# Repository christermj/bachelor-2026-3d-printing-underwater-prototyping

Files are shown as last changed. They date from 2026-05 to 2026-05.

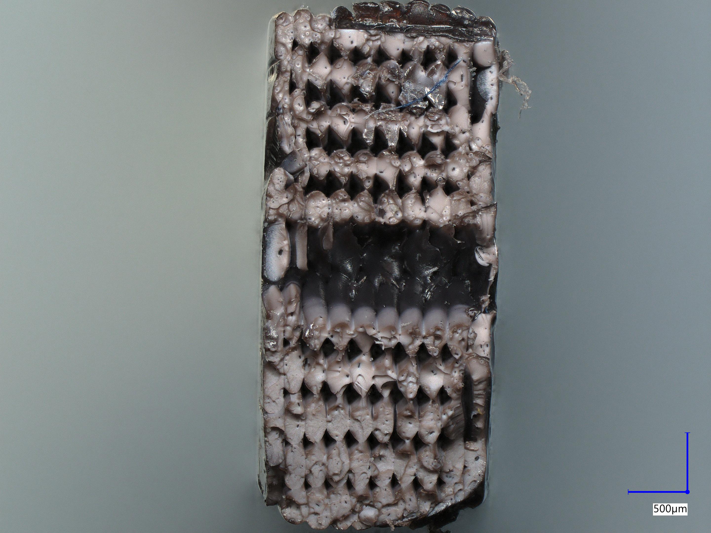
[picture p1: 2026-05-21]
figurer/mikroskopi/ASA 005.jpg

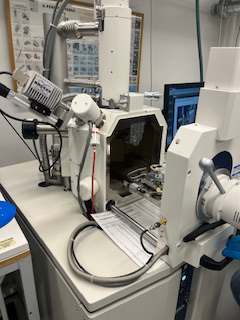
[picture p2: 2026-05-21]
figurer/ekstra/Mikroskopering 6.jpeg

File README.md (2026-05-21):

# Bachelor Oppgave 2026: 3D-Printing i Undervannsmiljøer

## 📚 En helhetlig studie av 3D-printet prototyping for bruk i undervannsmiljøer

**Hovedoppgaven:** [`Bachelor Maskiningeniør 2026.pdf`](./rapport/Bachelor%20Maskiningeni%C3%B8r%202026.pdf)

---

## 👥 Forfattere

- Christer Markussen Jusnes
- Tor Henrik Lehne
- Veronika Hesle
- Emilie Enerhaugen Thrane
- Jonatan Graff Ravnvik

## 🎓 Veiledere

- Karl Thomas Hjelmervik
- Agne Johannessen

## 🤝 Faglig oppfølging & Samarbeid

- **Kongsberg Discovery AS**
  - Robin Heggelund
  - Robert Kovacs

## 🏛️ Institusjon

**Universitetet i Sørøst-Norge (USN)**
- Fakultet for teknologi, naturvitenskap og maritime fag
- Institutt for mikrosystemer

---

## 📋 Abstrakt

Bacheloroppgaven undersøker hvordan FDM-printede polymerer påvirkes av langtidseksponering i saltvann, og hvordan enkle overflatebehandlinger kan redusere vanninntrengning i 3D-printede undervannskapslinger. PLA, PETG og ASA ble testet gjennom strekkprøving, vannopptaksmåling, Arrhenius-analyse, kompresjonstester, overflatebehandling og mikroskopi. Arbeidet er knyttet til utvikling av en 3D-printet elektronikkapsling for undervannsbruk i samarbeid med Kongsberg Discovery AS.

---

## 🔬 Hovedfunn & Resultater

| Funn | Detaljer |
|---|---|
| **ASA - Best materiale** | ASA var det mest stabile materialet ved saltvannseksponering og anbefales som førstevalgsmateriale for videre prototyping i undervannsmiljøer. |
| **PLA degradering** | PLA viste betydelig hydrolytisk degradering og vurderes som lite egnet for marin bruk uten beskyttelse. |
| **PETG kompleks respons** | PETG viste en mer sammensatt respons, med tegn til både degradering og forbedrede mekaniske egenskaper ved høyere temperaturer. |
| **Materialsranking** | Ubehandlede materialer rangert som: **ASA > PETG > PLA** |
| **Termisk glødeeffekt** | Eksponering nær glasstransisjonstemperaturen kan gi en termisk glødeeffekt som forbedrer mekaniske egenskaper, særlig for PETG og ASA. |
| **Best overflatebehandling** | Jotun Vinyl Primer ga best resultat blant overflatebehandlingene, med **0 % masseøkning** i nedsenkningstest. |
| **Tetningskriteria** | Jevn overflatefinish og god pakningskontakt ble vurdert som avgjørende for tetning under hydrostatisk trykk. |
| **Prototypekapsling** | En FDM-printet prototypekapsling ble utviklet som konseptdemonstrator. |

---

## 📁 Filstruktur

```
.
├── README.md                           # Denne filen
├── rapport/Bachelor Maskiningeniør 2026.pdf
│   └── 
├── vedlegg/
│   ├── Vedlegg 1 - Strekkdata grafvedlegg.pdf
│   ├── Vedlegg 2 - Intervju med Olav Håskjold.pdf
│   ├── Vedlegg 3 - Intervju med Magnus Hesle.pdf
│   ├── Vedlegg 4 - Budsjett.pdf
│   └── Vedlegg_strekkmaskin-hastighet_v2.docx
├── data/
│   ├── filament-datablader/
│   │   ├── PLA-datasheet.pdf
│   │   ├── PETG-datasheet.pdf
│   │   └── ASA-datasheet.pdf
│   ├── ekstra/
│   │   ├── Beskrivelse av gjennomføring av veiing.docx
│   │   ├── Beskrivelse av strekktest og registrering av resultater.docx
│   │   ├── Liste over hva vi ser etter under mikroskopering.docx
│   │   ├── Møtereferat Magnus Hesle.docx
│   │   └──  Møtereferat Olav Håskjold.docx
│   ├── Gjennomsnitt strekkprøver.xlsx
│   ├── Vannopptak - masseendring over tid - Tabeller (Diagrammer for vektendring, permanent vektendring og prosentberegning).xlsx
│   ├── arrhenius_graph_endelig_versjon.xlsx
│   └── Lakkering.xlsx
├── figurer/
│   ├── mikroskopi/                     # Mikroskopibilder
│   └── illustrasjoner/                 # Andre bilder og illustrasjoner
└── cad/
    ├── prototypekapsling/              # 3D-modeller av kapslingen
    ├── strekkprøver/                   # 3D-modeller av strekkprøvene
    └── tegninger/                      # 2D tekniske tegninger
```

---

## 📂 Mapper

### 📄 [`rapport/`](./rapport/)
Hovedoppgaven i fullt format

### 📎 [`vedlegg/`](./vedlegg/)
Alle vedlegg til oppgaven:
- Strekkdata grafer (PDF)
- Intervjuer
- Budsjett

### 📊 [`data/`](./data/)
Rådata og datasett:
- **`filament-datablader/`** - Datablader fra produsenter for PLA, PETG og ASA
- **`ekstra/`** - Datafiler som er omarbeidet, strukturert eller brukt som grunnlag
- Strekkprøvedata (gjennomsnitt)
- Lakkerings-data

### 🖼️ [`figurer/`](./figurer/)
Supplerende visuell dokumentasjon fra prosjektet, for eksempel mikroskopibilder og prosjektbilder som ikke nødvendigvis inngår direkte i hovedrapporten

### 🏗️ [`cad/`](./cad/)
CAD-modeller og tekniske tegninger

---

## 🔬 Metodologi

Oppgaven undersøker:
- **FDM 3D-printing** av polymerer
- **Materialer testert**: PLA, PETG, ASA
- **Tester utført**:
  - Strekkprøving
  - Vannopptaksmåling
  - Arrhenius-analyse
  - Kompresjonstester
  - Overflatebehandlinger
  - Mikroskopi
- **Miljø**: Saltvannseksponering (marin miljø)

---

## 🎯 Konklusjon

ASA anbefales som førstevalgsmateriale for ubehandlede 3D-printede undervannsprototyper. Overflatebehandling med Jotun Vinyl Primer viste lovende resultater for ytterligere beskyttelse. PETG kan brukes der duktilitet og enkel produksjon prioriteres. PLA anbefales ikke for langvarig eksponering i saltvann.

---

## 📧 Kontakt

**Forfattere:**
- Christer Markussen Jusnes - christermj@live.no
- Tor Henrik Lehne - thlehne@gmail.com
- Veronika Hesle - veronikahesle@gmail.com
- Emilie Enerhaugen Thrane - emiliethra98@hotmail.com
- Jonatan Graff Ravnvik - jonatan.graff@outlook.com

---

## 📅 Dato

**2026**

---

*Sist oppdatert: 2026-05-19*

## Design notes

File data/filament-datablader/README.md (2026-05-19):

# Filament datablader
Datablader fra 3D filamentprodusenter for PLA, PETG og ASA

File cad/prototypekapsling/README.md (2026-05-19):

# Prototypekapsling folder
CAD-modeller av prototypekapslingen

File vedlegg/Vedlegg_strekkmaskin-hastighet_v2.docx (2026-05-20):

# Vedlegg – Oppsett av strekkprøve maskin

Formålet med disse innledende testene er å identifisere og redusere potensielle problemer i strekkprøveoppsettet før de endelige og begrensede hovedtestene gjennomføres. Siden vi kun har et fastsatt antall prøver tilgjengelig til selve hovedforsøket, er det viktig å bruke fortestene til å avdekke feilkilder, vurdere hvordan materialene reagerer ved ulike hastigheter, og sikre at både testoppsett og prosedyrer fungerer som de skal.

Disse fortestene er derfor planlagt som en utforskende fase hvor vi tester ulike hastigheter, observerer bruddmekanismer og vurderer om testoppsettet gir pålitelige og representative resultater. Målet er å stå igjen med et robust oppsett og et begrunnet valg av strekkhastigheter før vi går videre til de faktiske testene som danner grunnlaget for resultatene i bacheloroppgaven.

Test 1

5 mm/min

PLA | PETG | ASA

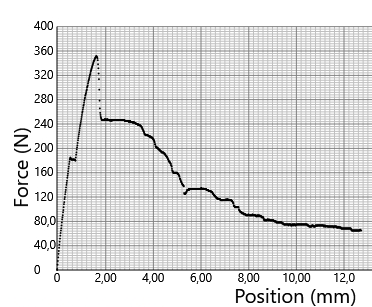
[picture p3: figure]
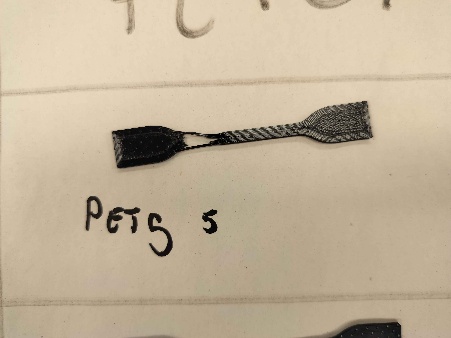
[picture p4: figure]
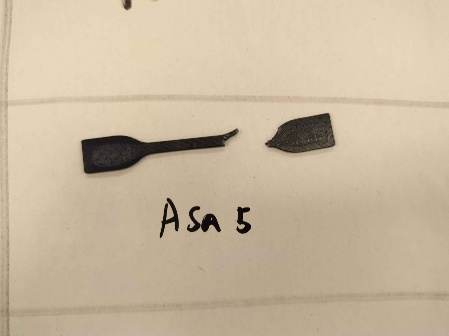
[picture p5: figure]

Ved 5 mm/min viser alle tre materialene tydelig viskoelastisk flyt, noe som resulterer i svært lang forlengelse etter brudd, spesielt for PETG. Den lave hastigheten gir polymerkjeder god tid til å reorganisere seg og gli, noe som fører til en utydelig brudddefinisjon og betydelig plastisk deformasjon. Bruddflatene viser dette tydelig: PLA får et sprøtt og ujevnt brudd, PETG viser kraftig fibrillering og trådtrekk, og ASA viser en blanding av duktil og sprø oppførsel. Resultatene er veiledende siden kun én prøve per materiale ble testet.

25 mm/min

PLA | PETG | ASA

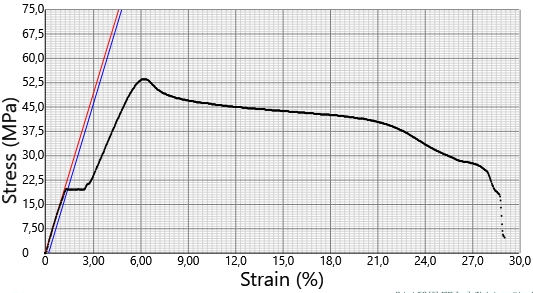
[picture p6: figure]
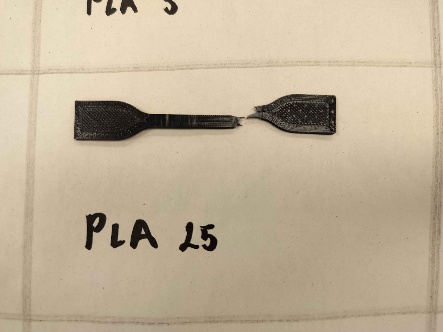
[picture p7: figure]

Ved 25 mm/min reduseres den viskoelastiske flyten noe, men alle materialene viser fortsatt en markert post-yield-region. PLA får en mer definert overgang til brudd, PETG viser fortsatt betydelig kjedeutretting og en flat flytesone, mens ASA viser en mer kontrollert og gradvis deformasjon. Bruddflatene blir noe renere enn ved 5 mm/min, men PETG har fortsatt tydelig fibrillering. Dette understreker at lavere hastigheter gir polymerene tid til å reorganisere seg under belastning. Resultatene er veiledende og basert på én prøve per materiale.

50 mm/min

PLA | PETG | ASA

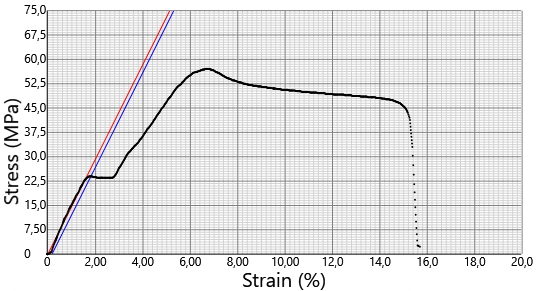
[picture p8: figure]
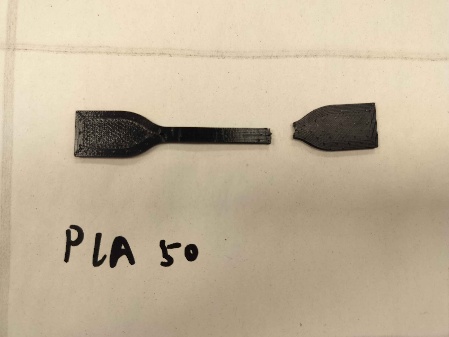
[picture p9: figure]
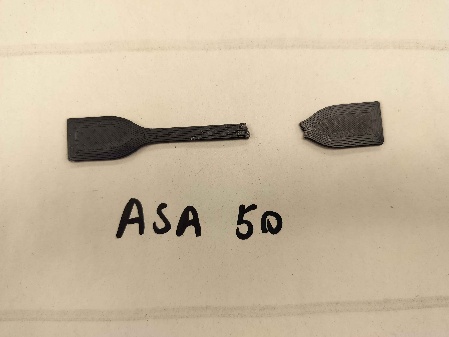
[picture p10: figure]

Ved 50 mm/min oppnås de mest stabile og reproduserbare bruddflatene for alle tre materialene. Stress–strain-kurvene får en tydelig avslutning med klart definert bruddpunkt, og den viskoelastiske flyten er betydelig redusert. PLA viser et rent og sprøtt brudd, PETG får en mer kompakt og mindre fibrillert bruddflate, og ASA viser stabil necking og et homogent brudd. Dette er årsaken til at 50 mm/min ble vurdert som en optimal hastighet for PLA og ASA. Resultatene er veiledende siden kun én prøve per materiale ble testet.

75 mm/min

PLA | PETG | ASA

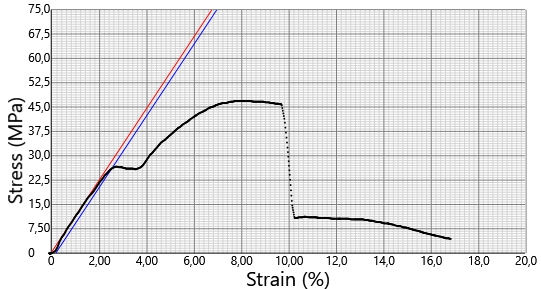
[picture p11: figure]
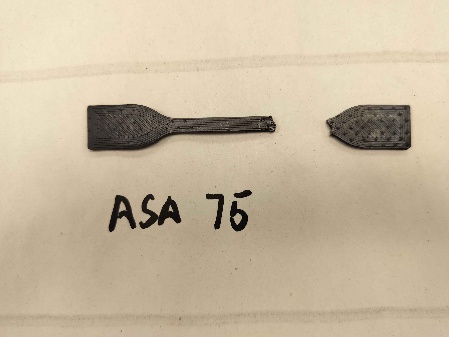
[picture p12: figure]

Ved 75 mm/min viser alle tre materialene en mer markert og konsentrert bruddoppførsel sammenlignet med lavere hastigheter. PLA får et tydelig sprøtt brudd med minimal plastisk deformasjon, PETG viser redusert fibrillering og en mer kompakt bruddflate, og ASA viser stabil necking med en ren og homogen bruddflate. Den høyere hastigheten begrenser tiden polymerkjeder har til å reorganisere seg, noe som gir et mer definert bruddpunkt og mindre etterflyt i kurvene. Resultatene er veiledende siden kun én prøve per materiale ble testet.

100 mm/min

PLA | PETG | ASA

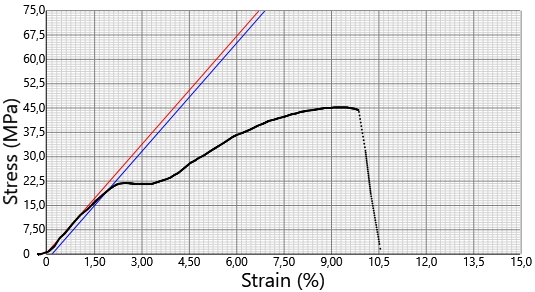
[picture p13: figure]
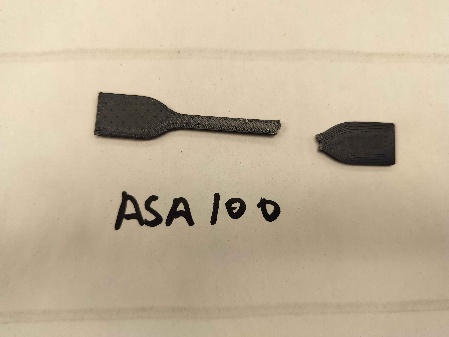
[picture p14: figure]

Ved 100 mm/min oppnår alle materialene et svært tydelig og rent brudd, med minimal viskoelastisk etterflyt. PLA viser et skarpt og sprøtt brudd, PETG får sin mest kompakte og minst fibrillerte bruddflate, og ASA viser en kontrollert necking med et klart definert bruddpunkt. Den høye hastigheten gir en mer “metallisk” kurveprofil med brått fall etter maksimal spenning. Dette understøtter at PETG spesielt responderer positivt på høyere hastigheter når målet er rene bruddflater for mikroskopi. Resultatene er veiledende siden kun én prøve per materiale ble testet.

Oppsummering av Test 1

Test 1 ga en første oversikt over hvordan de tre materialene oppfører seg ved ulike strekkhastigheter, men siden det kun ble testet én prøve per hastighet, var resultatene begrenset i både kvalitet og statistisk verdi. Det som likevel kom tydelig frem, var at de største forskjellene mellom hastighetene oppstod etter brudd, spesielt for PETG, som viste betydelig viskoelastisk etterflyt og fibrillering ved lave hastigheter. Dette gjorde det klart at bruddflatekvalitet måtte vurderes mer systematisk.

I tillegg ble det identifisert en mulig feilkilde knyttet til hvordan prøvene ble holdt fast i strekkmaskinen. Etter diskusjon med Jean Marc ble vi enige om å utvikle en egen jig med formtilpasset uthuling i gripeplatene, slik at bruddet skjer i prøvens midtseksjon og ikke påvirkes av gripetrykk.

Siden Test 1 kun ga grove indikasjoner og ikke et tilstrekkelig grunnlag for å velge endelige hastigheter, ble det besluttet å gjennomføre en ny runde (Test 2) med fokus på bruddflater. Test 2 ble derfor planlagt som et kvalitativt supplement for å se om visuelle forskjeller kunne gi bedre innsikt i hastighetsavhengigheten.

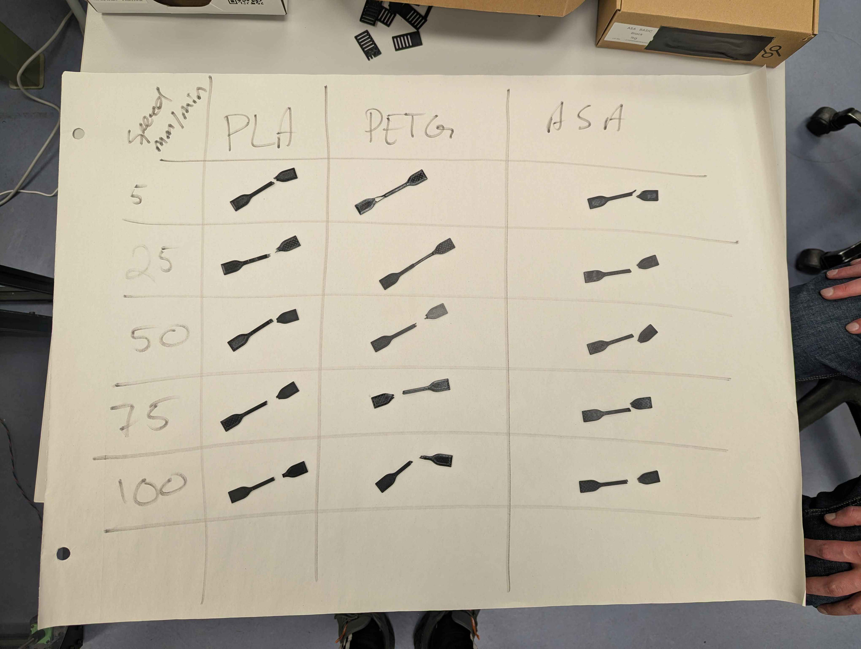
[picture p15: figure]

(BILDE av alle prøvene)

Bilde av potensiell jig (uthuling av plater – ca 1.5mm, som etterlater litt av tykkelsen som stikker ut og gir andre platen et grep mot plasten).

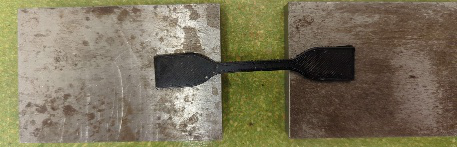
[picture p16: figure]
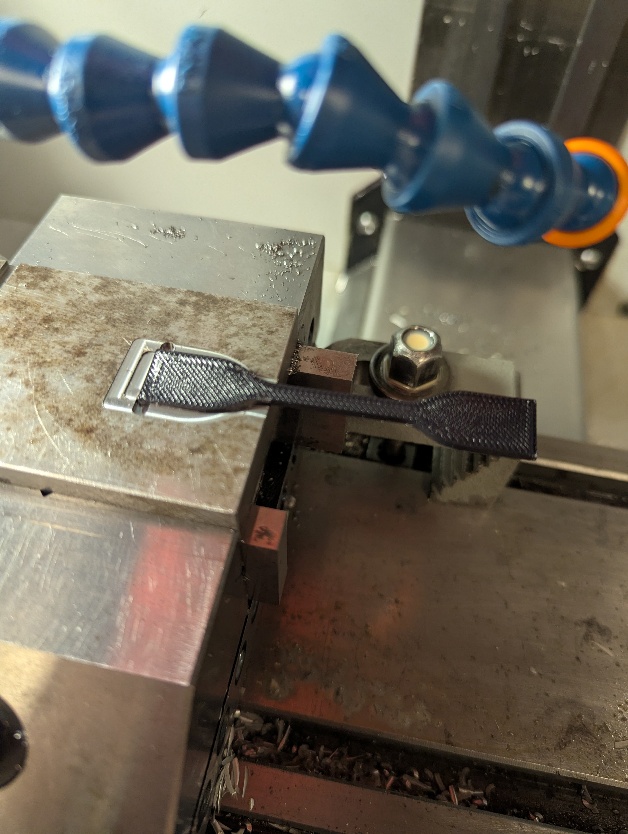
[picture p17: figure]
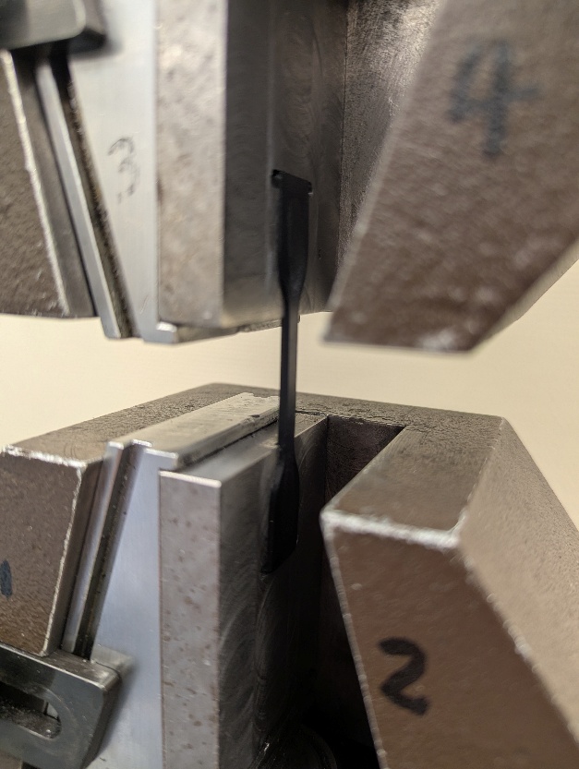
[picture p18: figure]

Strekkprøve test 2

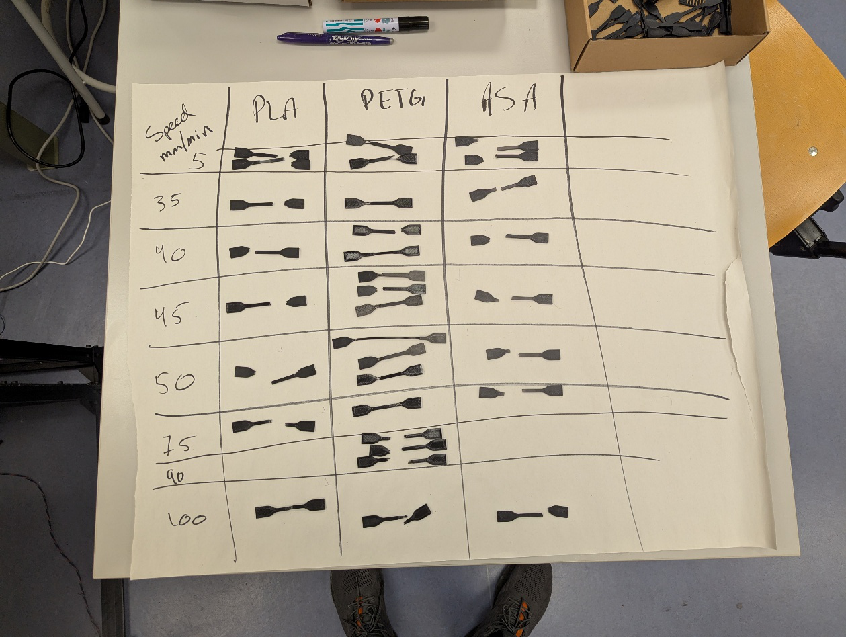
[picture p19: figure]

Test 2 ble gjennomført som en preliminær vurdering av hvordan bruddflater endrer seg med hastighet, med mål om å identifisere hastigheter som gir rene og tolkbare brudd for mikroskopering. Testen ble imidlertid utført med kun én prøve per hastighet og uten tilhørende kraft–forlengelseskurver, noe som gjorde datagrunnlaget svært begrenset. I praksis fungerte Test 2 derfor mer som en orienterende “tulletest” enn som en fullverdig del av kalibreringsprosessen.

Det som likevel ble tydelig, var at PETG oppfører seg langt mer seigt enn PLA og ASA, og at dette materialet ikke utvikler et rent brudd ved lave hastigheter. Dette styrket mistanken om at hvert materiale kunne trenge sin egen optimale testhastighet.

Strekkprøve test 3

På dette tidspunktet ble det funnet en kilde som refererte til ISO 527‑2, hvor standardhastigheten for strekkprøving av polymerer er oppgitt som 10 mm/min ± 25 %. Dette ga et nytt og mer presist rammeverk for videre testing. I stedet for å fortsette med enkeltprøver ved vilkårlige hastigheter, ble det derfor besluttet å gjennomføre Test 3 med fem hastigheter innenfor ISO‑området: 7.5, 8.25, 10, 11.25 og 11.5 mm/min. Målet med Test 3 var å undersøke om dette standardområdet gir mer konsistente kurver og bruddflater, og om ISO‑hastigheten kan fungere som et felles referansepunkt for alle tre materialene.

Test 3 representerer dermed det første forsøket på en strukturert og ISO‑forankret kalibrering av strekkhastighet, og danner grunnlaget for å vurdere om videre testing bør baseres på standardhastigheten eller om hvert materiale krever sin egen optimale hastighet.

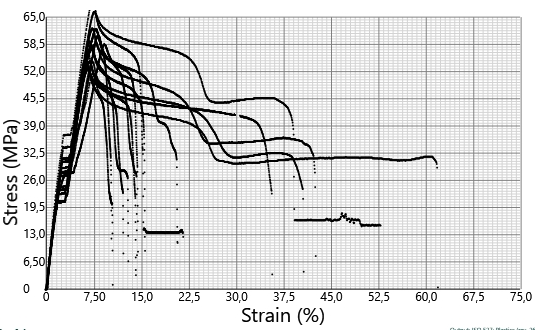
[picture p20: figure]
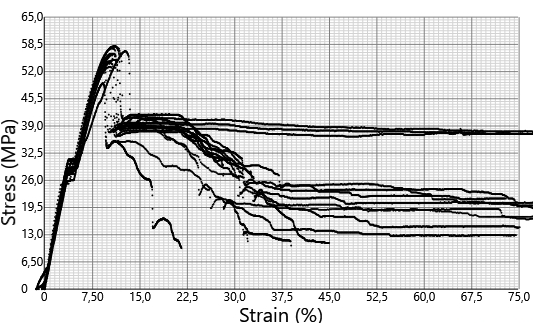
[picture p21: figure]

PLA – 7,5 – 12,5 mm/min | PETG – 7,5 – 12,5 mm/min | ASA – 7,5 – 12,5 mm/min

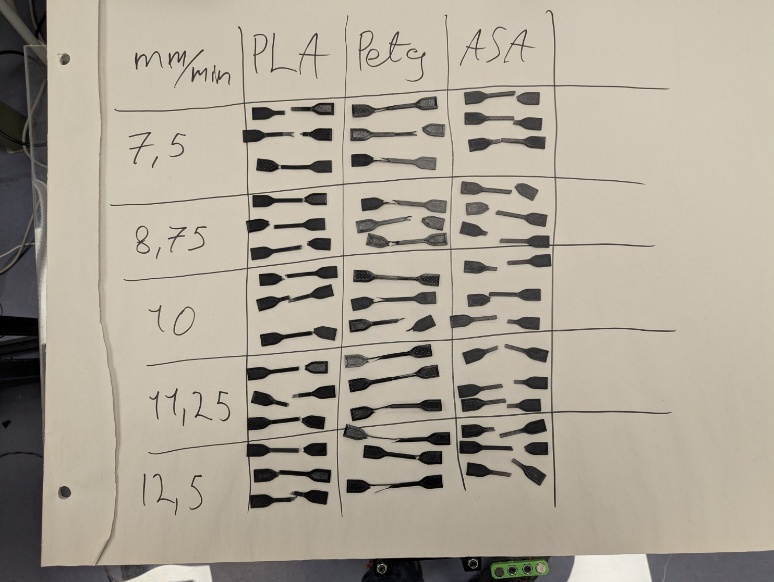
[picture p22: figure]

Bilde av alle strekkprøvene fra test 3

Test 4

Test 4 ble gjennomført for å undersøke hvordan materialene oppfører seg ved et bredere spekter av strekkhastigheter enn det som ble testet i Test 3. Etter Test 3 ble det gjort en nærmere gjennomgang av ISO 527, og det viste seg at standarden ikke angir konkrete hastigheter, men heller beskriver at seige materialer kan strekkes ved høyere hastigheter enn mer sprø materialer som PLA. Dette åpnet for at optimale hastigheter kunne ligge betydelig høyere enn området som ble undersøkt i Test 3.

På bakgrunn av dette ble Test 4 designet for å gradvis øke hastigheten fra 10 mm/min og opp til 90 mm/min, for å kartlegge hvordan PLA, PETG og ASA responderer på høyere belastningshastigheter. Målet var å identifisere hvilke hastigheter som gir stabile og reproduserbare kurver, tydelige bruddpunkter og bruddflater som er egnet for videre mikroskopisk analyse. Som i Test 3 ble det gjennomført tre prøver per hastighet per materiale, slik at resultatene kunne vurderes med tilstrekkelig pålitelighet.

Test 4 representerer dermed den siste og mest omfattende delen av kalibreringsarbeidet, og danner grunnlaget for å fastsette de endelige strekkhastighetene som brukes i hoved forsøket.

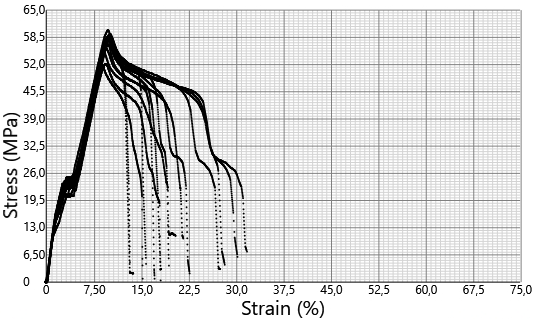
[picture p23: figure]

| PLA – alle hastigheter

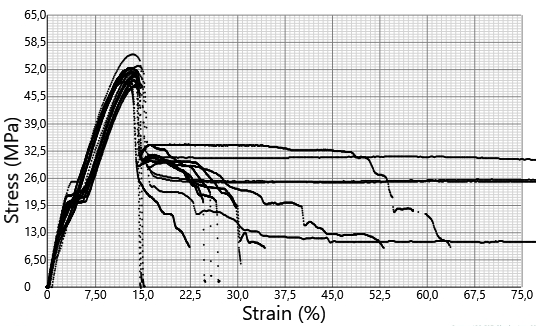
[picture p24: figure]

| PETG – alle hastigheter

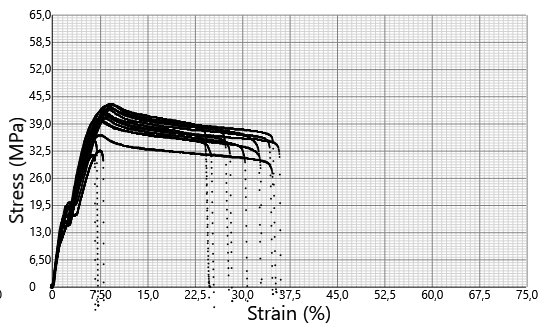
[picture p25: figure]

| ASA – alle hastigheter

Graf 1 er av alle PLA prøver i forskjellige hastigheter som viser at hastigheten ikke har noe å si for e-modulen og maks kraft, kurven ser lik ut.

GRAF 1 – første prototype som startet det hele

Graf 2 viser alle PETG prøvene som viser samme som graf 1.

GRAF 2 – jalla prøver som gav ideen videre

Graf 3 viser like resultater som graf 1 og 2.

GRAF 3 – ISO 527 hastigheter

Konklusjonen fra dette er at hastighet ikke påvirker resultatene, som vil gi oss spillerom å leke med forskjellige hastigheter for å fremkalle «pene brudd» som kan brukes i mikroskopering. Hvis vi ser på test 1 og test 2 vil dette også vise at det er like resultater som ikke er avhengig av hastigheten. Dermed kan vi bruke for eksempel 100mm/min for petg, 45 mm/min for PLA og 50 mm/min for ASA – dette bestemmes etter en nærmere test 4 som tar flere prøver for å forsikre at bruddene er «penest» rundt disse tallene.

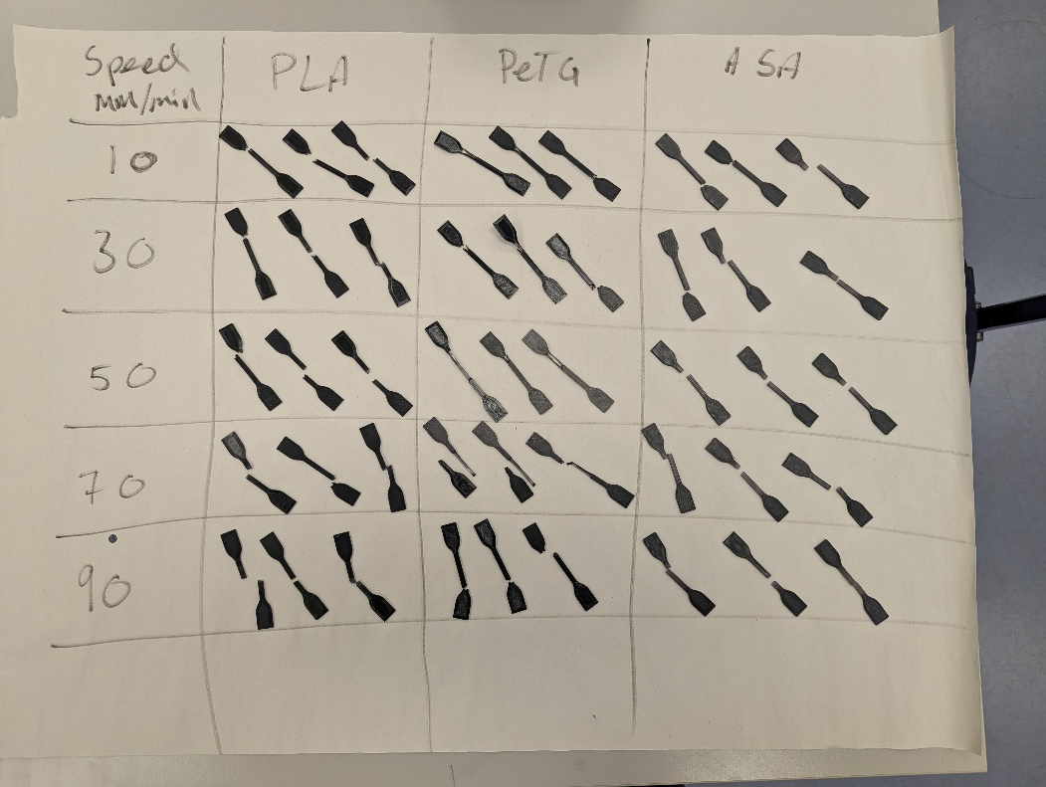
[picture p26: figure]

Test 4 brudd

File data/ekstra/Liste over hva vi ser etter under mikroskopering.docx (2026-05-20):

Overflaterelaterte endringer

Saltrester / krystaller

- Hvite eller kantete avleiringer på overflaten
- Krystaller i porer eller langs laggrenser
- Viktig: må skille mellom faktisk inntrengning og rester etter tørking

Overflateerosjon

- Ruere overflate enn før eksponering
- Matthet / tap av glatt struktur
- Små groper eller mikrodefekter

Endringer i lagstruktur (3D-printet materiale)

- Åpning mellom printlag
- Delaminering
- Økt synlig porøsitet
- Svekket filamentfusjon

Dette kan indikere vanninntrengning eller hydrolytisk svekkelse.

Endringer i bruddflate (etter strekkprøve)

- Mer sprøtt brudd (glatt, skarp flate)
- Mer duktilt brudd (trekkede fibrer, plastisk deformasjon)
- Økt porøsitet i bruddflaten
- Luftlommer som har vokst

Hvis materialet er degradert kan bruddet bli:

- Mer porøst
- Mindre sammenhengende
- Mindre plastisk deformasjon

Intern struktur

- Nye mikrosprekker
- Utvidede eksisterende porer
- Luftlommer som har blitt større
- Kapillærbaner for vanninntrengning

Hva vi vurderer

- Vanninntrengning
- Hydrolytisk nedbrytning
- Svekket lagbinding
- Økt porøsitet
- Endret bruddoppførsel

Analysere prøve i mikroskop:


1 og 2: Se på bruddflater.

3: Lagstruktur, evt. saltpartikler og overflate. Punkt 3 skal sees fra side og ovenfra under mikroskopering.

Prøve ID | Materiale | Temperatur (°C) | Våt/tørr prøve | Overflaterelaterte endringer | Endringer i bruddflate | Intern struktur | Kommentar

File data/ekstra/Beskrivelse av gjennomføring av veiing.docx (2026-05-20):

Beskrivelse av veiing og gjennomføring (Strekktest – vekt)

1) Prøve-ID og inndeling

Hver holder inneholder fem (5) strekkprøver og identifiseres med en Prøve-ID på format:

[Bokstav] – [Temperaturkode] – [Løpenummer]

- Bokstav (materiale): A = PLA, B = PETG, C = ASA
- Temperaturkode (vannbad): 1 = 20 °C, 2 = 40 °C, 3 = 60 °C
- Løpenummer: teller holderne innen samme materiale/temperatur (f.eks. A-1-1, A-1-2, A-1-3 …)

Oddetalls-holdere (…-…-1, …-…-3, …) veies i tre trinn:

1. Startvekt (tørr) før nedsenking
2. Sluttvekt (våt) ved første uttak fra vann
3. Tørrvekt etter 24 t tørk

Partalls-holdere (…-…-2, …-…-4, …) veies normalt uten tørrvekt etter 24 t (kun startvekt + sluttvekt).

2) Holderoppsett og spor-rekkefølge (kritisk for sporbarhet)

Holderen er en flat plate med Prøve-ID på den ene enden og 5 spor der prøvene presses inn.

For å sikre at hver prøve kan spores mellom målinger:

- Spor 1 = prøven som står nærmest Prøve-ID-merkingen
- Deretter fylles spor 2 → spor 5 i rekkefølge bort fra ID-enden.
- Ved veiing følges alltid samme rekkefølge (spor 1 til 5), og verdiene føres i Excel i samme rekkefølge (øverste rad = spor 1, neste rad = spor 2, osv., for den aktuelle Prøve-ID-en).

3) Forberedelser før veiing

- Vekt plasseres stabilt og i trekkfritt miljø.
- Bruk hansker/pinsett for å unngå fett og fukt fra fingre.
- Sørg for at Prøve-ID på holder og vannbad er tydelig merket.

4) Startveiing (tørr vekt før nedsenking)

1. Ta en holder (f.eks. A-1-1) og vei prøvene enkeltvis i rekkefølge spor 1 → spor 5.
2. Før verdiene inn i arket under riktig materiale og temperatur, i kolonnen Startvekt for riktig Prøve-ID.
3. Gjenta for alle holdere som skal legges i vann.

5) Uttak og våtveiing (Sluttvekt)

Når en holder tas opp for måling:

1. Ta opp holderen og la den renne av saltvannet. Prøvene skylles av med rent vann, før de tørkes lett av med tørkepapir.
2. Vei prøvene enkeltvis i rekkefølge spor 1 → spor 5.
3. Før verdiene i kolonnen Sluttvekt for aktuell Prøve-ID, og fyll inn Dato for målepunktet.
4. Sett prøven tilbake i sporet den sto i.

6) Tørking 24 timer og tørrvekt (kun oddetalls-holdere)

For holdere med oddetalls-ID:

1. Etter våtveiing legges prøvene til tørk i et døgn under like forhold for alle. Samme sted/rom, ikke direkte sol, mest mulig lik ventilasjon).
2. Etter et døgn veies prøvene igjen i rekkefølge spor 1 → spor 5.
3. Før verdiene i kolonnen Tørrvekt.

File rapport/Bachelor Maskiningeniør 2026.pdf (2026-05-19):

# En helhetlig studie av 3D-printet prototyping

### Bacheloroppgave

Classification: Internal; TS3000 20 studiepoeng Maskiningeniør – Produktdesign (ING6); Veiledere:

for bruk i undervannsmiljøer

Veronika Hesle, Christer Markussen Jusnes, Tor Henrik Lehne,
Emilie Enerhaugen Thrane, Jonatan Graff Ravnvik

Fakultet for teknologi, naturvitenskap og maritime fag
Institutt for mikrosystemer

Karl Thomas Hjelmervik
Agne Johannessen

Samarbeid med tverrfaglig gruppe – Elektroingeniør (ING3) / Elektronikkingeniør (ING4)

### Sammendrag

Denne bacheloroppgaven undersøker hvordan 3D-printede polymerkomponenter kan brukes i utvikling av prototyper for undervannsmiljøer. Arbeidet er gjennomført i samarbeid med Kongsberg Discovery AS og tar utgangspunkt i behovet for en kapsling som kan beskytte elektronikk for undervannskommunikasjon. Oppgaven omfatter både materialtesting, vurdering av vanninntrengning, overflatebehandling, trykkrelaterte tester og utvikling av en demonstrasjonsprototype for integrering av elektronikk.

Tre filamentbaserte polymermaterialer ble undersøkt: polylaktid/polymelkesyre (PLA), glykolmodifisert polyetylentereftalat (PETG) og akrylnitril-styren-akrylat (ASA). Materialene ble eksponert i kunstig saltvann ved 20, 40 og 60 °C over en periode på opptil tolv uker. Endringer i mekaniske egenskaper ble vurdert gjennom strekkprøving, vannopptaksmålinger og mikroskopi. I tillegg ble det gjennomført en forenklet Arrhenius-analyse for å undersøke temperaturavhengige endringer i materialenes elastisitetsmodul.

Resultatene viser at PLA er mest følsomt for kombinasjonen av saltvann og forhøyet temperatur. Ved 60 °C viste materialet tydelige tegn til degradering og tap av mekaniske egenskaper. PETG viste en mer sammensatt respons, med større variasjon mellom våte og tørre prøver. ASA fremstod som det mest stabile av de tre materialene under de testede betingelsene, med relativt lavt vannopptak og begrensede endringer i mekanisk respons. Mikroskopi støttet disse observasjonene ved å vise tydelige skader og saltavsetninger i enkelte PLA-prøver, mens ASA i hovedsak beholdt en mer stabil struktur.

Det ble også undersøkt hvordan ulike overflatebehandlinger påvirker vanninntrengning i 3D-printede strukturer. Bengalack, to-komponent polyester og Jotun Vinyl Primer ble testet gjennom nedsenkning og trykkrelaterte forsøk. Resultatene indikerer at overflatebehandling kan redusere vanninntrengning, men at tetningsevnen i stor grad avhenger av overflatekvalitet, jevn påføring, pakningskontakt og geometrisk presisjon. Testene viser derfor at belegg alene ikke kan vurderes isolert, men må ses i sammenheng med design av pakningsflater og produksjonskvalitet.

Basert på material- og tettingstestene ble det utviklet en sylindrisk kapsling med et indre bæresystem for batteri og elektronikk. Prototypen fungerer som et konsept for hvordan 3D-printing kan brukes til rask utvikling og tilpasning av undervannsteknologi. Den endelige prototypen ble ikke fullskala trykktestet som ferdig system, og resultatene må derfor tolkes som et grunnlag for videre utvikling, ikke som en ferdig kvalifisert undervannskapsling.

Oppgaven konkluderer med at 3D-printing har tydelig verdi som metode for rask prototyping av undervannskomponenter, men at materialvalg, lagstruktur, overflatebehandling og tetningsdesign er avgjørende for funksjon over tid. ASA fremstår som det mest egnede materialet av de undersøkte alternativene, mens PETG kan være relevant i enkelte bruksområder. PLA vurderes som lite egnet for langvarig eksponering i saltvann, særlig ved forhøyet temperatur. Videre arbeid bør omfatte lengre eksponeringstid, flere trykktester, bedre kontrollert overflatebehandling og fullskala testing av ferdig kapsling under realistiske driftsforhold.

### Forord

Denne bacheloroppgaven er utført våren 2026 ved Institutt for mikrosystemer, Fakultet for teknologi, naturvitenskap og maritime fag, Universitetet i Sørøst-Norge (USN). Oppgaven er gjennomført som del av bachelorprogrammet i ingeniørfag, med Kongsberg Discovery AS som ekstern oppdragsgiver.

Vi retter en særlig takk til våre veiledere, Karl Thomas Hjelmervik og Agne Johannessen, for faglig veiledning, oppfølging og konstruktive tilbakemeldinger gjennom prosjektperioden. Kongsberg Discovery AS takkes for oppdraget, tilgang til informasjon om cNode Mantis-systemet og praktisk tilrettelegging. Vi vil spesielt trekke frem Robin Heggelund og Robert Kovacs ved Kongsberg Discovery for faglige innspill og oppfølging underveis.

Videre ønsker vi å anerkjenne bidragene fra John Inge Waage og laboratorietekniker Hans Bjørge Normann for praktisk bistand med mikroskopi og trykktesting. Jean-Marc Cantin, Truls Arne Frednes, Zekija Ramic og Geir Bjørnsen ved USN har også bidratt med verdifulle faglige innspill og støtte gjennom prosjektet. Håvard Granlund og Petter Andreassen ved Jotun AS takkes for faglige råd og materialstøtte knyttet til overflatebehandlinger.

Prosjektet er gjennomført i samarbeid med en tverrfaglig bachelorgruppe med ansvar for utvikling av kretskort, sensorsystem og tilhørende elektronikk. Samarbeidet har vært viktig for å sikre at mekanisk design, elektronikk og systemintegrasjon ble utviklet i sammenheng.

Arbeidet med oppgaven har gitt gruppen verdifull erfaring innen materialtesting, prototypeutvikling, tverrfaglig samarbeid og vitenskapelig rapportering.

Horten, Mai 2026

Signatur Veronika Hesle | Signatur Jonatan Graff Ravnvik | Signatur Emilie Thrane
Signatur Tor Henrik Lehne | Signatur Christer Markussen Jusnes

### Ordliste og forkortelser

FORKORTELSE | BETYDNING
ASA | Acrylonitrile Styrene Acrylate
DAK | Dataassistert Konstruksjon
FDM | Fused Deposition Modeling
FFI | Forsvarets forskningsinstitutt
IEEE | Institute of Electrical and Electronics Engineers
ISO | International Organization for Standardization
PCB | Printed Circuit Board (kretskort)
PDM | Product Data Management
PETG | Polyethylene Terephthalate Glycol-modified
PLA | Polylactic Acid (polymelkesyre)
SEM | Scanning Electron Microscopy
USN | Universitetet i Sørøst-Norge
UV | Ultrafiolett (stråling)
ABS | Acrylonitrile Butadiene Styrene (akrylnitril-butadien-styren)
NaCl | Natriumklorid (kjemisk forbindelse brukt for å fremstille kunstig sjøvann)
NBR | Nitrilgummi (nitrile butadiene rubber)

### Begreper og definisjoner

BEGREP | DEFINISJON
Anisotropi | Materialegenskaper som varierer med retning. FDM-printede deler er typisk sterkere i XY-planet enn i Z-retningen.
Gløding (annealing) | Termisk etterbehandling under glasstransisjonstem- peraturen som gir polymerkjedene mobilitet til å omorganisere seg, øke krystallinitet og forbedre la- ginterdiffusjon.
Belegg (coating) | Overflatebehandling som hindrer eller reduserer dif- fusjon av vann og ioner inn i underliggende materi- ale.
Bruddflate | Overflaten som oppstår når et prøvestykke brytes. Analyseres for å vurdere bruddtype (sprø, duktil).
C-node Mantis | Akustisk modem fra Kongsberg Discovery for trådløs kommunikasjon under vann.
Tverrbjelke | Den bevegelige tverrbjelken på en strekkmaskin som påfører kraft på prøven.
Duktil brudd | Brudd forut av plastisk deformasjon og innsnevring. Materialet flyter før det sprekker.
Ekstensometer | Instrument som måler tøyning direkte på prøvestyk- ket. Ikke benyttet i dette prosjektet; tverrbjelkebe- vegelse benyttes i stedet.
Elastisitetsmodul | Stigningstallet for den elastiske delen av spennings- tøyningskurven, mål på materialets stivhet.
Tøyning | Prosentvis forlengelse ved brudd, mål på materialets duktilitet.
FDM-printing | Filamentbasert additiv tilvirkning der termoplastisk materiale ekstruderes lag for lag.
Fibrillering | Dannelse av fibre og tråder i bruddflaten, særlig ka- rakteristisk for PETG under strekk.
Flytespenning | Spenningsnivået der materialet begynner å defor- meres plastisk, ofte definert ved 0,2 % plastisk tøy- ning.
Glasstransisjonstemperatur | Temperaturen der amorfe polymerer går fra glass- aktig til gummiaktig tilstand.
Hydrolyse | Kjemisk nedbrytning av polymerkjeder ved reaksjon med vann, særlig relevant for ester-baserte polyme- rer som PLA.
Lagbinding | Binding mellom printlag i FDM-deler. Svakere enn bulkmaterialet og en sentral feilkilde.

Isobart trykk | Belastning der trykket virker likt på alle eksterne fla- ter, slik som i en trykkbeholder.
Innsnevring | Lokal innsnevring av prøvegeometrien etter flyt og før brudd.
Plastisering | Reduksjon av stivhet og flytespenning som følge av at små molekyler (typisk vann) trenger inn i polymer- strukturen og øker kjedemobiliteten.
Semikrystallinsk | Polymer med blanding av ordnede (krystallinske) og uordnede (amorfe) kjedestrukturer.
Tøyningshastighet | Tøyningshastighet under mekanisk test. Påvirker mekanisk respons i viskoelastiske materialer.
Strekkfasthet | Maksimal spenning materialet tåler i strekk før brudd.
Trykkbeholder | Lukket konstruksjon beregnet for å motstå indre el- ler ytre overtrykk.
Viskoelastisitet | Material atferd som kombinerer elastisk og viskøs respons, tidsavhengig deformasjon.
Spraylakk | Aerosol-applisert beskyttelseslakk basert på akryl- harpiks.
To-komponent polyester | Belegg som herdes ved kjemisk reaksjon mellom herder og base.
Jotun Vinyl Primer | Vinyl-basert grunning beregnet for marin bruk.
Akselerert aldring | Forsøksmetode der forhøyet temperatur brukes til å simulere langtidseksponering på kortere tid, basert på Arrhenius-prinsippet.
Aktiveringsenergi | Minimumsenergien som kreves for å starte en kje- misk reaksjon. I Arrhenius-modellen beskriver (Ea) temperaturavhengigheten til degraderingshastighe- ten.
Arrhenius-modellen | Kinetisk modell som beskriver sammenhengen mel- lom reaksjonshastighet og temperatur gjennom ak- tiveringsenergien.
Eksentrisk kompresjon | Ujevn trykkfordeling som oppstår når en pakning be- lastes mot en ujevn overflate, og som kan føre til lek- kasje.
Hydrostatisk trykk | Trykk forårsaket av en væskes vekt, som virker likt i alle retninger på en neddykket gjenstand.
O-ring | Ringformet pakning med sirkulært tverrsnitt, brukt for å oppnå tett forsegling mellom to flater.
Sprø brudd | Brudd uten vesentlig plastisk deformasjon. Bruddet skjer raskt og med liten energiabsorpsjon.

Warping | Deformasjon som oppstår når en 3D-printet del trek- ker seg sammen under avkjøling, slik at hjørner eller kanter løfter seg fra byggeplaten. Fenomenet skyl- des termiske spenninger i materialet og er særlig vanlig ved temperaturfølsomme materialer som ABS og ASA.
Fyllingsgrad | Infill i veggene på 3d-printede modeller, beskrevet med %
Horizon | Programvaren til Strekkmaskin H50KL
Stepdown-modul | DC/DC converter som gjør om spenningen fra 12 volt til 5 volt
Sensor Shield | Sensor løsningen som ble designet av den tverrfag- lige gruppen
Battery Cradle | Modulen som holder batteriet og Stingray-kortet i designløsningen
PCB Cradle | Modulen som holder elektronikken i designløs- ningen
Enkoder-kort | Kretskortet som tar imot bildesignalet fra kameraet og sender det til stingray-kortet
Stingray | Kretskortet som til Kongsberg Discovery som hånd- terer det trådløse signalet igjennom vann
Breadboard | Koblingsbrett som brukes til å teste og bygge elekt- roniske kretser uten lodding
Wago | En fjærbelastet koblingsklemme som brukes til å koble sammen elektriske ledninger uten lodding

### Symboloversikt

NORSK | ENGELSK | SYMBOL
Flytespenning | Offset yield stress (0.2%) | σy0.2
Strekkfasthet | Ultimate Tensile Strength | σB
Elastisitetsmodul | Elastic Modulus | E
Tøyning | Elongation | ε
Glasstransisjonstemperatur | Glass Transition Temperature | Tg
Aktiveringsenergi | Activation Energy | Ea
Temperatur (absolutt) | Temperature (absolute) | T
Degraderingshastighet | Degradation Rate Constant | k

Hydrostatisk trykk | Hydrostatic Pressure | p
Massetetthet (væske) | Fluid Density | ρ
Gravitasjonsakselerasjon | Gravitational Acceleration | g
Dybde | Depth | ℎ

### Figurliste

Figur 2 – cNode Modem MANTIS i aksjon, som viser akustisk/optisk kommunikasjon mellom

Figur 5 – Prinsippskisse av FDM-prosessen, der en termoplastisk filamenttråd mates gjennom et oppvarmet munnstykke og deponeres lagvis på en oppvarmet byggeplattform. Egenprodusert figur. 7 Figur 6 – Prinsippskisse av amorf og semikrystallinsk polymerstruktur. Egenillustrert, basert på

Figur 15 – Oppsett til varmekammer. a) Oppsett av hvordan prøvene ligger organisert i glassene, b)

Figur 16 – Etter at prøvene ble tatt opp ble de systematisert etter materiale, om prøvene var våte eller

Figur 30 – Røde markeringer viser områdene som skal undersøkes. Punkt 1 og 2 viser bruddflatene, som skal analyseres med fokus på bruddmekanismer og materialstruktur. Punkt 3 undersøkes med

Figur 42 – Understativ for Stepdown modulen. a) Understativ, b) Stepdown modul montert | 51
Figur 43 – Test av festemekanisme | 51
Figur 44 – Battery Cradle | 52
Figur 45 – PCB Cradle. a) Forside av PCV Cradle med spor for encoderkort og step-down-modul, b)
Bakside av PCB Cradle med spor for Sensor Shield | 53
Figur 46 – Lokk. a) Toppen av lokket, b) Undersiden av lokket | 53
Figur 47 – Sylinder | 54
Figur 48 – Sammenstilling Exploded view | 54
Figur 49 – skisser på mulig lufteventilløsning | 55
Figur 50 – skisse av sett skrue for låsing | 56
Figur 51 – skisse av plastsplint for låsing | 56
Figur 52 – Eksploded view med blylodd | 58
Figur 53 – Dykkerklokke | 61
Figur 54 – Klokkereim | 61
Figur 55 – Sensorplassering | 62
Figur 56 – Strekkfasthet (σB) over eksponeringstid for PLA, PETG og ASA i kunstig sjøvann ved 20, 40
og 60 °C. a) tørr tilstand, b) Våt tilstand | 64
Figur 57 – Elastisitetsmodul (E) over eksponeringstid for PLA, PETG og ASA i kunstig sjøvann ved 20, 40
og 60 °C. a) Tørr tilstand, b) Våt tilstand | 64
Figur 58 – Flytespenning (σF) over eksponeringstid for PLA, PETG og ASA i kunstig sjøvann ved 20, 40
og 60 °C. a) Tørr tilstand, b) Våt tilstand | 65
Figur 59 – Prosentvis endring i elastisitetsmodul etter tolv ukers eksponering for prøver | 67
Figur 60 – Prosentvis endring i strekkfasthet etter tolv ukers eksponering for prøver | 67
Figur 61 - Gjennomsnittlig vektendring målt direkte etter eksponering for PLA ved 20 °C, 40 °C og 60 °C
fra uke 3 til uke 12 | 69
Figur 62 – Arrhenius-plott for PLA basert på E-modul etter tre ukers aldring. Plottet viser
temperaturintervallene 20-40 °C og 40-60 °C for våte og tørre prøver | 70
Figur 63 – Arrhenius-plott for PETG basert på E-modul etter tre ukers aldring. Plottet viser
temperaturintervallene 20-40 °C og 40-60 °C for våte og tørre prøver | 71
Figur 64 – Arrhenius-plott for ASA basert på E-modul etter tre ukers aldring. Plottet viser
temperaturintervallene 20-40 °C og 40-60 °C for våte og tørre prøver | 71
Figur 65 – Testresultater for radiell belastning | 73
Figur 66 – Testobjekter etter radiell test | 73
Figur 67 – Testresultater for aksial belastning | 74
Figur 68 – Testobjekter etter aksiell test | 74
Figur 69 – Prosentvis masseøkning for PLA etter én uke i vanneksponering med de ulike
overflatebehandlingene | 75
Figur 70 – Prosentvis masseøkning for PETG etter én uke i vanneksponering med de ulike
overflatebehandlingene | 76
Figur 71 – Prosentvis masseøkning for ASA etter én uke i vanneksponering med de ulike
overflatebehandlingene | 76
Figur 72 – Boks for nedsenkningstest. a) Boks med flat gummipakning, b) Boks med flat
gummikorkpakning, c) Boks med 5 mm O-ring i lokket | 77
Figur 73 – Ubehandlet vannintrengningstest delt i to | 78
Figur 74 – Ujevnheter i overflatebehandling. a) Manglende dekning av overflatebehandling på siden av
lokket, b) Manglende dekning av overflatebehandling på siden av boksen | 78
Figur 75 – kollapset testboks | 79
Figur 76 – Trykkgraf fra trykkammeret for FDM-printet sylinder forseglet med vinylprimer | 80
Figur 77 – Trykkgraf fra trykkammeret for FDM-printet sylinder forseglet med to-komponent polyester.
| 81

Figur 78 – Trykkgraf fra trykkammeret for FDM-printet sylinder forseglet med Bengalack | 81
Figur 79 – PLA ved 60°C i 3 uker, prøven er skylt. Grønne sirkler markerer saltkrystaller. Optisk
mikroskopi hos Kongsberg Discovery | 82
Figur 80 – PLA ved 60°C i tolv uker, prøven er skylt. Grønne sirkler markerer saltkrystaller. Optisk
mikroskopi hos Forskningsparken | 83
Figur 81 – PLA ved 60°C i 3 uker, prøven er skylt. Grønne sirkler markerer saltkrystaller. Optisk
mikroskopi hos Forskningsparken | 83
Figur 82 – PLA ved 40°C i 12 uker, prøven er skylt. Større mengde saltkrystaller observeres mellom printlagene. Grønne sirkler markerer saltkrystaller. Optisk mikroskopi hos Kongsberg Discovery...... 84 Figur 83 – PLA ved 60°C i 3 uker viser printlag med jevne luftrom og lagvis oppbygging med relativt lik
struktur. Optisk mikroskopi ved Forskningsparken | 85
Figur 84 – PLA ved 40°C i tolv uker. Blå markering viser at lagene er tettere og hvite piler viser steder
det er større hulrom mellom printlagene. Optisk mikroskopi ved Kongsberg Discovery | 85
Figur 85 – PLA etter tolv uker ved 60°C. SEM-bilde viser sprekker på overflaten og mellom printlagene. Røde bokser markerer områder som er vist som forstørrede utsnitt. Hvit markering angir områder hvor
det er sprekker. SEM ved Kongsberg Discovery | 86
Figur 86 – PLA etter tolv uker ved 60°C. SEM-bilde viser sprekker på indre struktur og mellom printlagene. Røde bokser markerer områder som er vist som forstørrede utsnitt. Hvit markering angir
ulike sprekkåpninger. Optisk mikroskopi ved Kongsberg Discovery | 86
Figur 87 – PLA etter 3 uker ved 60°C. Viser trinnvise brudd i plasten. Optisk mikroskopi ved
Forskningsparken | 87
Figur 88 – PLA etter tolv uker ved 60°C. Bruddflaten fremstår rettvinklet og jevn. Optisk mikroskopi ved
Kongsberg Discovery | 87
Figur 89 – PLA ved 60°C i tolv uker. Det observeres flere små, sorte plastpartikler i glassbeholderen.
| 88
Figur 90 – PLA etter ni uker ved 60°C. Prøvene viser brudd ved håndtering | 88
Figur 91 – PLA etter tolv uker ved 60°C. Det observeres løse plastpartikler på underlaget Eksempler er
markert med blå sirkel | 88
Figur 92 – PETG etter tre uker ved 60°C (skylt). Grønne markeringer viser saltkorn på overflaten. Optisk
mikroskopi ved Forskningsparken | 89
Figur 93 – PETG etter tolv uker ved 60°C (skylt). Grønne markeringer viser saltkorn på overflaten. Optisk
mikroskopi ved Forskningsparken | 89
Figur 94 – PETG etter tre uker ved 60°C (skylt). Grønne markeringer viser saltkorn i bruddet. Optisk
mikroskopi ved Forskningsparken | 90
Figur 95 – PETG etter tolv uker ved 60°C (skylt). Røde bokser markerer områder som er vist som forstørrede utsnitt. Hvite områder viser saltkorn i bruddet. Optisk mikroskopi ved Forskningsparken.
| 90
Figur 96 – PETG etter tolv uker ved 20°C. Det observeres løse filamenttråder og skader på siden av plastpinnen. Røde firkanter markerer områder som er forstørret i utsnittene. Optisk mikroskopi ved
Forskningsparken | 91
Figur 97 – PETG-prøver eksponert ved 60°C etter strekkprøving ved uke 3, 6, 9 og 12. Våte prøver viste
seigere oppførsel enn tørkede prøver, som i større grad utviklet fullstendig brudd | 92
Figur 98 – ASA etter 3 uker ved 60°C (skylt). Små mengder saltkorn observeres mellom printlagene. Grønne markering viser saltkorn mellom printlagene. Optisk mikroskopi ved Forskningsparken....... 93 Figur 99 – ASA etter tolv uker ved 60°C (skylt). Begrenset forekomst av saltkorn observeres mellom printlagene. Grønne markering viser saltkorn mellom printlagene. Optisk mikroskopi ved
Forskningsparken | 93
Figur 100 – ASA etter tolv uker ved 60 °C (skylt). Ingen synlige saltrester observeres i den indre
strukturen. Optisk mikroskopi ved Kongsberg Discovery | 94

Figur 101 – ASA etter tolv uker ved 60 °C (ikke skylt). Denne prøven skiller seg fra de øvrige ASA-prøvene ved å vise tydelig saltinntrengning og store mengder saltkrystaller mellom printlagene. Optisk
mikroskopi ved Kongsberg Discovery | 94
Figur 102 – ASA-prøve etter tolv uker ved 60 °C. Optisk mikroskopibilde av ASA-prøve som viser ruglete
kantstruktur langs ytterkanten etter eksponering. Optisk mikroskopi ved Forskningsparken | 95
Figur 103 – ASA (sort). Optisk mikroskopibilde som viser mørke partikler i materialets overflatestruktur. Grønne markereringer viser observerte partikler i materialet. Optisk mikroskopi ved Kongsberg
Discovery | 96
Figur 104 – ASA (sort). I den indre strukturen observeres sorte prikker. Røde firkanter markerer
områder som er forstørret i utsnittene. Optisk mikroskopi ved Kongsberg Discovery | 96
Figur 105 – ASA (sort). Detaljbilde av indre struktur og partikler ved høyere forstørrelse, observert med
optisk mikroskopi ved Kongsberg Discovery | 97
Figur 106 – ASA (sort). Tilsvarende område vist som fargekart, der blå farge indikerer lavere høyder og
rød indikerer høyere områder. Optisk mikroskopi ved Kongsberg Discovery | 97
Figur 107 – ASA (grå). Indre struktur med lavere forekomst av sorte partikler sammenlignet med sort
ASA. Optisk mikroskopi ved Kongsberg Discovery | 97
Figur 108 – ASA (hvit). I den indre strukturen ser man kun ett par små sorte prikker. Grønne sirkler
markerer sorte prikker. Optisk mikroskopi ved Kongsberg Discovery | 98
Figur 109 – ASA. Prøvestaver etter brudd ved ulike eksponeringstider (uke 0, 3, 6, 9 og 12) ved 60 °C.
Brudd oppstår i samme område for samtlige prøver | 99
Figur 110 – ASA ved 60°C i tolv uker. Det observeres små, sorte plastpartikler i glassbeholderen. .... 99 Figur 111 – Termografi bilde av byggeplaten til Bambu X1C. Skala på høyre side av hvert a og b er
temperatur. a) Temperaturer uten IR-bilde overlagt, b) Temperaturer med IR-bilde overlagt | 110
Figur 112 – Termografibilde av byggeplaten til Prusa MK3s. Skala på høyre side av hvert a og b er
temperatur. a) Temperaturer uten IR-bilde overlagt, b) Temperaturer med IR-bilde overlagt | 110
Figur 113 – Printmiljøet for Prusa MK3 | 111
Figur 114 – Printmiljøet for Bambu X1C | 111

### Tabelliste

Tabell 1 – Samlet oversikt over omtrentlige glasstransisjonstemperaturer (Tg) og typiske

Tabell 2 – Komparativ oversikt over kritiske termodynamiske, kjemiske og barrierespesifikke

Tabell 10 – Viser tabelloppsett som ble gjort i Microsoft Excel for plotting av ln(k) mot 1000/T ........ 40

Tabell 13 – Viser utregnede verdier for aktiveringsenergi basert på stigningstall fra plottene og verdier

# Innholdsfortegnelse

1 Innledning | 1
1.1 Bakgrunn | 2
1.2 Mål og omfang | 2
1.3 Tverrfaglig samarbeid | 2
1.4 Problemstilling | 3
1.5 Avgrensninger | 3
1.6 Formidling av prosjektet | 4
2 Teoretisk grunnlag | 6
2.1 cNode Mantis: akustisk dataoverføring under vann | 6
2.2 FDM 3D-printing | 7
2.3 Materialteori (PLA, PETG, ASA) | 8
2.4 Viskoelastisitet, flyt og mekanisk oppførsel under strekking | 14
2.5 Degradering og vannopptak i saltvann | 14
2.6 Trykk og dimensjonering | 17
2.7 Overflatebehandlinger | 19
2.8 Pakninger og vanntetting | 21
3 Metode | 22
3.1 Produksjon av prøvestykker | 22
3.2 Utstyr brukt for strekkprøver | 23
3.3 Prøveforberedelse og eksponering | 26
3.4 Strekkprøving etter ISO 527 | 30
3.5 Beleggapplikasjon og inntrengingstest | 32
3.6 Kompresjon- og hydrostatisk test | 34
3.7 Mikroskopi | 39

3.8 Fremgangsmåte for Arrhenius-analyse | 40
3.9 Lekkasjetesting av sylindriske testobjekter sylindere | 41
4 Design og utvikling | 43
4.1 Kravspesifikasjon elektronikkinnpakning | 44
4.2 Konseptutvikling | 46
4.3 Valg av løsning | 52
4.4 Dimensjonering av veggtykkelse | 59
4.5 Demonstrasjonsprototype for sensorintegrasjon | 61
5 Resultater | 63
5.1 Strekkegenskaper over tid | 63
5.2 Vannopptak - masseendring over tid | 68
5.3 Arrhenius-analyse | 70
5.4 Kompresjonsprøver | 73
5.5 Innledende evaluering av overflatebehandlinger | 75
5.6 Nedsenkningstester av konteinere | 77
5.7 Trykktest ved 3 bar | 79
5.8 Mikroskopi | 82
6 Diskusjon | 100
6.1 Egnethet av ubehandlet PLA, PETG og ASA for marin bruk | 100
6.2 Evaluering av strukturell integritet og tetningsevne under hydrostatisk trykk (3 bar) | 104
6.3 Mikroskopi-observasjoner | 106
6.4 Kobling mellom delresultater og prototype-design | 108
6.5 Avvik og feilkilder | 109
7 Konklusjon | 113
7.2 Hovedfunn | 114
7.3 Anbefaling | 115
8 Videre arbeid | 116
9 Bruk av kunstig intelligens | 117

10 Kilder | 118
11 Appendiks | 123
11.1 Appendiks A: Digitalt prosjektarkiv | 123
11.2 Appendiks B: Vurderingskriterier og observasjonsskjema | 125
11.3 Appendiks C: Testmatrise | 127
11.4 Appendiks D: Tegninger av prototype | 128
11.5 Appendiks E: Bruddoppførsel i PETG | 134

# 1 Innledning

Norges kystlinje strekker seg over 100 000 kilometer når øyer og fjorder inkluderes, og både forsvar, havbruk, petroleumsindustri og forskning er avhengig av pålitelig teknologi som fungerer under vann. Overvåking av havbunnsinstallasjoner, autonome sensornettverk og undervannskommunikasjon stiller strenge krav til utstyr som må tåle korrosivt saltvann, hydrostatisk trykk og begrenset tilgang for vedlikehold. Tradisjonelt har slike komponenter ofte blitt fremstilt i maskinert metall, noe som kan gi høy kostnad og lang ledetid for prototyper.

3D-printing åpner for rask og rimelig prototypeproduksjon, men introduserer samtidig nye utfordringer når komponentene skal brukes i marine miljøer. Lagvis oppbygning kan gi porøsitet og svake grenseflater, samtidig som polymermaterialer kan påvirkes av saltvann, temperatur og mekanisk belastning over tid. For å vurdere om 3D-printede polymerkomponenter kan benyttes i undervannsapplikasjoner, må materialenes langtidsoppførsel og tetningsevne dokumenteres systematisk.

Kongsberg Discovery utvikler det akustiske modemet C-node Mantis for trådløs dataoverføring under vann (se Figur 1). Systemet benyttes blant annet til navigasjon, posisjonering og overføring av sensordata mellom undervannsenheter og overflateinstallasjoner (se Figur 2). I samarbeid med Kongsberg Discovery og en tverrfaglig prosjektgruppe ved USN undersøkes muligheten for å tilpasse Mantis-plattformen til en ny brukerkontekst. Målet er at dykkere skal kunne benytte teknologien til kommunikasjon og dataoverføring under operasjoner.

Figur 1 – cNODE Mantis akustisk videomodemsystem [1].


Figur 2 – cNode Modem MANTIS i aksjon, som viser akustisk/optisk kommunikasjon mellom undervannsplattform og eksterne moduler [2].

## 1.1 Bakgrunn

Det finnes publiserte studier av 3D-printede polymerer og miljøeksponering, men det er fortsatt behov for mer dokumentasjon på hvordan mekaniske egenskaper, vannopptak og overflatebehandling påvirker funksjonen over tid. Mange studier fokuserer hovedsakelig på korttidseksponering eller enkeltparametere som for eksempel strekkfasthet. I mindre grad undersøkes den samlede påvirkningen disse faktorene har på komponentens funksjonalitet over tid. Det mangler også studier som kombinerer akselerert aldring ved ulike temperaturer med praktisk testing av vanntetting for 3D-printede deler.

Denne oppgaven bidrar til å fylle dette kunnskapsgapet gjennom testing av tre polymermaterialer i saltvann, gjennom systematisk saltvannseksponering over tolv uker ved tre temperaturer. Videre evalueres enkle belegg og det utvikles en funksjonell prototypekapsling.

## 1.2 Mål og omfang

Det overordnede målet med bacheloroppgaven er å undersøke om 3D-printede polymerer er egnet som funksjonelle prototyper i undervannsapplikasjoner. Det undersøkes hvordan materialvalg, utforming og overflatebehandling påvirker komponentenes motstand mot hydrostatisk trykk og langvarig saltvannseksponering.

Arbeidet er organisert langs tre hovedretninger. Den første retningen fokuserer på mekanisk styrke og materialdegradering i tre utvalgte polymermaterialer. Materialene testes gjennom strekkprøving, vannopptaksmåling og Arrhenius-analyse etter eksponering i saltvann ved ulike temperaturer. Den andre retningen undersøker barriereegenskaper, der enkle belegg testes for å vurdere om de kan hindre vanninntrengning i 3D-printede strukturer. Den tredje retningen er utvikling av en funksjonell prototypekapsling for det akustiske modemet cNode Mantis, basert på resultater fra materialtestene.

## 1.3 Tverrfaglig samarbeid

Prosjektet er gjennomført som et tverrfaglig samarbeid mellom to bachelorgrupper ved USN. Vår gruppe, bestående av fem maskiningeniørstudenter, har hatt hovedansvaret for materialvalg, mekanisk testing, vanntetting og utvikling av kapslingsdesign. Den samarbeidende gruppen bestod av elektronikkingeniørstudentene Don Phillip Torres Bullecer, Alexander Rivrud Belmonte og Robin André Holen, samt elektroingeniørstudent Magnus Andrew Rømo. Denne gruppen hadde ansvar for utvikling av sensorsystemet, inkludert kretskort og signalbehandling. Gruppene samarbeidet tett gjennom prosjektperioden for å sikre at elektronikken kunne integreres i kapslingens indre volum. Grensesnittet mellom gruppene ble definert gjennom en felles kravspesifikasjon for innvendig montering, komponentplassering og kontaktpunkter.

## 1.4 Problemstilling

Hvordan påvirker langvarig saltvannseksponering ved ulike temperaturer de mekaniske egenskapene og funksjonaliteten til 3D-printede polymerkomponenter i undervannsapplikasjoner?

For å besvare dette undersøkes følgende delspørsmål:

1. Hvordan påvirkes strekkfasthet, elastisitetsmodul og flytespenning i de utvalgte polymermaterialene etter opptil tolv ukers eksponering i kunstig saltvannsløsning ved 20, 40 og 60 °C?
2. I hvilken grad kan ulike overflatebehandlinger redusere vanninntrengning i 3D-printede komponenter under trykktesting?
3. Kan en 3D-printet prototypekapsling oppfylle grunnleggende krav til beskyttelse av elektronikk ved operasjonsdybde?

## 1.5 Avgrensninger

Materialvalget er avgrenset til tre lett tilgjengelige polymerer som er mye brukt til å 3D-printe prototyper. De konkrete materialene presenteres og begrunnes i kapittel 2.3. Eksponeringsperioden er satt til tolv uker. Forhøyede temperaturer ved 40 og 60 °C benyttes som akselerert aldring for å fremskynde temperaturavhengige endringer og gi grunnlag for Arrhenius-basert vurdering av langtidsutvikling. Resultatene representerer likevel ikke en fullskala levetidstest under reelle driftsforhold. Valg av overflatebehandlinger er begrenset til Bengalack spray, to-komponent polyester og Jotun Vinyl Primer, i tillegg til ubehandlede referanseprøver.

O-ringer og presspasninger er ikke et hovedundersøkelsesområde i oppgaven. En presspasning på 15 prosent er valgt basert på faglige anbefalinger fra Kongsberg Discovery, og standard ingeniørlitteratur er lagt til grunn fremfor egne målinger på dette området.

Kompresjonstestene benytter to-punkts belastning og er ment som en innledende validering av veggtykkelse, ikke som en fullskala isobar trykktest.

Trykktesten er gjennomført på små sylindriske bokser, ikke på fullskala prototype. Den endelige prototypen er en demoenhet og har ikke overflatebehandling eller blitt trykktestet i denne studien.

Resultatene er begrenset til materialene, printparameterne og testbetingelsene som inngår i studien, og kan derfor ikke generaliseres til alle 3D-printede polymerkomponenter eller marine bruksmiljøer.

For å avgrense prosjektet etter faktiske behov og rammer ble det gjennomført semistrukturerte intervjuer av eksterne aktører. Faglige innspill fra det uavhengige forskningsinstituttet Norner (6.10.2025) som forsker på plastmaterialer ble brukt som grunnlag for valg av materialer til testing.

For å undersøke relevante bruksområder og operative krav ble det gjennomført intervjuer med en subsea-ingeniør, Magnus Hesle (11.02.2026), og en militær yrkesdykker, Olav Håskjold (10.03.2026). Innspillene viste at løsningen ikke var egnet for dype operasjoner på 100-200 meters dybde, men mer aktuelt for bruk på 10-20 meters dybde. Dette førte til en avgrensning av prosjektet mot grunnere anvendelser.

Den militære yrkesdykkeren vurderte konseptet som særlig relevant i operasjoner der dykkeren arbeider under vann uten kontakt med mannskap på overflaten. Dersom funksjon og pålitelighet kan dokumenteres, kan løsningen dekke et behov som militæret kan ha interesse av å ta i bruk.

## 1.6 Formidling av prosjektet

Gjennom prosjektperioden har gruppen deltatt på flere demonstrasjoner og presentasjoner i samarbeid med Kongsberg Discovery. Demonstrasjonene ga både representanter fra Kongsberg Discovery og eksterne besøkende mulighet til å få innblikk i prosjektets mål, tekniske løsninger, utviklingsprosess og praktiske anvendelsesområder. Arrangementene fungerte også som en viktig arena for faglige tilbakemeldinger, spørsmål og videre diskusjoner rundt prosjektets utvikling. Ved den siste demonstrasjonen fikk prosjektet også interesse og mediedekning fra NRK (se Figur 3).


Figur 3 – utdrag av nyhetssending fra NRK [3]

Innledende konseptdemonstrasjon (Mars 2026)

Den første demonstrasjonen, avholdt ved Skipperstua i Horten, fokuserte på prosjektets planlagte metodikk og utviklingsprosess. Gruppen presenterte materialvalg, testprotokoller, planlagt kapslingsarkitektur samt innledende planer for funksjonstesting. De fremmøtte fikk også inspisere det eksperimentelle oppsettet for akselerert aldring i kunstig sjøvann. Demonstrasjonen resulterte i verdifulle faglige tilbakemeldinger knyttet til det forventede bruksmiljøet og de hydrostatiske belastningene kapslingen ville utsettes for, noe som ga viktige føringer for det videre designarbeidet.

Midtveisdemonstrasjon av prototype (Mars 2026)

Den andre demonstrasjonen fokuserte på videre utvikling av kapslingens oppbygning og arkitektur. Gruppen presenterte resultater fra testene som var gjennomført så langt, samt hvilke løsninger og materialer som hadde fungert best. Under demonstrasjonen ble det også vist frem en 3D-printet prototype av kapslingen som de fremmøtte fikk mulighet til å undersøke nærmere. Demonstrasjonen ble gjennomført ved Skipperstua i Horten.

Avsluttende systemdemonstrasjon (April 2026)

Den avsluttende demonstrasjonen ble gjennomført ved Indre Havn i Horten og markerte ferdigstillingen av prosjektets utviklingsfase. Tre studentgrupper og en studentorganisasjon viste frem sine prosjekter. For å demonstrere det tverrfaglige aspektet ved prosjektet, ble arrangementet gjennomført i tett samarbeid med den tverrfaglige gruppen. Sammen presenterte gruppene den ferdige prototypekapslingen med fullt integrert sensorelektronikk og batterisystem montert i det indre stativet.

Materialvalg, testresultater og designvurderinger ble presentert. Arrangementet samlet representanter fra Kongsberg Discovery, Forsvarets forskningsinstitutt og Universitetet i Sørøst-Norge (USN). Den faglige og offentlige interessen for prosjektets teknologiske løsninger resulterte i betydelig mediedekning, inkludert artikkel i NRKs nettavis [4], samt reportasje i lokalavisen Gjengangeren [5].


Figur 4 – Stor interesse på demo 3, ved Kongsberg Discovery

# 2 Teoretisk grunnlag

Dette kapittelet presenterer det teoretiske grunnlaget for oppgaven. Først beskrives cNode Mantis-systemet som utgangspunkt for prototypekapslingen, etterfulgt av FDM-printprosessen og dens innvirkning på mekaniske egenskaper. Deretter gjennomgås materialteori for PLA, PETG og ASA, viskoelastisk oppførsel under strekk. Kapittelet tar også for seg degraderingsmekanismer og vannopptak i saltvann inkludert Arrhenius-modellen. Til slutt presenteres teori knyttet til trykk og dimensjonering av sylindriske strukturer, overflatebehandlinger og pakningsdesign for vanntetting.

## 2.1 cNode Mantis: akustisk dataoverføring under vann

Kongsberg Discovery sin C-node Mantis er et kompakt akustisk modem beregnet på trådløs dataoverføring mellom undervannsenheter. Systemet benyttes til kommunikasjon, navigasjon og overføring av sensordata, og er opprinnelig utviklet for bruk mellom ROV-er, sensornoder og overflateinstallasjoner [2].

I dette prosjektet undersøkes muligheten for å tilpasse Mantis-plattformen til en dykker-kontekst. For at systemet skal være praktisk anvendelig i et slikt bruksscenario, må elektronikken kapsles i en innretning som tåler langvarig saltvannseksponering og det hydrostatiske trykket ved operasjonsdybde..

### 2.1.1 Krav til undervannskapsler for elektronikk

En kapsling beregnet på å beskytte elektronikk under vann må oppfylle flere krav. Det mest grunnleggende er vanntetthet: kapslingen må motstå hydrostatisk trykk ved operasjonsdybden uten lekkasje gjennom vegger, skjøter eller pakningsflater. Ved 20 meters dybde tilsvarer dette et ytre overtrykk på omtrent 2 bar [6], noe som stiller krav til både veggtykkelse, geometri og pakningsdesign.

Materialet må i tillegg tåle langvarig eksponering for saltvann uten at mekaniske egenskaper degraderes til et nivå der strukturell integritet ikke lenger kan opprettholdes. For FDM-printede komponenter er dette særlig relevant fordi den lagvise oppbygningen introduserer porøsitet og svake laggrenser som kan akselerere vanninntrengning og degradering sammenlignet med bulkmaterialet.

Kapslingen må også være kompatibel med pakningsløsningen. O-ringer i NBR-gummi, krever jevne kontaktflater og kontrollert presspasning for å oppnå pålitelig forsegling. FDM-printede overflater har iboende ruhet fra lagstrukturen [7], og overflatebehandling kan være nødvendig for å oppnå tilstrekkelig flathet i pakningssporet.

For dykkerhåndtert utstyr er det i tillegg praktiske begrensninger knyttet til vekt, størrelse og håndterbarhet. Kapslingen må kunne betjenes med hansker, tåle støt under transport, og være enkel å åpne og lukke for tilgang til elektronikken. Disse kravene har lagt premissene for materialvalg, dimensjonering og testprogram i denne oppgaven. Den prosjektspesifikke prioriteringen av kravene er beskrevet i kravspesifikasjonen i kapittel 4.1.

## 2.2 FDM 3D-printing

Fused Deposition Modeling (FDM) er en additiv tilvirkningsmetode der en termoplastisk filamenttråd mates gjennom en oppvarmet dyse, smeltes og legges ned lagvis på en byggeplate, som vist i Figur 5. Geometrien bygges opp ved at materialet ekstruderes langs bestemte baner i hvert lag, før byggeplattformen eller munnstykket forskyves i høyderetningen for neste lag. Etter deponering avkjøles materialet og stivner, samtidig som det etableres binding mellom tilstøtende ekstruderte strenger og mellom påfølgende lag. Den ferdige delen består derfor av en laminertstruktur, der mekaniske egenskaper påvirkes av blant annet materialvalg, printtemperatur, lagtykkelse, fyllingsgrad, printhastighet og orientering under printing [7].


Figur 5 – Prinsippskisse av FDM-prosessen, der en termoplastisk filamenttråd mates gjennom et oppvarmet munnstykke og deponeres lagvis på en oppvarmet byggeplattform. Egenprodusert figur.

Binding mellom lag utvikles gjennom en sintringsprosess drevet av termisk energi fra det semi-smeltede materialet. Når det smeltede materialet ekstruderes og kommer i kontakt med foregående lag, smelter de to lagene sammen ved kontaktflaten. Deretter dannes en halsformasjon (neck growth) gjennom viskøs sintring, og molekyldiffusjon over grenseflaten styrker bindingen ytterligere [7]. Kvaliteten på denne bindingsprosessen er kritisk for delens endelige mekaniske egenskaper.

FDM-printede deler inneholder mikroskopiske hulrom mellom filamentsporene og mellom lag, samt restspenninger fra ujevn avkjøling. Disse defektene fører til at mekaniske egenskaper blir sterkt anisotrope, det vil si avhengige av belastningsretning i forhold til lagoppbyggingen. Styrken er typisk høyest når belastningen er parallell med laggrensene (XY-planet) og lavest når belastningen virker vinkelrett på laggrensene (Z-retning) [7].

## 2.3 Materialteori (PLA, PETG, ASA)

De tre materialene som undersøkes i dette prosjektet, PLA (Polylaktid, polylactic acid / polylactide), PETG (polyethylene terephthalate glycol-modified) og ASA (akrylnitril-styren-akrylat), er valgt på bakgrunn av deres utbredelse i forbrukermarkedet og deres forskjellige egenskaper for undervannseksponering. Sammen representerer disse tre materialene ulike polymerklasser med forskjellig molekylær struktur og grad av krystallinitet (se kapittel 2.3.1).

PLA er et av de mest brukte materialene for FDM-printing og er kjent for sin bioplast-opprinnelse [8]. Materialet er lett tilgjengelig, relativt rimelig og kan printes ved lavere temperaturer enn flere andre tekniske termoplaster. PLA er også kjent for god printbarhet og lav tendens til deformasjon under printing, noe som gjør materialet mye brukt til prototyper og enkle komponenter. Samtidig påvirkes de mekaniske egenskapene i FDM-printede PLA-deler av prosessparametere som lagtykkelse, fyllingsgrad og byggeorientering [9].

PETG er et mye brukt alternativ til PLA og har generelt lavere stivhet og høyere bruddtøyning enn PLA, noe som gir en mer duktil materialoppførsel [10]. Materialet benyttes også i applikasjoner der komponenter kan eksponeres for fuktighet eller vann, noe som gjør PETG relevant for FDM-printede deler i fuktige miljøer eller undervannsmiljøer [11].

ASA er en termoplast som ofte brukes i utendørs strukturelle applikasjoner på grunn av mekanisk stabilitet og god værbestandighet. Materialet er særlig relevant for komponenter som kan utsettes for UV-eksponering, ettersom ASA kombinerer mekanisk styrke med motstand mot fargeendring ved langvarig UV-påvirkning. I tillegg har ASA moderat termisk og kjemisk bestandighet, og en glasstransisjonstemperatur på omtrent 100 °C [12].

### 2.3.1 Amorf og semikrystallinsk polymerstruktur

I motsetning til små molekyler som vann eller metan, som vanligvis er enten fullstendig krystallinske i fast fase eller fullstendig amorfe i flytende fase, har polymerer en mer kompleks strukturell oppbygning. På grunn av deres store molekylstørrelse og kjedelengde kan polymerkjedene kun delvis ordne seg i regulære krystallinske strukturer. De fleste polymerer er derfor semikrystallinske, der krystallinske områder eksisterer spredt i et amorf, uordnet materiale [13, Kap. 4].

Som vist i Figur 6 består amorfe områder av polymerkjeder som er uordnet orientert, med tilfeldige bøyer, kveiler og sammenflokinger som hindrer regelmessig pakking. Krystallinske områder oppstår der molekylkjedene har klart å ordne seg i parallelle og tettpakkede strukturer. Fordi polymerkjedene er lange og fleksible, vil knekk, vridninger og feilorienteringer mellom kjedesegmenter kunne danne amorfe områder. Dette gjør fullstendig krystallinitet praktisk vanskelig å oppnå for de fleste polymerer [13, Kap. 4].


Figur 6 – Prinsippskisse av amorf og semikrystallinsk polymerstruktur. Egenillustrert, basert på beskrivelse av polymerers amorfe og krystallinske områder i [13, Kap. 4].

klKrystallinitetsgraden i polymerer varierer fra helt amorf til nesten fullstendig krystallinsk, der opptil omtrent 95 prosent av materialet kan være krystallinsk. Dette står i kontrast til metaller, som nesten alltid er helt krystallinske, og mange keramiske materialer, som enten er fullstendig krystallinske eller fullstendig amorfe. Semikrystallinske polymerer kan betraktes som analoge til tofaselegerede metaller, der to distinkte faser eksisterer side om side [13, Kap. 4].

Tettheten til en polymer er direkte påvirket av krystallinitetsgraden. Krystallinske regioner har høyere tetthet enn amorfe regioner fordi molekylkjedene er tettere pakket sammen. Denne forskjellen kan utnyttes til å bestemme krystallinitetsgraden ved nøyaktige tetthetsmålinger, basert på ligning 4.8 i [13, Kap. 4]

Krystallinitetsgraden påvirkes av flere faktorer. Kjemisk enkle polymerer som polyetylen og polytetrafluoroetylen krystalliserer lett, mens polymerer med komplekse repetisjonsenheter motstår krystallisering. Avkjølingshastigheten under størkningsprosessen er også kritisk: langsom avkjøling gir polymerkjedene tid til å ordne seg i krystallinske strukturer, mens rask avkjøling fryser kjedene i uordnede, amorfe konfigurasjoner [13, Kap. 4].

For FDM-printede deler er dette relevant, ettersom prosessen innebærer oppvarming, ekstrudering og avkjøling av polymermaterialet. Materialets krystallinitet kan derfor knyttes til både polymerens molekylstruktur og den termiske historikken under prosessering [13, Kap. 4], [14]. Lineære polymerer har generelt større mulighet for å krystallisere fordi det er færre strukturelle hindringer for kjedeinnretting. Forgreinede polymerer får redusert krystallinitet fordi sidekjedene forstyrrer regelmessig pakking. Nettverkspolymerer og kryssbundne polymerer er vanligvis nesten helt amorfe, fordi kryssbindingene hindrer polymerkjedene i å reorganisere seg til en krystallinsk struktur, selv om enkelte kryssbundne polymerer kan være delvis krystallinske [13, Kap. 4].

### 2.3.2 PLA

PLA er en biologisk nedbrytbar termoplast syntetisert fra melkesyre-monomerer. Melkesyre produseres industrielt gjennom bakteriell fermentering av fornybare karbohydratkilder som hvete, mais, sukkerrør og sorghum [8]. Repetisjonsenheten for PLA består av en metylgruppe, en karbonylgruppe og en ester-binding [15].

PLA har en glasstransisjonstemperatur (Tg) på omtrent 60 til 65 °C [15], [16], [17]. Moetazedian et al.
[16] målte Tg til 63,4 °C for kommersielt PLA-filament (NatureWorks polylactide 4043D). Slavković et al. [17] bestemte Tg til 65 °C ved hjelp av dynamisk mekanisk termisk analyse (DMTA) for FDM-printet PLA. Denne temperaturen markerer overgangen fra en stiv, glassaktig tilstand til en gummiaktig tilstand der kjedemobiliteten øker kraftig og materialets strukturelle integritet reduseres. PLA sitt smeltepunkt (Tm) ligger typisk rundt 180 °C [15].

Kommersielt PLA-filament er semikrystallinsk [15]. I FDM-printing resulterer imidlertid den raske ekstrusjon og avkjøling i at polymerkjedene ikke får tilstrekkelig tid til å ordne seg i krystallinske strukturer under solidifisering. Spoerk et al. [18] dokumenterte at FDM-printede PLA-komponenter oppnår tilnærmet amorf struktur sammenlignet med det semikrystallinske utgangsmaterialet.

Mekanisk sett har semikrystallinsk PLA en elastisitetsmodul på omtrent 3 GPa og en strekkfasthet på 50 til 70 MPa [15]. For FDM-printede deler er de mekaniske egenskapene sterkt påvirket av printparametere som lagtykkelse, fyllingsgrad, printretning og ekstrusjonstemperatur. Rodríguez-Panes et al.
[9] dokumenterte at fyllingsgraden har størst innflytelse på strekkfasthet, mens lagtykkelse dominerer bruddforlengelsen.

PLA sin ester-binding i hovedkjeden gjør materialet følsomt for hydrolytisk degradering [19]. Vannmolekyler kan reagere med ester-bindingene og føre til kjedebrudd, noe som gradvis reduserer molekylvekten og dermed de mekaniske egenskapene [19], [20]. Denne hydrolysemekanismen er temperaturavhengig og akselereres ved forhøyede temperaturer [19]. I marint miljø kan UV-stråling og oksygen ytterligere akselerere hydrolysen [20]. En mer detaljert diskusjon av hydrolytisk degradering i marint miljø presenteres i kapittel 2.5.2.

### 2.3.3 PETG

PETG er en glykolmodifisert variant av polyetylentereftalat (PET). Modifikasjonen innebærer at en andel av etylenglykol-enhetene i PET erstattes med sykloheksan dimetanol (CHDM) gjennom kopolymerisering. Den større CHDM-enheten forstyrrer den regulære kjedestrukturen og forhindrer krystallisering, noe som resulterer i et amorft materiale. PETG forblir amorft når CT-innholdet (sykloheksan dimetanol tereftalat) ligger mellom 32 og 62 prosent [21].

PETG har en Tg på omtrent 80°C og et Tm rundt 220 til 250°C [22]. Smeltepunktet for PET ligger på 265°C [13, Kap. 12]. Den reduserte krystalliniteten i PETG sammenlignet med PET skyldes tilsetningen av CHDM-enheter [21].

I motsetning til PLA er PETG generelt amorft i sin kommersielle filamentform [23]. Den glykolmodifiserte strukturen forhindrer krystallisering under normale prosesseringsforhold, noe som gir materialet god prosesserbarhet og lav tendens til warping under FDM-printing [21]. PETG kan absorbere fuktighet fra omgivelsene, og fuktinnhold i materialet kan føre til hydrolytisk degradering under lagring og prosessering. Hydrolytisk degradering kan påvirke strekkegenskapene til FDM-printede deler [24], mens tørking av PETG-filament før printing er vist å kunne forbedre både overflatekvalitet og mekaniske egenskaper i printede prøver [25].

PETG viser høyere bruddforlengelse enn PLA, men FDM-prosessen reduserer denne betydelig [26]. Printeparametere som lagtykkelse og fyllingsgrad påvirker de mekaniske egenskapene [22].

Som amorf polymer responderer PETG annerledes på termisk etterbehandling enn semikrystalline polymerer som PLA. Ved gløding over glasstransisjonstemperaturen får polymerkjedene økt mobilitet, noe som forbedrer laginterdiffusjon uten å indusere krystallinitet. Bhandari et al. [26] dokumenterte at gløding av FDM-printet PETG ved temperaturer over Tg forbedret strekkfasthet mellom lagene betydelig, med 10 til 22 prosent økning i mekaniske egenskaper for rent PETG. Stojković et al. [22] fant at optimal gløding ble oppnådd ved 60 °C i 90 minutter, betydelig under Tg for å unngå deformasjon. I motsetning til PLA, der gløding både forbedrer laginterdiffusjon og øker krystallinitet, er effekten av gløding på PETG primært knyttet til forbedret molekylær diffusjon over lag grensene [26].

### 2.3.4 ASA

ASA er en amorf termoplast som ble utviklet som et mer værbestandig alternativ til ABS (akrylnitrilbutadien-styren). Materialet har god UV-bestandighet og langvarig fargestabilitet, og brukes derfor ofte i utendørs komponenter, elektronikkhus og andre applikasjoner der mekanisk stabilitet og værbestandighet er viktig [12].

Tg for ASA er omtrent 100 °C [12], betydelig høyere enn både PLA (60–65 °C) [16], [17] og PETG (~80°C) [22]. Dette gjør ASA mer relevant enn PLA og PETG i applikasjoner der komponenter kan eksponeres for forhøyede temperaturer. Samtidig er ASA et termisk sensitivt materiale i FDM-printing, der kammertemperatur og prosessparametere kan påvirke lagbinding og mekaniske egenskaper [27].

Ved væskeeksponering viste ASA god mekanisk stabilitet i destillert vann, eddiksyre og hydrogenperoksid under de testede betingelsene. Materialet ble imidlertid tydeligere påvirket av sterkere løsemidler, særlig konsentrert isopropanol og aceton, og bør derfor ikke omtales som generelt motstandsdyktig mot alle alkoholer eller løsemidler [28].

ASAs mekaniske egenskaper er sammenlignbare med ABS, men materialet har bedre vær- og UV-bestandighet [12]. Palička et al. [12] viste at ASAs mekaniske respons er temperaturavhengig, der økt temperatur gir redusert flytespenning og mer duktil materialoppførsel. Dette er relevant for komponenter som kan eksponeres for varierende temperaturer under bruk, ettersom både styrke og deformasjonsegenskaper kan endres med temperatur.

Ved FDM-printing av ASA er termisk kontroll viktig for å oppnå stabile mekaniske egenskaper og god lagbinding. ASA printes vanligvis ved 240-270 °C, med oppvarmet byggeplate på 90-110 °C og uten aktiv delkjøling ifølge eSUNs datablad [29]. Et lukket kabinett er særlig relevant for ASA, fordi stabil omgivelsestemperatur kan redusere raske temperaturfall mellom lagene og dermed begrense risikoen for termiske spenninger, warping og delaminering. Tan et al. [27] fant at en kammertemperatur på omtrent 50 °C ga høyest strekkfasthet og slagseighet for ASA-prøver produsert med FDM.

Tabell 1 – Samlet oversikt over omtrentlige glasstransisjonstemperaturer (Tg) og typiske dysetemperaturer for PLA, PETG og ASA ved FDM-printing.

POLYMER | Tg (°C) | DYSETEMPERATUR (°C)
PLA | Ca. 60-65 | Ca. 190-220
PETG | Ca. 80 | Ca. 220-250
ASA | Ca. 100 | Ca. 240-270

### 2.3.5 Gløding og termisk eksponering

Gløding er en termisk etterbehandling der polymerer holdes ved en forhøyet temperatur over en gitt tid, ofte nær eller over materialets glasstransisjonstemperatur, men under temperaturer der materialet mister geometrisk stabilitet. Hensikten er å gi polymerkjedene økt mobilitet, slik at indre spenninger kan reduseres og materialstrukturen kan reorganiseres. For FDM-printede deler kan gløding dermed påvirke både mekaniske egenskaper og dimensjonsnøyaktighet, men effekten avhenger av materiale, temperatur, eksponeringstid og lagtykkelse [22].

For delvis krystallinske polymerer, som PLA, kan gløding føre til økt krystallinitet, noe som kan forbedre stivhet og varmebestandighet. Samtidig kan prosessen gi dimensjonsendringer eller deformasjon dersom temperatur og tid ikke kontrolleres godt nok. Stojković et al. [22] undersøkte gløding av PLA, PETG og karbonfiberforsterket PETG ved ulike temperaturer, tider og lagtykkelser, og viste at både mekaniske egenskaper og dimensjonsendringer påvirkes av glødeparameterne. Studien fant også at lagtykkelse hadde stor innvirkning på strekkfastheten, og at optimal glødetemperatur var materialavhengig.

Flere studier viser at gløding kan gi forbedringer i mekaniske egenskaper for FDM-printede materialer, men resultatene varierer mellom materialtyper og testmetoder. Valvez et al. [30] undersøkte PETG og PETG-baserte kompositter og fant at gløding påvirket blant annet hardhet, bøyestyrke, slagstyrke, spenningsrelaksasjon og krypoppførsel. Samtidig viste studien at både temperatur og eksponeringstid kan gi dimensjonsendringer, noe som gjør prosesskontroll viktig ved termisk etterbehandling. Szust og Adamski [31] viste også at termisk gløding kunne øke styrken i FDM-printede PLA-deler, mens svært store forbedringer i Z-retning for PETG ble oppnådd med en separat metode, saltassistert omsmelting, og ikke med ordinær gløding alene.

Effekten av termisk eksponering avhenger av forholdet mellom eksponeringstemperatur og materialets Tg. Ved temperaturer nær eller over Tg øker polymerkjedemobiliteten, noe som kan bidra til strukturell reorganisering og spenningsreduksjon. Dersom materialet samtidig eksponeres for fuktighet eller vann, kan forhøyet temperatur også akselerere degraderingsmekanismer, for eksempel hydrolytisk nedbrytning. For materialer med lav Tg, som PLA (60-65 °C) [16], [17], kan eksponering ved temperaturer rundt eller over derfor gi konkurrerende effekter mellom mulig forbedret lagbinding, økt krystallinitet og termisk eller hydrolytisk nedbrytning. For materialer med høyere Tg, som PETG (~80 °C) [22] og ASA (100-105 °C) [12], kreves høyere temperaturer for at glødingseffekten skal bli tydelig.

## 2.4 Viskoelastisitet, flyt og mekanisk oppførsel under strekking

Polymerer er viskoelastiske materialer, i motsetning til metaller som vanligvis beskrives som tilnærmet lineært elastiske ved lave belastningsnivåer før flyt. Viskoelastisitet innebærer at den mekaniske responsen avhenger av både belastningens størrelse og hastigheten den påføres med. Dette betyr at en polymer som utsettes for rask belastning kan oppføre seg stivere og sprøere enn samme polymer belastet saktere, der tiden gir polymerkjedene større mulighet til å bevege seg, gli og reorganisere seg [13, Kap. 8].

Dette skiller seg fra metaller som testes etter ISO 6892-1 [32], der standarden omhandler strekkprøving av metalliske materialer ved romtemperatur. For FDM-printede polymerer påvirkes den mekaniske responsen i tillegg av lagstrukturen. Svakere binding mellom lag og mikroskopiske hulrom kan gi anisotrope og reduserte mekaniske egenskaper sammenlignet med konvensjonelt produserte polymere komponenter [33]. Belastningshastigheten kan også påvirke strekkegenskapene til FDM-printede termoplaster, ettersom slike materialer viser belastningshastighetsfølsomhet under mekanisk testing [34].

Strekkhastighetens påvirkning på denne oppførselen er betydelig. Ved høyere strekkhastighet får polymerkjedene kortere tid til å gli og orientere seg, noe som kan føre til høyere tilsynelatende stivhet og mer sprø bruddoppførsel. Ved lavere strekkhastighet får kjedene mer tid til gradvis orientering og deformasjon, noe som kan gi større plastisk tøyning før brudd, mer uttalt innsnevring og en mer duktil bruddflate [13, Kap. 8], [34].

## 2.5 Degradering og vannopptak i saltvann

Degradering av polymermaterialer påvirkes av flere faktorer, blant annet materialstruktur, miljø og temperatur. I dette delkapittelet presenteres sentrale degraderingsmekanismer for polymerer i saltvann, med utgangspunkt i materialene PLA, PETG og ASA. Temperatur har også en stor betydning for degraderingsprosessen og vannopptaket, noe som gjør at det kan knyttes til akselerert aldring og Arrhenius-modellen.

### 2.5.1 Akselerert aldring

Polymerer gjennomgår en nedbrytningsprosess over tid når de utsettes for ulike miljøforhold. Denne nedbrytningen kan forårsake irreversible endringer i materialets egenskaper. For å kunne forutse hvilke endringer som utvikler seg over lengre tid, benyttes akselerert aldring. Dette er en testmetode hvor materialer utsettes for forhøyet temperatur, fuktighet, stråling eller andre eksterne faktorer som bidrar til en raskere nedbrytning [35]. Når både temperatur og fuktighet påvirker materialets degradering, kalles dette hydrotermisk aldring. Akselerert aldring er relevant for å kunne si noe om estimert levetid og materialets ytelse over tid [36].

### 2.5.2 Mekanismer for degradering

Polymerer som eksponeres for marine miljøer påvirkes av flere faktorer som kan føre til akselerert degradering av materialet. For å studere slike forhold under kontrollerte betingelser, benyttes ofte kunstig sjøvann fremstilt på laboratorium i henhold til utviklede standarder. Dette gir mulighet for å gjennomføre identiske tester gjentatte ganger under like forutsetninger. På den måten sikres det reproduserbare resultater [37].

Materialet kan påvirkes av fysiske faktorer som temperaturendringer og UV-stråling. I tillegg kan kjemiske påvirkninger bidra til degradering, som kan skje gjennom prosesser som oksidasjon, hydrolyse og økt saltinnhold. Videre kan materialets egenskaper ha en betydning for hvordan degraderingen forløper, som kjemisk struktur og tilsetningsstoffer [38]. Tidligere studier [39] viser at hydrolyse er en sentral påvirkningsmekanisme for PLA, spesielt når materialet påvirkes av vann og varme. Hydrolysen av PLA forutsetter at vann diffunderer gjennom materialet, hvor diffusjonen skjer lettere i de amorfe delene av polymeren. Den hydrolytiske nedbrytningen skjer i esterbindingene, noe som resulterer i kjededeling og videre degradering av materialet. Graden av vanndiffusjon vil derfor påvirke degraderingshastigheten.

En konsekvens av hydrolysen er at nedbrytningen fører til redusert molekylvekt og en økende andel kortere polymerkjeder. Disse korte kjedene kan lettere gli forbi hverandre, noe som kan gjøre materialet mykere og mer fleksibelt i starten av degraderingsprosessen. Etter hvert som molekylvekten reduseres ytterligere, vil de mekaniske egenskapene svekkes, og materialet kan blisprøtt og miste styrke [39].

PETG inneholder også estergrupper, men sammenlignet med PLA har materialet høyere slagfasthet og viser en mer stabil struktur mot saltvannsindusert nedbrytning. På grunn av sin mer hydrofobe karakter har PETG lav vannabsorbsjon, noe som bidrar til at hydrolytisk degradering skjer langsommere enn i PLA. Dette gjør PETG mer egnet til marine applikasjoner hvor materialet utsettes for fukt og sjøvann over tid. Langvarig miljøeksponering som UV-stråling og temperatur kan også påvirke degraderingsprosessen til materialet [40].

ASA er en termoplast som er utviklet for utendørs bruk og viser god motstand mot UV-stråling og andre miljøpåvirkninger. Materialet har en høy styrke og viser god stabilitet over lengre tid, uten betydelig tap av mekanisk ytelse i marine miljøer med høy fuktighet og saltinnhold. I motsetning til PLA og PETG oppstår det ikke hydrolytisk degradering i samme grad i ASA. Materialet påvirkes av UV-stråling og fotokjemisk degradering ved langvarig eksponering [40].

### 2.5.3 Temperaturens effekt på degradering

Temperatur er en viktig faktor som påvirker degraderingshastigheten til polymerer. Økt temperatur vil normalt føre til høyere reaksjonshastighet og akselererte degraderingsprosesser som hydrolyse og termisk aldring. Høye temperaturer øker molekylbevegelsen i materialet, noe som kan føre til raskere vanninntregning og økt nedbrytning av polymerstrukturen. Eksponering for sjøvann kombinert med forhøyede temperaturer kan derfor bidra til en raskere degradering [41]. Bruk av forhøyede temperaturer til simulering av langtidseffekter er derfor en vanlig metode. Arrhenius-modellen blir ofte brukt til å se på sammenhengen mellom temperatur og reaksjonshastighet.

### 2.5.4 Arrhenius-modellen

Graden av nedbrytning i polymerer vurderes ofte gjennom endringer i materialets egenskaper. Nedbrytningen er temperaturavhengig, og økning i temperatur vil normalt føre til en økt reaksjonshastighet. Arrhenius-ligningen beskriver forholdet mellom hastighetskonstanten og temperaturen [38]:

k = Ae

−

Ea
RT | (1)

Der:

- k: reaksjonshastighetskonstant
- A: frekvensfaktor
- Ea: aktiveringsenergi [

J
mol]
- R: den universelle gasskonstanten [8,314 J
K⋅mol]
- T: den absolutte temperatur [K]

Arrhenius-ligningen (1) beskriver hvordan reaksjonshastighetskonstanten endres gjennom ulike temperaturer og hvordan denne sammenhengen påvirkes av aktiveringsenergien [42]. Aktiveringsenergien defineres som den minste energien som kreves for å igangsette en kjemisk reaksjon. Ved høyere temperatur øker molekylenes kinetiske energi, noe som øker sannsynligheten for at energibarriere overvinnes og en reaksjon skjer. Reaksjonshastighetskonstanten beskriver hvor raskt en degraderingsprosess foregår og er temperaturavhengig. Dette innebærer at samme grad av degradering kan oppnås etter kortere tid ved høyere temperaturer [43].

For å oppnå en lineær sammenheng mellom ln(k) og 1/T, kan Arrhenius-ligningen skrives på logaritmisk form:

ln k = −

Ea
R

×

1
T

+ lnA

(2)

Den logaritmiske formen (2) gir en lineær sammenheng mellom ln(k) og 1/T, hvor stigningstallet (m) beskrives som - Ea /R, og kan benyttes for å finne aktiveringsenergien basert på målte data [42]. Arrhenius-forholdet brukes ofte til å estimere materialets livsløp og overvåkes gjennom endringer i mekaniske egenskaper som strekkfasthet, bruddstyrke, skjærspenning og utmattelsesfasthet. Dette er knyttet til sammenhengen mellom temperatur og reaksjonshastighet som danner grunnlaget for akselerert aldring. Ved å benytte forhøyede temperaturer kan degraderingsprosesser fremskyndes og dette gjør det mulig å estimere materialets levetid over kortere tid [44].

## 2.6 Trykk og dimensjonering

Ved dimensjonering av en sylinder som skal motstå isobart trykk, er det viktig å beregne spenningene som opptrer i sylinderveggen. Dette underbygges av Sinclair et al. [45] som anbefaler at formel (3) brukes for å få et mer korrekt svar for den tangentielle spenningen til en tynnvegget sylinder.

σ =

p ∙ (r +

t
2

)
t

(3)

Der:

- σ: tangentiell spenning [MPa]
- p: trykk [MPa]
- r: indre radius [mm]
- t: veggtykkelsen [mm]

Sylindere som benyttes i undervannsapplikasjoner utsettes i all hovedsak for et ytre, hydrostatisk trykk (pe). Ifølge Sinclair et al. [45] kan man da anvende et superposisjonsprinsipp for å beregne den resulterende tangentielle spenningen. Dette gjøres ved å beregne spenningen σ med formel (3) som om Pe virket som et internt trykk, for deretter å anvende formel (4).

σe = −(σ + pe) | (4)

Minustegnet i denne formelen (4) indikerer tydelig at sylinderveggen utsettes for en hydrostatisk tilstand av kompresjonsspenninger. Ettersom den beregnede spenningen for indre trykk (σ) og det ytre trykket (Pe

) begge utgjør positive størrelser, vil superposisjonen av disse alltid resultere i en negativ spenningsverdi for σe
, noe som i spenningsanalyse representerer ren kompresjon [45].

### 2.6.1 Hydrostatisk trykk

Når et legeme senkes ned i en væske, utsettes det for et trykk som virker normalt (vinkelrett) på alle overflater, og dette trykket øker proporsjonalt med dybden [6]. Ved å definere dybden som positiv nedover, beregnes det hydrostatiske trykket ved hjelp av følgende ligning:

p = p0 − ρgℎ | (5)

Der:

- p: hydrostatisk trykk [Pa]
- p0: atmosfærisk trykk [Pa]
- ρ: væskens massetetthet [

kg
m³

]

- g: tyngdeakselerasjonen [

m
s

2

]

- ℎ: dybde [m]

### 2.6.2 Feilmekanismer under hydrostatisk trykk

Når et hult objekt må motstå betydelige ytre trykkpåkjenninger, som kan medføre strukturell instabilitet kjent som knekking, der ytre trykk tvinger veggene i strukturen sammen radielt [45]. Dette fenomenet kjennetegnes ved et momentant tap av strukturell bæreevne, noe som medfører at kollapsen skjer på ekstremt kort tid [46]. Som gjengitt av Sinclair et al. [45] presiserer ASME-koden imidlertid at dersom sylinderveggen er tilstrekkelig tykk når forholdet mellom tykkelse og radius overstiger en fjerdedel kan den kompressive flytespenningen i materialet bli en viktigere og mer kritisk designgrense enn selve knekkingen. For tynnveggede sylindere under ytre trykk er knekking den primære feilmekanismen [45].

3D-printprosessen introduserer iboende strukturelle svakheter i materialet, herunder tomrom mellom filamentene og utilstrekkelig adhesjon mellom utskriftslagene [47], [48]. Disse svakhetene fungerer som lokale spenningskonsentrasjoner og gjør sylinderen mer utsatt for delaminering under belastning [47], [48]. I tillegg medfører FDM-prosessen uunngåelige imperfeksjoner, noe som fører til at klassisk teori for sylinderknekking grovt overestimerer maks styrke til 3D-printede sylindere [46]. Konvensjonelle numeriske modeller, som forenkler strukturen til et homogent materiale uten lagdelaminering, kan derfor gi en teoretisk tåleevne som ligger betydelig høyere enn de faktiske resultatene som oppnås i empiriske forsøk [47].

### 2.6.3 Aksiell kompresjon

Aksiell kompresjon innebærer at sylinderen belastes parallelt med sin egen lengdeakse. Ideelt sett er den rørformede geometrien spesielt gunstig for aksiale kompresjonslaster, ettersom en perfekt symmetrisk struktur eliminerer punkter som er utsatt for lokale spenningskonsentrasjoner. Dette resulterer i en jevn fordeling av kreftene over hele tverrsnittsarealet, noe som gir høy strukturell stivhet og resulterer i en motstand mot kompressive laster og høyere kritisk knekk-last sammenlignet med asymmetriske geometrier [49]. Selv om de kompressive hovedkreftene virker parallelt med byggeretningen og primært presser utskriftslagene sammen, vil den tynnveggede geometrien under aksiell belastning utsettes for betydelige lokale bøyemomenter og skjærkrefter. En strukturell svikt under aksiell kompresjon vil derfor typisk initiere som lokal knekking i områdene med høyest spenningskonsentrasjon, noe som introduserer høye interlaminære skjærspenninger og resulterer i global delaminering [47].

## 2.7 Overflatebehandlinger

Dette delkapittelet presenterer teorigrunnlaget for alkydemulsjoner, vinylbaserte primere og to-komponent polyester. Tabell 2 oppsummerer de kritiske egenskapene for disse tre beleggene.

Tabell 2 – Komparativ oversikt over kritiske termodynamiske, kjemiske og barrierespesifikke egenskaper for de tre utvalgte klassene av overflatebehandlinger

VISKOSITET | HERDETID | BARRIEREEGENSKAPER
ALKYD RESIN | Veldig lav | lang | Høy initiel elastisitet. Filmen fyller mikrode- formasjoner.
VINYLBASERT | Lav | kort | Trenger dypt inn i po- rer.
UMETTET POLYESTERRESIN | Veldig høy | Avhengig av blan- | Hard og mekanisk ro-
| | dingsforhold | bust overflate. Kan leg-
ges tykt for å fylle
større ujevnheter.

### 2.7.1 Alkydpolymerer

Alkydpolymerer representerer en velprøvd klasse av bindemidler. Selv om det kjemiske fundamentet har vært utnyttet industrielt i over åtti år, har den kontinuerlige utviklingen gitt materialgruppen en eksepsjonell formuleringsfrihet som i dag gjør dem høyst aktuelle for et bredt spekter av moderne overflatebehandlinger [50].

For å kunne forsegle overflatedefekter og mikroskopiske hulrom effektivt, er det avgjørende at overflatebehandlingen har en tilstrekkelig lav viskositet som muliggjør dyp inntrengning før herding. Alkydpolymerer er spesielt egnet for dette formålet fordi de i utgangspunktet kjennetegnes av lav molekylvekt og svært lav glassovergangstemperatur, noe som gir materialet en lav viskositet som tillater at belegget flyter godt ut før herding [50].

For at alkyd polymer-belegget skal oppnå sin maksimale styrke, gjennomgår det to prosesser. Den første er tørkingen der fordampning av løsemiddelet etterlater en kontinuerlig hinne. Den andre prosessen er selve herdingen via autoksidasjon [50]. Dette er en radikal kjedereaksjon drevet av oksygen fra luften og metallkatalysatorer, som resulterer i et sterkt, tredimensjonalt nettverk av kryssbindinger i belegget [50].

Uretanmodifiserte alkydbelegg karakteriseres generelt av god vann- og løsemiddelmotstand, høy hardhet, elastisitet og glans [50]. Elastisiteten i den kontinuerlige filmen gjør den i utgangspunktet godt egnet til å forsegle materialer og fylle mikrodeformasjoner. Man må imidlertid ta i betraktning at autoksidasjonen av alkyd ikke nødvendigvis stopper når filmen er tørr; over tid kan overdreven kryssbinding føre til at materialet blir stivt og sprøtt, noe som kan redusere barriereegenskapene ved langvarig eksponering for mekanisk last eller UV-stråling [51].

### 2.7.2 Vinylbaserte dispersjonsbarrierer

Vinylbaserte polymerer, herunder polyvinylacetat (PVAc) og beslektede kopolymerer, utgjør en sentral klasse av termoplastiske bindemidler for overflatebehandling og dispersjonsbarrierer. Slike syntetiske bindemidler utmerker seg ved sin evne til å danne en kontinuerlig polymerfase som gir essensielle barriereegenskaper mot inntrengning av gasser og væsker [52].

For termoplastiske vinylprimere justeres viskositeten primært ved hjelp av organiske løsemidler [51]. Dette sikrer at primeren spres godt og trenger dypt inn i porer før fordampning låser polymernettverket. I motsetning til reaktive, herdende systemer som umettet polyester og alkyd, baserer filmdannelsen i termoplastiske vinylprimere seg utelukkende på fysisk tørking via fordampning av løsemiddelet uten kjemisk kryssbinding [50].

Den tette strukturen til den fysisk tørkede polymerfilmen gir i utgangspunktet lav vanngjennomtrengelighet. For å optimalisere motstanden mot hydrostatisk inntrengning, inkorporeres det typisk uorganiske fyllstoffer i dispersjonsbelegget. Forskning på termoplastiske barrierer viser at slike mineralfyllstoffer drastisk øker tortuositeten (labyrinteffekten) i materialet, noe som fysisk forlenger diffusjonsveien for inntrengende vannmolekyler. Denne effekten maksimeres spesielt når primeren har et høyt innhold av plateformede pigmenter. I tynne belegg vil slike pigmenter tvinges til å orientere seg parallelt med substratoverflaten, og dermed skape en svært effektiv, fysisk diffusjonsbarriere mot hydrostatisk trykk [52].

### 2.7.3 Umettet Polyesterresin

Umettede polyesterresiner (UPR) utgjør en sentral klasse av herdeplaster og er i hovedsak bygget opp som lineære polykondensasjonsprodukter av umettede og mettede syrer eller anhydrider, kombinert med dioler. Karakteristisk for disse materialene er at polymerkjeden inneholder reaktive dobbeltbindinger. I et to-komponentsystem fungerer disse umettede setene i hovedkjeden som reaksjonspunkter for kopolymerisering med en reaktiv vinylmonomer (ofte styren) ved hjelp av friradikal-initiatorer [53]. Videre initieres vanligvis prosessen ved tilsetning av en peroksid-herder og akselereres av metallsalter som koboltnaphtenat for å tillate herding ved romtemperatur.

UPR består typisk av en base-resin og en reaktiv herder. I motsetning til de mer lettflytende alkyd- og vinylprimerne, utgjør fortynnede UPR-løsninger svært viskøse væsker før herding, med en typisk dynamisk viskositet i området 200–2000 cps (cps er centipoise, på SI-enhet: mPa·s) [53].

Et kritisk aspekt ved herdemekanismen til UPR, som er svært relevant ved overflatebehandling av stive FDM-strukturer, er at polymerisasjonen er assosiert med en stor volumkrymping (over 7 %) [53]. Denne krympingen kan skape store indre spenninger mellom belegget og termoplasten, noe som potensielt kan svekke adhesjonen eller generere mikroskopiske svakheter.

Til tross for at herdet UPR gir en hard og mekanisk robust overflate, er materialets langsiktige barriereegenskaper i marine miljøer begrenset. Umettede polyestere er i stor grad utsatt for fuktopptak ved langvarig nedsenkning i vann. Absorpsjon av fuktighet i resinen fører til en reduksjon av materialets glassovergangstemperatur (Tg), samt en reduksjon i elastisitetsmodul og mekanisk styrke [53].

## 2.8 Pakninger og vanntetting

Når et objekt skal operere under hydrostatisk trykk, er det avgjørende å etablere en pålitelig tetning mellom sammenføyde deler for å beskytte interne komponenter. For at en statisk tetning skal opprettholde sin funksjon, gjelder et fysisk sviktkriterium: Det maksimale kontakttrykket i pakningen må til enhver tid overstige det ytre hydrostatiske trykket [54], [55]. Dersom det indre kontakttrykket faller under det hydrostatiske trykket, vil forseglingen brytes og lekkasje inntreffe [54].

Prinsipper for tetninger

Mens flatpakninger utelukkende er avhengige av en ekstern mekanisk forspenning for å motstå trykk, utnytter O-ringer en mer avansert trykkaktivert mekanisme basert på en initiel kompresjonsgrad. Ifølge Li et al. [56] vil en økning i kompresjonsgraden forbedre tetningsevnen initielt, men det fører samtidig til en lineær økning av spenning i elastomeren. For høy kompresjon er uønsket fordi det introduserer lokale spenningskonsentrasjoner og varig restdeformasjon, noe som drastisk kan redusere pakningens levetid [56]. I tillegg drar O-ringer nytte av en hydrostatisk kilvirkning i drift; forskning viser at når det ytre vanntrykket trenger inn i mikroskopiske gap mellom overflatene på høytrykkssiden, vil selve væsketrykket bidra til å undertrykke deformasjon på høytrykkssiden og dermed fungere som en ekstra, selv-forseglende kontaktkraft [57].

Toleranser

En kritisk utfordring for tetninger i 3D-printede komponenter, er at FDM-prosessen introduserer uunngåelige geometriske imperfeksjoner og høy overflateruhet. Slike dimensjonsavvik øker faren for eksentrisk kompresjon betraktelig, der O-ringen utsettes for et asymmetrisk og ujevn kontakttrykk langs omkretsen. Hvis kontakttrykket i lokale ruhets-områder faller under det eksterne hydrostatiske trykket, skapes det umiddelbare lekkasjeveier [54]. Forskning på 3D-printede, vanntette sensorkapslinger understreker at design av slike grensesnitt krever ekstremt tette toleranser, og for å forhindre væskeinntrengning og minimere defekter benyttes det gjerne filamenter med en utskriftspresisjon ned mot 0,02 mm [58].

Materialvalg

Nitrilgummi (NBR) utgjør det primære materialvalget for statiske O-ringstetninger. For langsiktige undervannsapplikasjoner er imidlertid den kritiske feilmekanismen knyttet til materialets aldring, som ofte kvantifiseres gjennom spenningsrelasjon eller Compression Set Rate (CSR). Under langvarig kompresjon mister elastomeren gradvis sin elastiske tilbakegangskraft. Etter hvert som CSR-verdien i gummien øker, vil det initielle kontakttrykket gradvis synke; overstiger dette tapet sikkerhetsmarginen, slik at kontakttrykket faller under vanntrykket, resulterer materialaldringen i systemsvikt [54].

# 3 Metode

Dette kapittelet beskriver fremgangsmåten for produksjon og testing av FDM-printede strekkprøver i PLA, PETG og ASA. Først presenteres produksjonen av prøvestykker, inkludert geometri, utstyr og printparametere. Deretter beskrives eksponeringsoppsettet i kunstig sjøvann ved tre ulike temperaturer, før testprosedyrene for mekanisk karakterisering presenteres. Metoden er utformet for å gi reproduserbare resultater og muliggjøre systematisk sammenligning av materialenes egenskaper under ulike eksponeringsforhold.

## 3.1 Produksjon av prøvestykker

Prøvestykkene er timeglassformet type 5A-prøver i henhold til ISO 527 [59], som vist i Figur 7. Midtpartiet av prøvestykket er med hensikt utformet smalere, slik at eventuell innsnevring oppstår i måleområdet. De bredere endepartiene bidrar til at prøven kan gripes stabilt i strekkmaskinen.

Strekkprøvene ble modellert i DAK programmet Solidworks [60] i henhold til 5A-geometrien.


Figur 7 – Utforming av strekkprøver type 5A [59].

Tabell 3 – Dimensjoner av strekkprøver type 5A [59]

PRØVETYPE | 5A (MM) 5B (MM)
L | Start lengde mellom gripene | 50 ± 2 | 20 ± 2
L0 | Referanselengde | 20 ± 0,5 | 10 ± 0,2
L1 | Lengde av smal parallellsidig del | 25 ± 1 | 12 ± 0,5
L3 | Total lengde | ≥75 | ≥35
B1 | Bredde ved tynneste del | 4 ± 0,1 | 2 ± 0,1
B2 | Bredde ved endene | 12,5 ± 1 | 12 ± 0,5
R1 | Minste radius | 8 ± 0,5 | 3 ± 0,1
R2 | Største radius | 12,5 ± 1 | 3 ± 0,1
H | Foretrukket tykkelse | 2 ± 0,2 | 1 ± 0,1

## 3.2 Utstyr brukt for strekkprøver

Dette delkapittelet beskriver utstyret som ble brukt til produksjon og mekanisk testing av strekkprøvene. Først presenteres 3D-printerne som ble benyttet for fremstilling av prøvestykker i PLA, PETG og ASA. Deretter beskrives slicer-programmene og de viktigste printparameterne som lå til grunn for produksjonen. Til slutt presenteres strekkmaskinen som ble brukt til mekanisk karakterisering av prøvene etter eksponering i kunstig sjøvann.

3.2.1 3D printere

Prøvestykkene ble produsert ved hjelp av FDM-teknologi på to ulike 3D-printere, valgt ut fra materialenes temperaturkrav under prosessering. PLA og PETG ble produsert på en Prusa i3 MK3S (Figur 8), mens ASA ble produsert på en Bambu Lab X1C (Figur 9), da materialet krever et lukket kammer og kontrollert kammertemperatur for å oppnå stabile printforhold.

Prusa MK3S | Bambu X1C


Figur 8 – Prusa i3 MK3S. | Figur 9 – Bambu Lab X1C.

Prusa er en åpen FDM-printer med manuell bed-leveling støttet av automatisk
mesh-kompensasjon. Printeren har et
oppvarmet byggeplate og viftekjøling, men mangler lukket kabinett, noe som gjør den mindre egnet for temperaturfølsomme materialer som ASA. MK3S har et byggevolum på 250 × 210 × 210 mm og er kjent for høy pålitelighet og konsistente resultater med PLA og PETG [61].

Bambu er en lukket FDM-printer med automatisk bed-leveling, multifarge-støtte via AMS (Automatic Material System), og aktiv temperaturkontroll av både byggeplate og kammer. Printeren har et lukket kabinett som opprettholder stabil kammertemperatur, noe som er kritisk for printing av materialer som ASA som krever jevn temperatur for å unngå warping og lagdeling. X1C har et byggevolum på 256 × 256 × 256 mm og støtter lagtykkelser ned til 0,05 mm [62].

### 3.2.2 Print parametere

Ved 3D-printing benyttes et slicer-program for å klargjøre modellfilene før utskrift. For Prusa-skriveren ble PrusaSlicer [63] brukt, mens Bambu Studio [64] ble brukt for Bambu X1C. Slicer-programmet fungerer som et nødvendig mellomledd mellom DAK-modellen og 3D-printeren, ved at modellfilen omgjøres til maskinlesbar G-kode.

De generiske materialprofilene som allerede ligger innebygd i slicer-programmene, ble benyttet som utgangspunkt for utskriftene. Printinnstillingene oppgitt i Tabell 4 følger derfor standardprofilene for de respektive plasttypene, med unntak av antall ytre vegger. Dette ble økt fra to til seks for å oppnå mer konsistente og mekanisk robuste prøver.

ASA-prøvene måtte skrives ut på Bambu X1C, ettersom Prusa MK3S ikke har lukket kabinett og dermed ikke kan opprettholde en stabil og tilstrekkelig høy kammertemperatur for dette materialet. PLA og PETG stiller ikke tilsvarende krav til termisk kontroll under utskrift, og ble derfor skrevet ut på Prusa MK3S.

Tabell 4 – Oversikt over parameterne som ble brukt for PLA, PETG og ASA.

PARAMETER | PLA | PETG | ASA
3D PRINTER | Prusa MK3S | Prusa MK3S | Bambu X1C
SLICER | PrusaSlicer 2.9.4 | PrusaSlicer 2.9.4 | Bambu Studio 2.6.0.51
LAGTYKKELSE | 0,2 mm | 0,2 mm | 0,2 mm
FYLLINGSGRAD | 15 % | 15 % | 15 %
FYLLSTRUKTUR | Gyroid | Gyroid | Grid
ANTALL YTRE VEGGER | 6 (standard: 2) | 6 (standard: 2) | 6 (standard: 2)
DYSE TEMPERATUR | 210 ˚C | 240 ˚C | 260 ˚C

BYGGEPLATE TEMPERA-
TUR | 60 ˚C | 90 ˚C | 100 ˚C
KAMMER TEMPERATUR | x | x | 50 ˚C
AKTIV KJØLING | Ja | Ja | Ja

### 3.2.3 Strekkmaskin

Modell H50kL (Figur 10) er en elektromekanisk materialprøvingsmaskin konstruert for et bredt spekter av mekaniske tester. Den er utviklet for strekk-, trykk-, bøye- og skjærstyrketesting av både materialer og sammensatte komponenter. Den robuste konstruksjonen, kombinert med kvalitetskomponenter, bidrar til høy ytelse, brukervennlighet og lang levetid. Maskinen kan utstyres med ulike lastceller i flere kapasiteter, noe som gir presise kraftmålinger fra svært små prøver og opp til full maskinlast. Når maskinen kompletteres med passende gripere, tøyningsmåleutstyr og Tinius Olsens Horizon-programvare for dataanalyse, utgjør den et komplett og kraftig testsystem [65]. Det ble valgt å bruke en 50 kN lastcelle for alle strekkprøver og kompresjonsprøver.


Figur 10 – Tinius Olsen H50kL [65]

### 3.2.4 Vekt

Massemålinger ble utført med en AND HM-200 digital analysevekt (Figur 11). Vekten har en kapasitet på 210 g og en oppløsning på 0,1 mg, og ble brukt til å registrere vekt før og etter vann- og saltvannseksponering. Målingene ble benyttet til å beregne masseendring og vurdere vannopptak i prøvene [66].

Figur 11 - AND HM-200 digital analysevekt [66].

## 3.3 Prøveforberedelse og eksponering

For å sikre sammenlignbare resultater ble det etablert standardiserte prosedyrer for fremstilling av kunstig sjøvann, håndtering av prøver, eksponeringsbetingelser og opptak av prøver gjennom forsøksperioden. Det ble også utviklet et organiseringssystem for hvordan prøvene ble organisert og identifisert for å redusere risikoen for å redusere risikoen for kontaminasjon og forveksling under testarbeidet.

### 3.3.1 Fremstilling av kunstig sjøvann

Fremstillingen av det kunstige sjøvannet ble laget på renrom (Figur 12) for å redusere risikoen for forurensning. Det ble brukt målesylindere til å måle opp totalt ni liter destillert vann fordelt på tre kanner, hvor følgende salter ble tilsatt: natriumklorid, magnesiumklorid, natriumsulfat og kalsiumklorid. Sammensetningen av sjøvannet ble laget i henhold til ISO-15711 [67]. Tabell 5 viser mengdene som er oppgitt i standarden for 3L kunstig sjøvann.

Tabell 5 – Eksakte blandingsforhold for 3L kunstig sjøvann i henhold til ISO-15711

Kjemikalier | Mengde (g)
Sodium Chloride (NaCl) | 69,0
Magnesium Chloride (MgCl2) | 29,4
Sodium sulfate (NaSo4) | 26,7
Calsium Chloride (CaCl2) | 3,6

Tabell 6 viser de ulike blandingsforholdene av kjemikalier fordelt på tre kanner. Oppmåling av kjemikalier ble utført med en laboratorievekt med en presisjon på fire desimaler. Etter at løsningene var ferdigblandet, ble kannene ristet forsiktig for å oppnå en homogen blanding. Det kunstige sjøvannet stod inne på renrom til lagring i to uker, før prøvene ble satt i romtemperatur og varmeskap.

Tabell 6 – Oversikt over blandingsforhold fordelt på de tre kannene som ble brukt.

Kjemikalier | Kanne 1 (g) | Kanne 2 (g) | Kanne 3 (g)
Sodium Chloride (23,0 g/L) | 69,08 | 68,60 | 68,74
Magnesium Chloride (9,8 g/L) | 28,82 | 28,94 | 29,08
Sodium sulfate anhydrous (8,9 g/L) | 26,50 | 27,30 | 26,45
Calsium Chloride (1,2 g/L) | 3,58 | 3,50 | 3,55

Figur 12 – Blanding av kunstig sjøvann inne på renrom

### 3.3.2 Klargjøring av prøver

Alle prøvene ble veid individuelt med en vekt som hadde nøyaktighet på fire desimaler. Det ble 3D-printet et stativ som inneholdt fem prøver per stativ, med en avstand på 2 mm mellom hver prøve. Dette ble gjort for å hindre kontakt mellom prøvene når de skulle i vann. Stativene bestod av to holdere slik at prøvene stod stabilt gjennom hele testprosessen (Figur 13 a). Stativene ble printet i samme materiale som prøvene. Holderen ble merket med en prøveID som bestod av en bokstav og to tall. Bokstaven beskrev hvilken plasttype det var, det første tallet beskrev hvilken temperatur prøven var utsatt for, mens det siste tallet beskrev hvilket prøvesett det var, se Appendiks C. Prøvene som hadde ID som sluttet på et oddetall ble tørket i 48 timer før de ble strukket og prøvene som sluttet på et partall ble strukket umiddelbart etter opptak. I tillegg til å ha ID-nummer hadde alle stativ et markert hakk (Figur 13 b), der antall hakk indikerte hvilken opptaksuke holderen tilhørte. Dette gjorde det enklere å identifisere hvilke prøver som skulle tas opp og reduserte risikoen for forveksling av prøvesett.


a) b)

Figur 13 – Testoppsett. a) Strekkprøver montert på stativ, b) Stativene for et helt prøvesett.

### 3.3.3 Rengjøring av ASA

For å hindre at ASA-prøvene løsnet fra byggeplaten under printing ble det benyttet 3DLAC adhesive spray [68]. Sprayen etterlot et hvitt belegg på prøvenes kontaktflate mot platen, som i størst mulig grad ble fjernet med mikrofiberklut og varmt vann, men noe av belegget lot seg ikke vaske av vist i Figur 14. Denne sprayen ble ikke brukt på PLA eller PETG.


Figur 14 – ASA med limbelegg 3DLAC før og etter vask med microfiber klut

### 3.3.4 Saltvannseksponering

Prøvene ble plassert stående langs innsiden av norgesglassene for å unngå kontakt mellom prøvene. Det ble brukt totalt ni norgesglass med lokk for alle prøvene, tre glass for hver temperaturbetingelse (20˚ C, 40˚ C og 60˚ C). For å unngå kryss-kontaminering mellom de ulike plasttypene inneholdt hvert glass kun en materialtype.

Hvert av de ni glassene inneholdt åtte prøveholdere (Figur 15 a), med fem prøver i hver holder. Glassene som inneholdt PLA og PETG ble fylt med 600 ml kunstig sjøvann og ASA glassene ble fylt med 650 ml for at prøvene skulle bli fullstendig nedsenket.

Prøvene ble hentet ut ved fire perioder med et opptaksintervall på tre uker. I perioden mellom opptakene ble det sørget for å ha ukentlige kontroller av varmeskapene for å tilse at temperaturene holdt seg stabile og at glassene så intakte ut. Glassene ble kun åpnet under uttak av prøver og ble satt tilbake i varmeskap (Figur 15 b).


a) b)

Figur 15 – Oppsett til varmekammer. a) Oppsett av hvordan prøvene ligger organisert i glassene, b) Prøvene satt inn i varmeskap.

### 3.3.5 Håndtering av prøver ved opptak

Ved hvert prøveopptak ble det tatt opp to sett per temperatur, med fem strekkprøver i hvert sett. Prøvene ble tatt opp fra det kunstige sjøvannet med hansker for å unngå kontaminasjon. Prøvene ble sortert på et ark, for å holde våte og tørre prøver adskilt før veiing. Før veiing av prøver ble de skylt i destillert vann og klapptørket med et absorberende papir. Prøve nummer en i hvert sett ble dog ikke skylt for å bevare saltpartikler til mikroskopering. De våte prøvene ble strukket samme dag som opptak. Prøver som skulle tørkes ble lagt på et ark i henhold til gjeldene tørkeprosedyre, se Figur 16.


Figur 16 – Etter at prøvene ble tatt opp ble de systematisert etter materiale, om prøvene var våte eller tørre og etter temperatur.
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

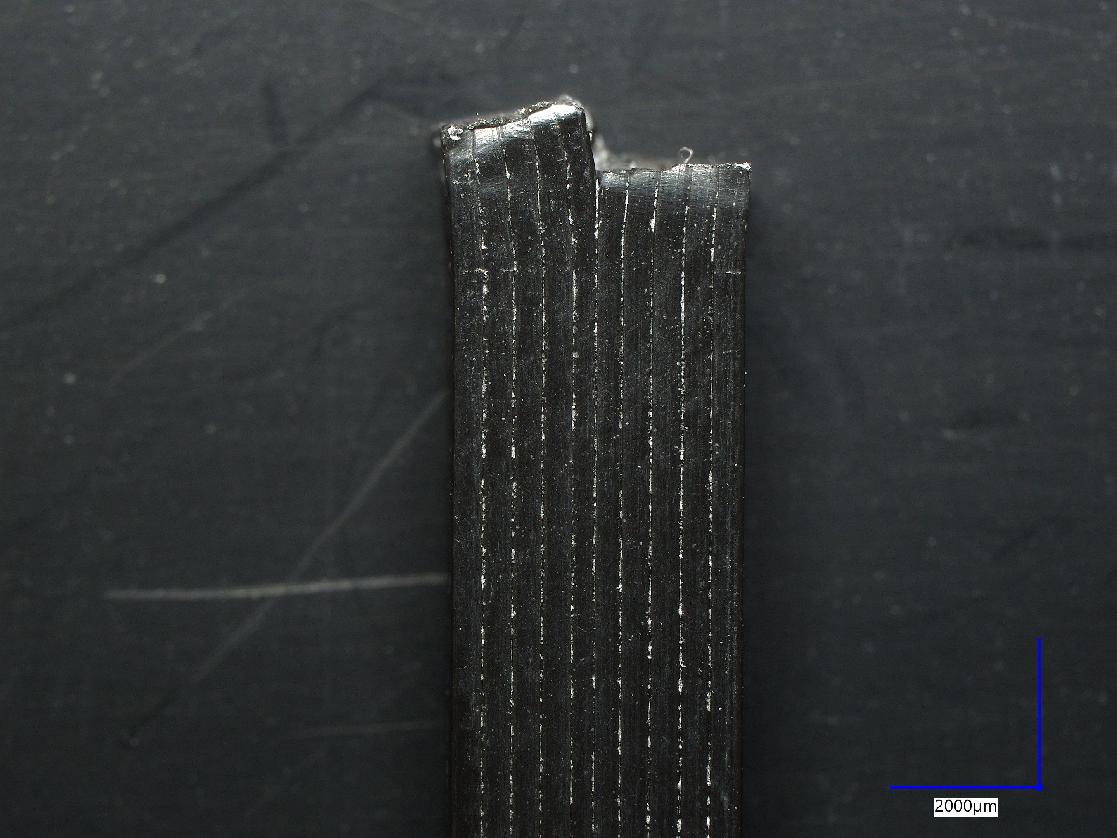
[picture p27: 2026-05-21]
figurer/mikroskopi/PLA 036.jpg

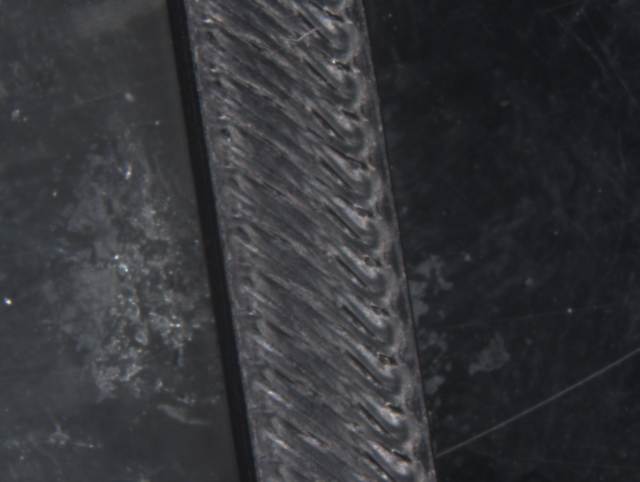
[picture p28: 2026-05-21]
figurer/mikroskopi/C_1_2_2.jpg

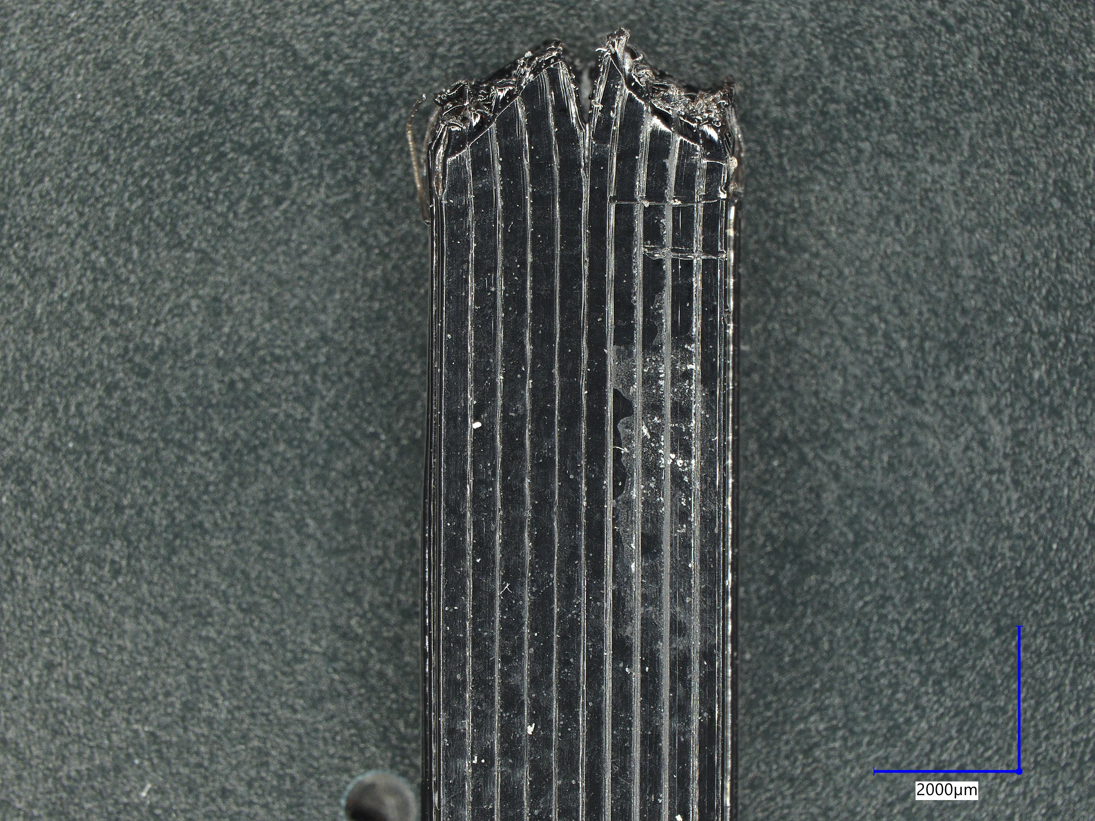
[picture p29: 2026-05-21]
figurer/mikroskopi/PETG 019.jpg

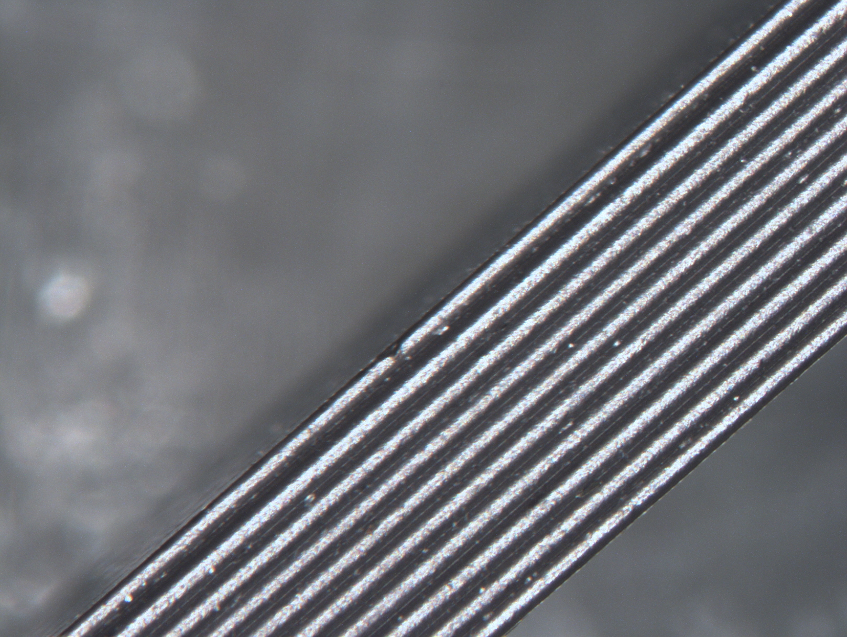
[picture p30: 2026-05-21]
figurer/mikroskopi/C_1_1_1_c.jpg

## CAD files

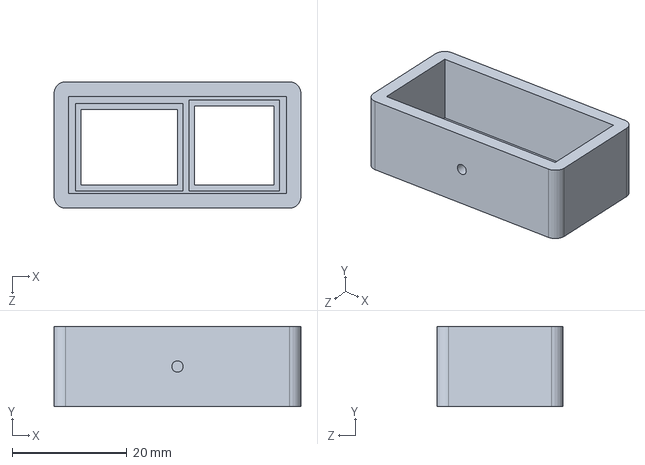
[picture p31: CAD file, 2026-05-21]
cad/prototypekapsling/hus_mindre_hull.SLDPRT
43.0 x 14.0 x 22.0 mm

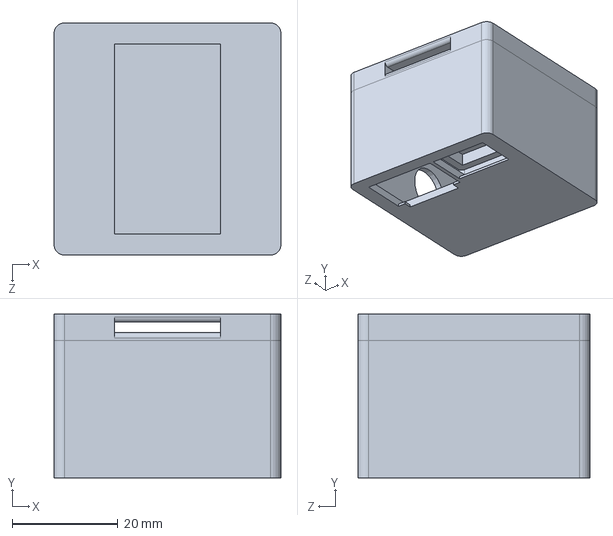
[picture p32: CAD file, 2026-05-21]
cad/prototypekapsling/Klokke V2.SLDPRT
43.0 x 31.0 x 44.0 mm

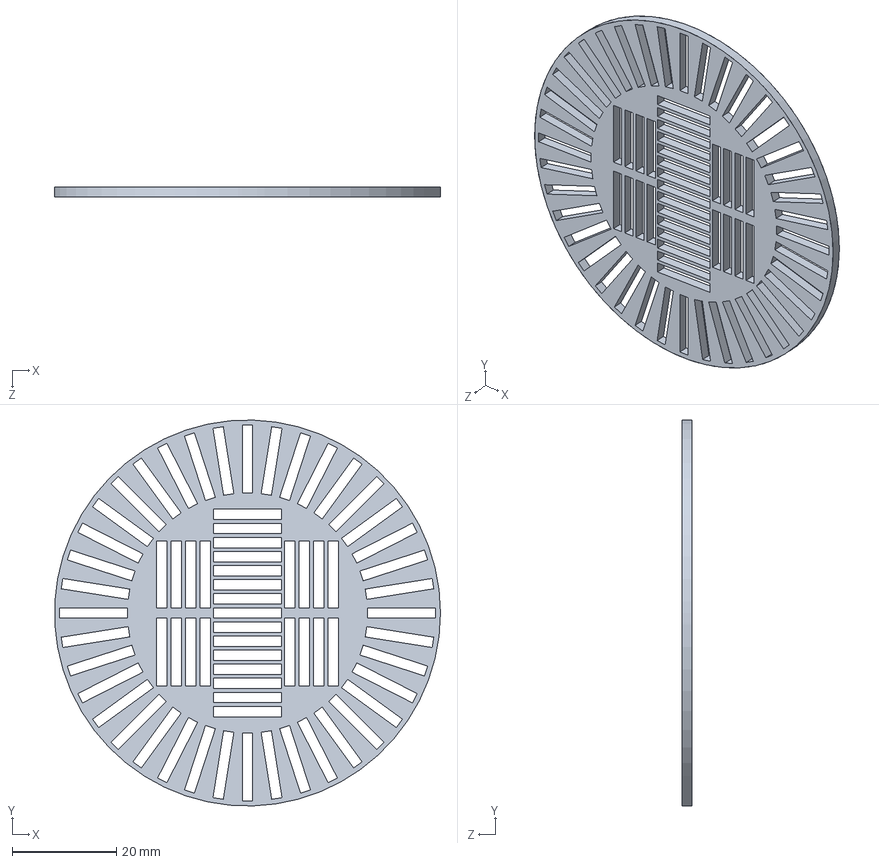
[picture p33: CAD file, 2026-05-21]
cad/Strekkprøver/Stativ for trekkprøver V3.SLDPRT
74.0 x 74.0 x 2.00 mm

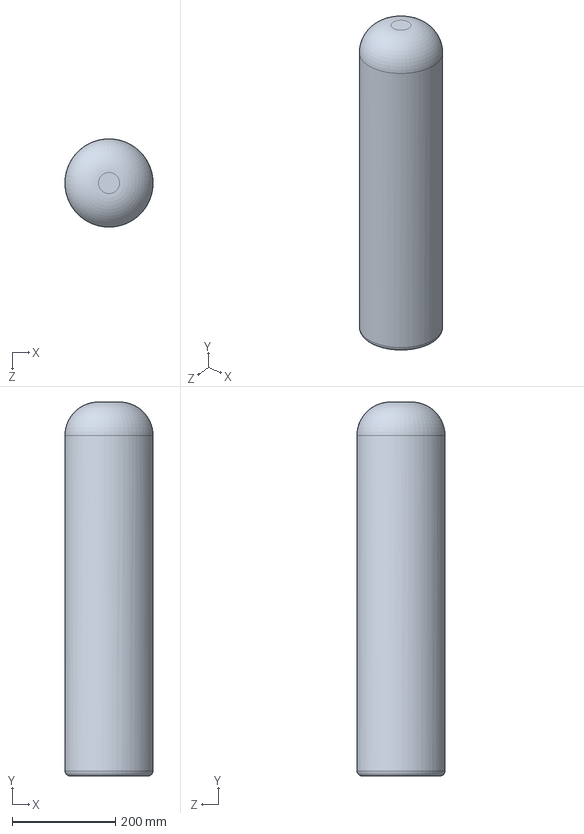
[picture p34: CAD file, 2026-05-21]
cad/prototypekapsling/gasstank.SLDPRT
171.0 x 725.0 x 171.0 mm

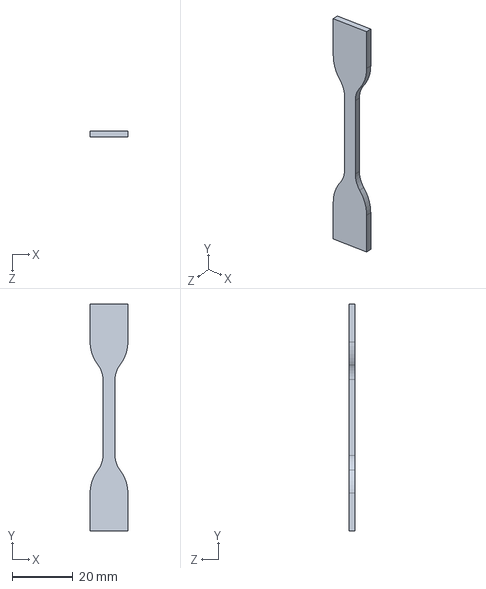
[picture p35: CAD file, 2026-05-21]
cad/Strekkprøver/Standard Strekkprøve.SLDPRT
12.5 x 75.0 x 2.00 mm

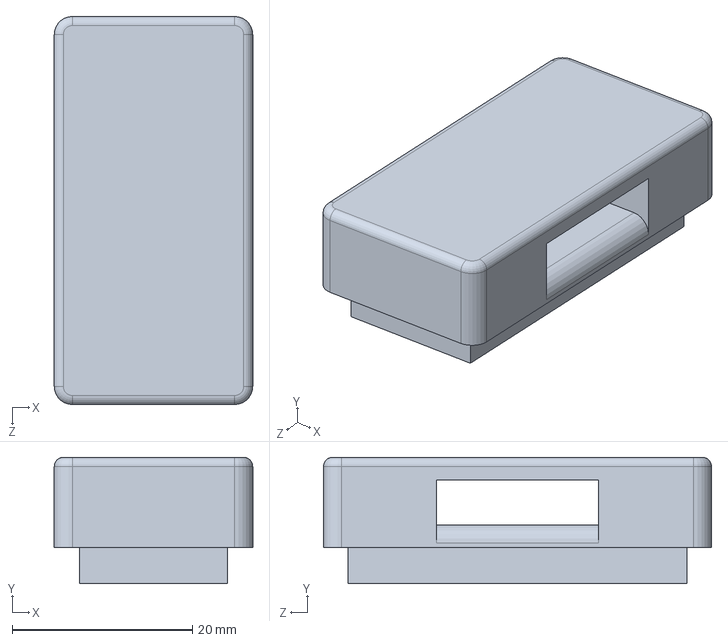
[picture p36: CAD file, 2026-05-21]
cad/prototypekapsling/lokk.SLDPRT
22.0 x 14.0 x 43.0 mm

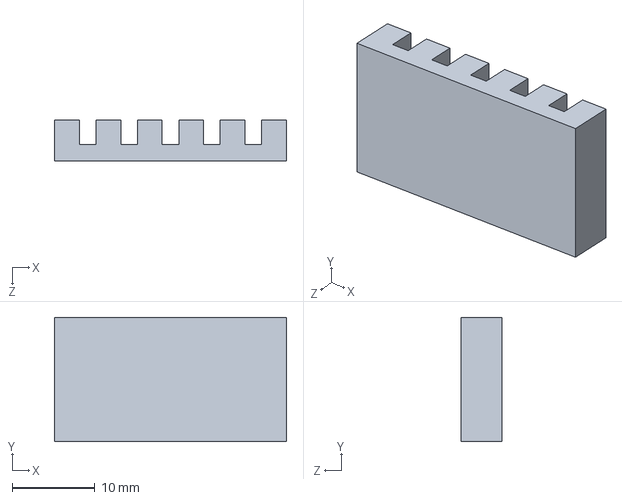
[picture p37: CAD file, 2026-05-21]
cad/Strekkprøver/Stativ for trekkprøver.SLDPRT
28.0 x 15.0 x 5.00 mm

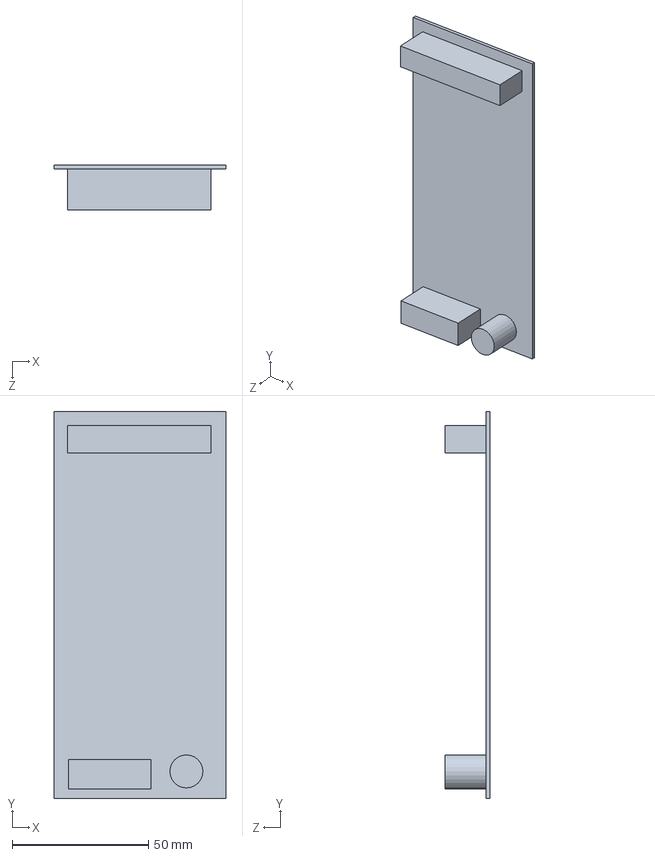
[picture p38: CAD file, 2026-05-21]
cad/prototypekapsling/PCB Hjerne.SLDPRT
63.0 x 142.0 x 16.5 mm

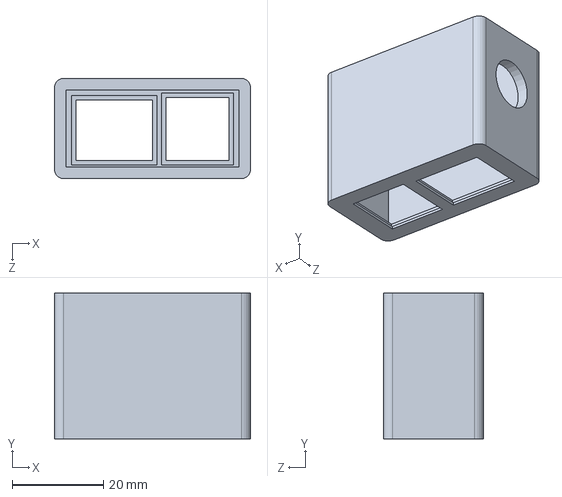
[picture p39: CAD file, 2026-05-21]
cad/prototypekapsling/Part1.SLDPRT
43.0 x 32.0 x 22.0 mm

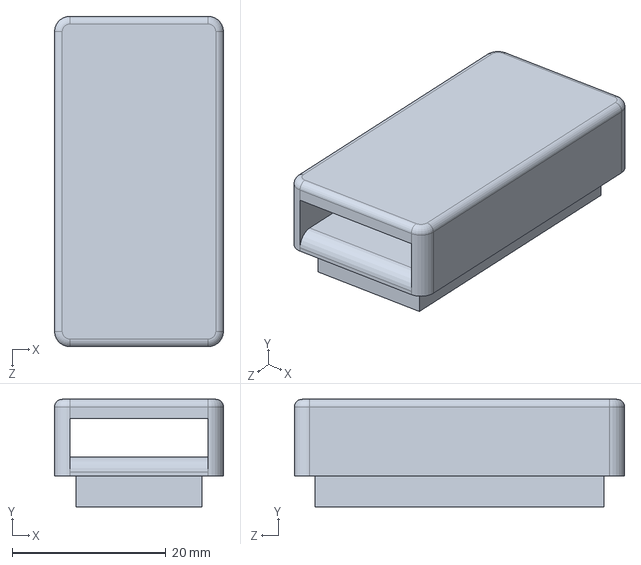
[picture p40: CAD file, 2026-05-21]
cad/prototypekapsling/lokk_til_mindre_versjonSLDPRT.SLDPRT
22.0 x 14.0 x 43.0 mm

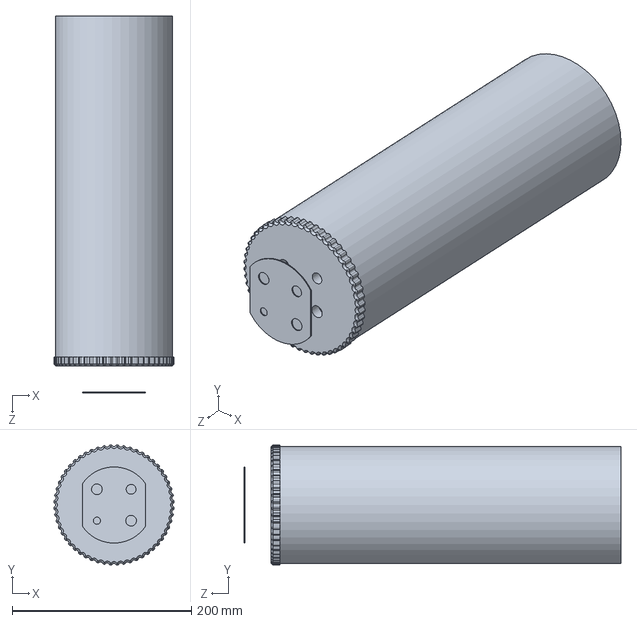
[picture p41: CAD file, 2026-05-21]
cad/prototypekapsling/Batteri cradle Med Lokk.SLDPRT
133.8 x 133.8 x 420.1 mm

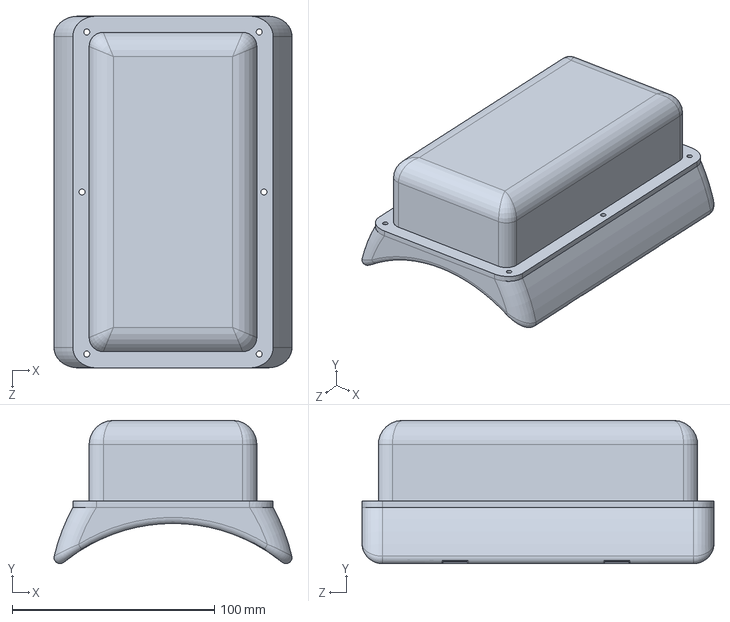
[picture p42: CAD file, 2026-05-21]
cad/prototypekapsling/PCB holder V1.SLDPRT
117.7 x 70.9 x 174.0 mm

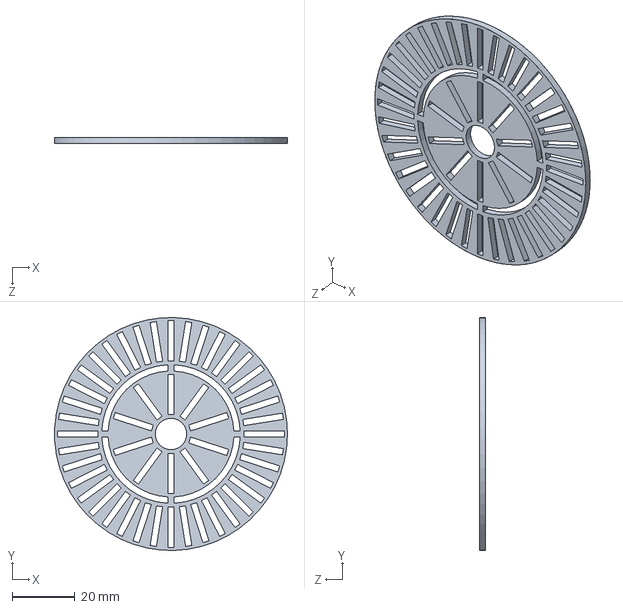
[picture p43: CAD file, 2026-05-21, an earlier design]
cad/Strekkprøver/Stativ for trekkprøver V2.SLDPRT
74.0 x 74.0 x 2.00 mm

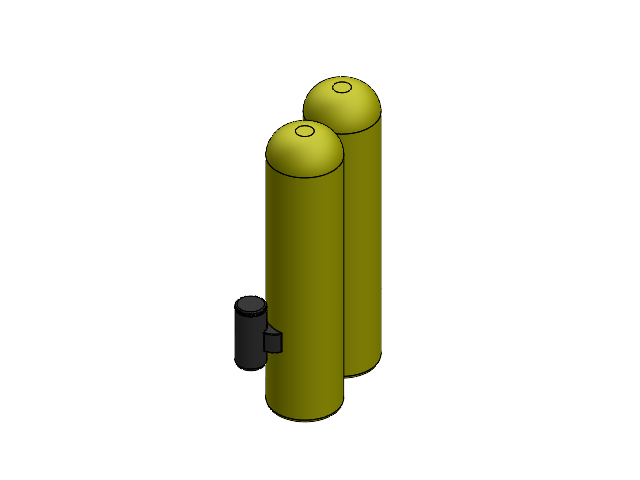
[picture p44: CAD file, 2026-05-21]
cad/prototypekapsling/Assembly boks på tank.SLDASM
gasstank x 2
PCB holder V1
PCB Hjerne
Holder rundt container
Rundt Bottom
Rundt lokk

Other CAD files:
cad/prototypekapsling/assy_klokke.SLDASM
cad/Strekkprøver/Standard Strekkprøve Tegning.SLDDRW
cad/Strekkprøver/Stativ A 1-1.SLDDRW

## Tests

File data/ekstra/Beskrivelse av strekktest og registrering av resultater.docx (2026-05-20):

Beskrivelse av strekktest og registrering av resultater

Strekktest på plast gjennomføres etter standard ISO 527.

1) Prøve-ID og sporbarhet.

Prøvene identifiseres med Prøve-ID på format: [Bokstav]–[Temperaturkode]–[Løpenummer],

Viktig sporbarhet i holder (5 prøver):

- Resultatarket er lagt opp slik at samme Prøve-ID står fem ganger under hverandre. Disse fem radene representerer spor 1–5 i holderen.
- Rad 1 = prøven nærmest ID-enden, deretter fylles/registreres i rekkefølge bortover (spor 2 → spor 5).

2) Forberedelser før test.

1. Klargjør prøver etter valgt tilstand
  - Gjør en visuell sjekk
  - Se etter tydelige skader/sprekkdannelser eller deformasjon. Notér avvik.
2. Mål geometri.
  - Mål bredde og tykkelse i innsnevringen flere steder.

4) Oppsett av testmaskin

- Skriv inn PrøveID og dimmensjoner inn i programmet

5) Gjennomføring av strekktest (per prøve)

1. Nullstill kraft og forflytning/strain i programvaren.
2. Start testen og la den gå til brudd.
3. Lagre testkurven (kraft–forflytning eller spenning–tøyning) med PrøveID og prøve nummer.
4. Notér eventuelle strekk feil. DVS glipp i grep, brudd utenfor målesonen osv. Disse prøvene skal noteres og ikke brukes i resultatgrunnlaget.

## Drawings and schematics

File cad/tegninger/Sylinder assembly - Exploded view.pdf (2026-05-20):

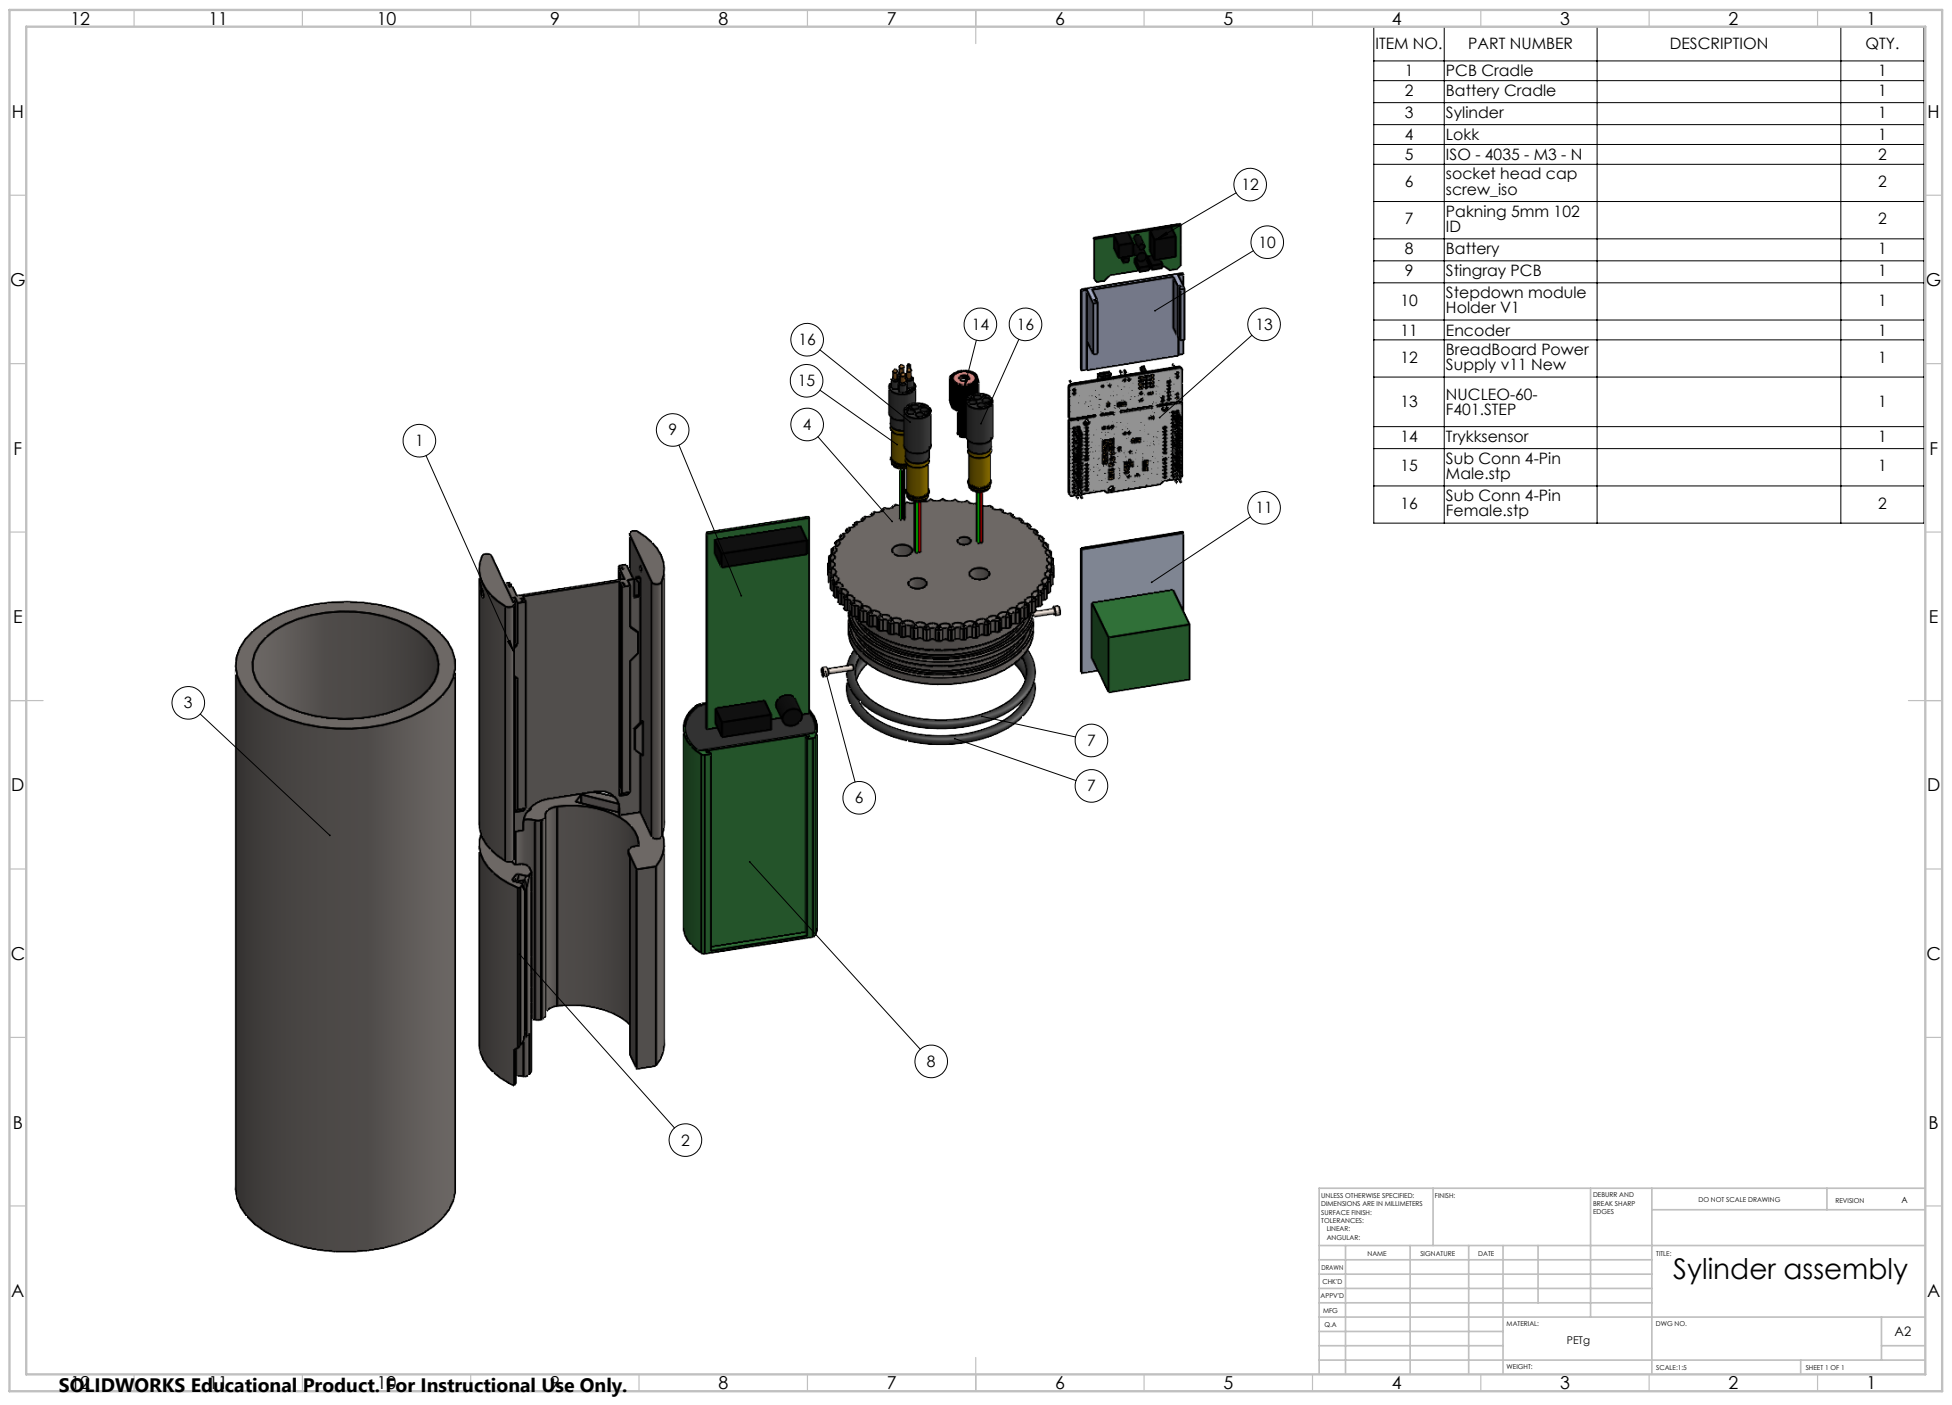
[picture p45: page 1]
SCALE:1:5; SHEET 1 OF 1

ITEM NO. | PART NUMBER | DESCRIPTION | QTY.
1 | PCB Cradle | | 1
2 | Battery Cradle | | 1
3 | Sylinder | | 1
4 | Lokk | | 1
5 | ISO - 4035 - M3 - N | | 2
6 | socket head cap screw_iso | | 2
7 | Pakning 5mm 102 ID | | 2
8 | Battery | | 1
9 | Stingray PCB | | 1
10 | Stepdown module Holder V1 | | 1
11 | Encoder | | 1
12 | BreadBoard Power Supply v11 New | | 1

13 | NUCLEO-60-F401.STEP | | 1

14 | Trykksensor | | 1
15 | Sub Conn 4-Pin Male.stp | | 1
16 | Sub Conn 4-Pin Female.stp | | 2

UNLESS OTHERWISE SPECIFIED: DIMENSIONS ARE IN MILLIMETERS SURFACE FINISH: TOLERANCES: LINEAR: ANGULAR: | FINISH: | DEBURR AND BREAK SHARP EDGES | DO NOT SCALE DRAWING | REVISION A

NAME | SIGNATURE | DATE | | | | TITLE: Sylinder assembly

DRAWN
CHK'D
APPV'D
MFG
Q.A | | | | MATERIAL: PETg | DWG NO. | A2

SOLIDWORKS Educational Product. For Instructional Use Only.

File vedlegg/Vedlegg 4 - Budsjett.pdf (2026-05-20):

# Budsjett

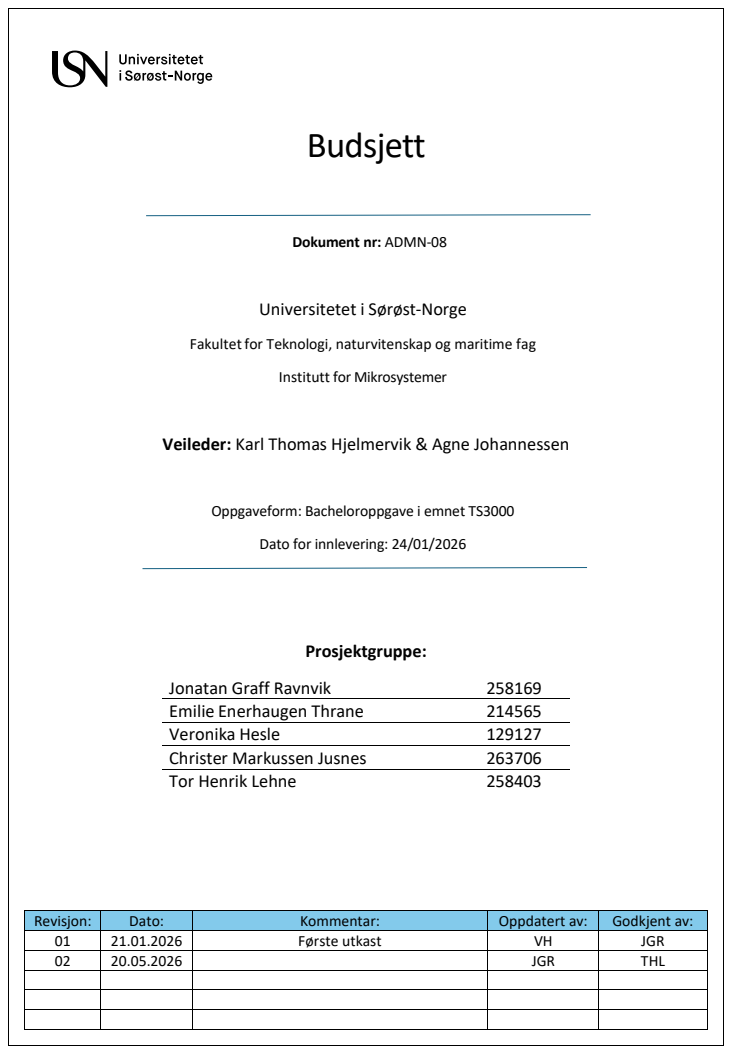
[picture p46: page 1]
Prosjektgruppe:; Jonatan Graff Ravnvik; Emilie Enerhaugen Thrane; Veronika Hesle; Christer Markussen Jusnes; Tor Henrik Lehne

Dokument nr: ADMN-08

Universitetet i Sørøst-Norge

Fakultetfor Teknologi, naturvitenskap og maritime fag

Institutt for Mikrosystemer

Veileder: Karl Thomas Hjelmervik & Agne Johannessen

Oppgaveform: Bacheloroppgave i emnet TS3000
Dato for innlevering: 24/01/2026

Revisjon: | Dato: | Kommentar: | Oppdatert av: | Godkjent av:
01 | 21.01.2026 | Første utkast | VH | JGR
02 | 20.05.2026 | | JGR | THL

## Utstyr og forbruksmateriell

Utstyr | Produsent | Antall Pris per enhet Kr Total kostnad Kr
Norgesglass, 0,7l | Hadeland Glassverk | 9 | 78.58 | 707.22
Temperatur- og fuktighetslogger | Clas Ohlson | 3 | 199 | 597
Polyester 0,5kg | Biltema | 1 | 99 | 99
Polyester Herder | Biltema | 1 | 64 | 64
Bengalack | Monter | 1 | 149 | 149
3D-filament:
PLA-HS 1kg | Polyalekemi | 1 | 239 | 239
PLA+ 1kg | eSUN | 2 | 219 | 438
PETG Basic 1kg | Polyalekemi | 3 | 249 | 747
PETG basic 3kg | Polyalekemi | 1 | 699 | 699
ASA Basic Black 1kg | Polyalekemi | 3 | 249 | 747
ASA Basic Grey 1kg | Polyalekemi | 1 | 249 | 249
ASA Basic White 1kg | Polyalekemi | 1 | 249 | 249
Sum | | | | 4984.22
Øvrige utgifter til kjemikalier dekkes av USN.

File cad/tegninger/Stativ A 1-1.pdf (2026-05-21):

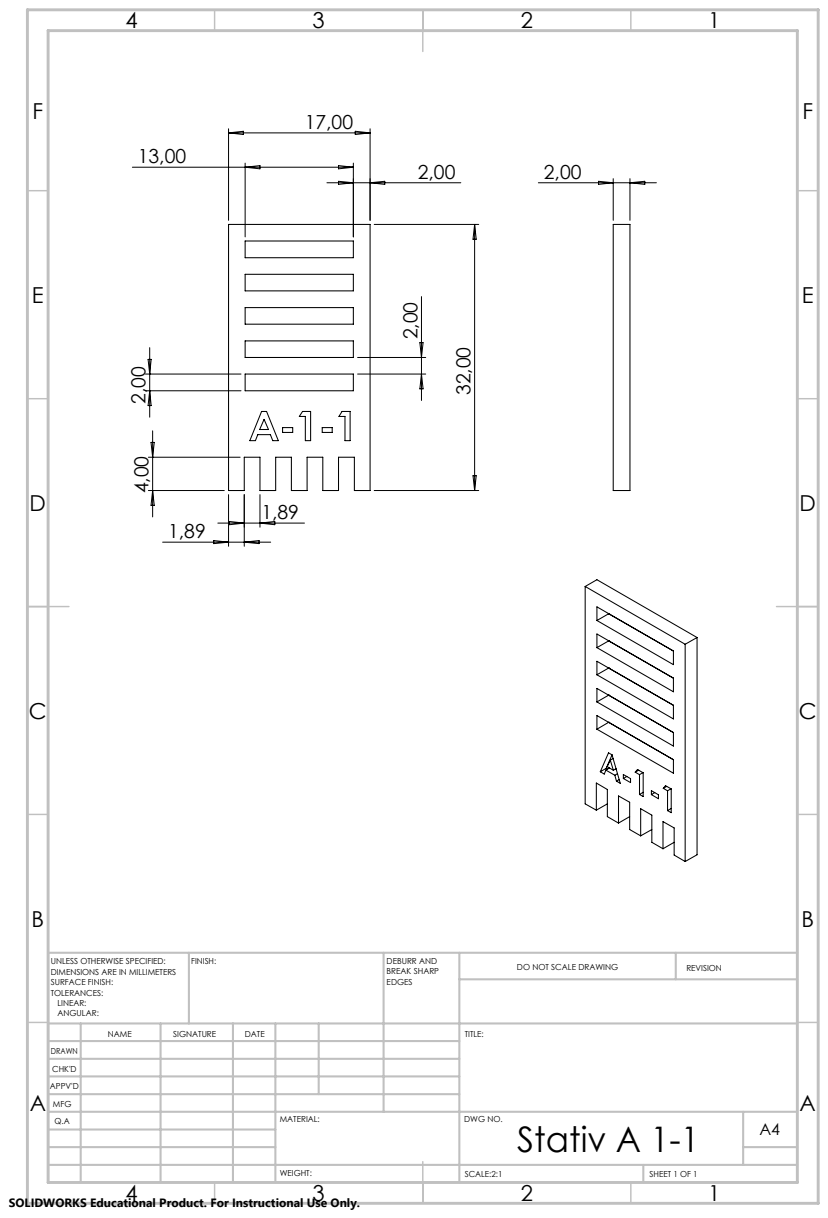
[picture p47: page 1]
FINISH:; DEBURR AND; BREAK SHARP; DO NOT SCALE DRAWING; REVISION; SCALE:2:1; SHEET 1 OF 1

UNLESS OTHERWISE SPECIFIED:
DIMENSIONS ARE IN MILLIMETERS
SURFACE FINISH:
TOLERANCES:
LINEAR:
ANGULAR:

NAME | SIGNATURE | DATE | | | | TITLE:

DRAWN
CHK'D
APPV'D
MFG
Q.A | | | | MATERIAL: | DWG NO. Stativ A 1-1 | A4

SOLIDWORKS Educational Product. For Instructional Use Only.

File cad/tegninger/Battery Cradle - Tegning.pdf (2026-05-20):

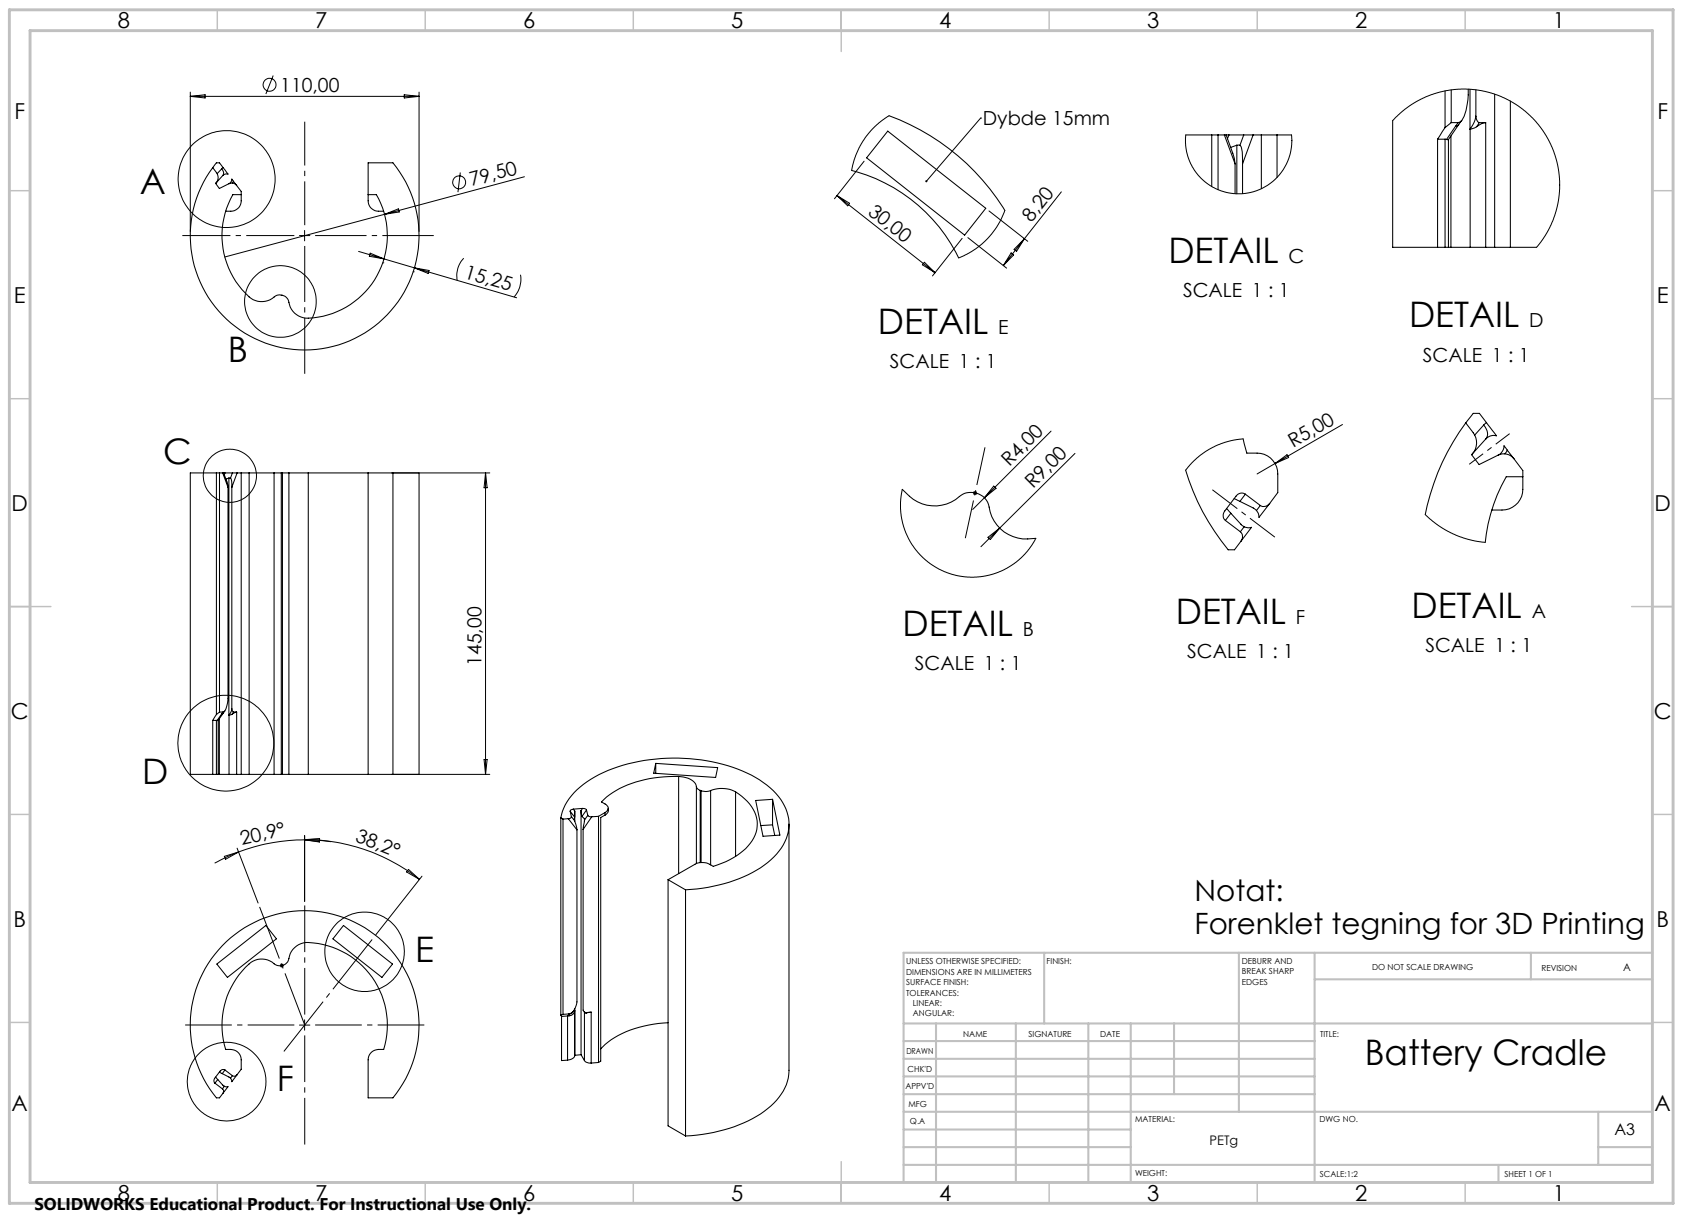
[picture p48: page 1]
DETAIL E; SCALE 1 : 1; Dybde 15mm; DETAIL F; DETAIL D; DETAIL A; DETAIL C; DETAIL B; FINISH:; DEBURR AND; BREAK SHARP; DO NOT SCALE DRAWING; REVISION; SCALE:1:2; SHEET 1 OF 1

Notat:
Forenklet tegning for 3D Printing

UNLESS OTHERWISE SPECIFIED:
DIMENSIONS ARE IN MILLIMETERS
SURFACE FINISH:
TOLERANCES:
LINEAR:
ANGULAR:

NAME | SIGNATURE | DATE | | | | TITLE: Battery Cradle

DRAWN
CHK'D
APPV'D
MFG
Q.A | | | | MATERIAL: PETg | DWG NO. | A3

SOLIDWORKS Educational Product. For Instructional Use Only.

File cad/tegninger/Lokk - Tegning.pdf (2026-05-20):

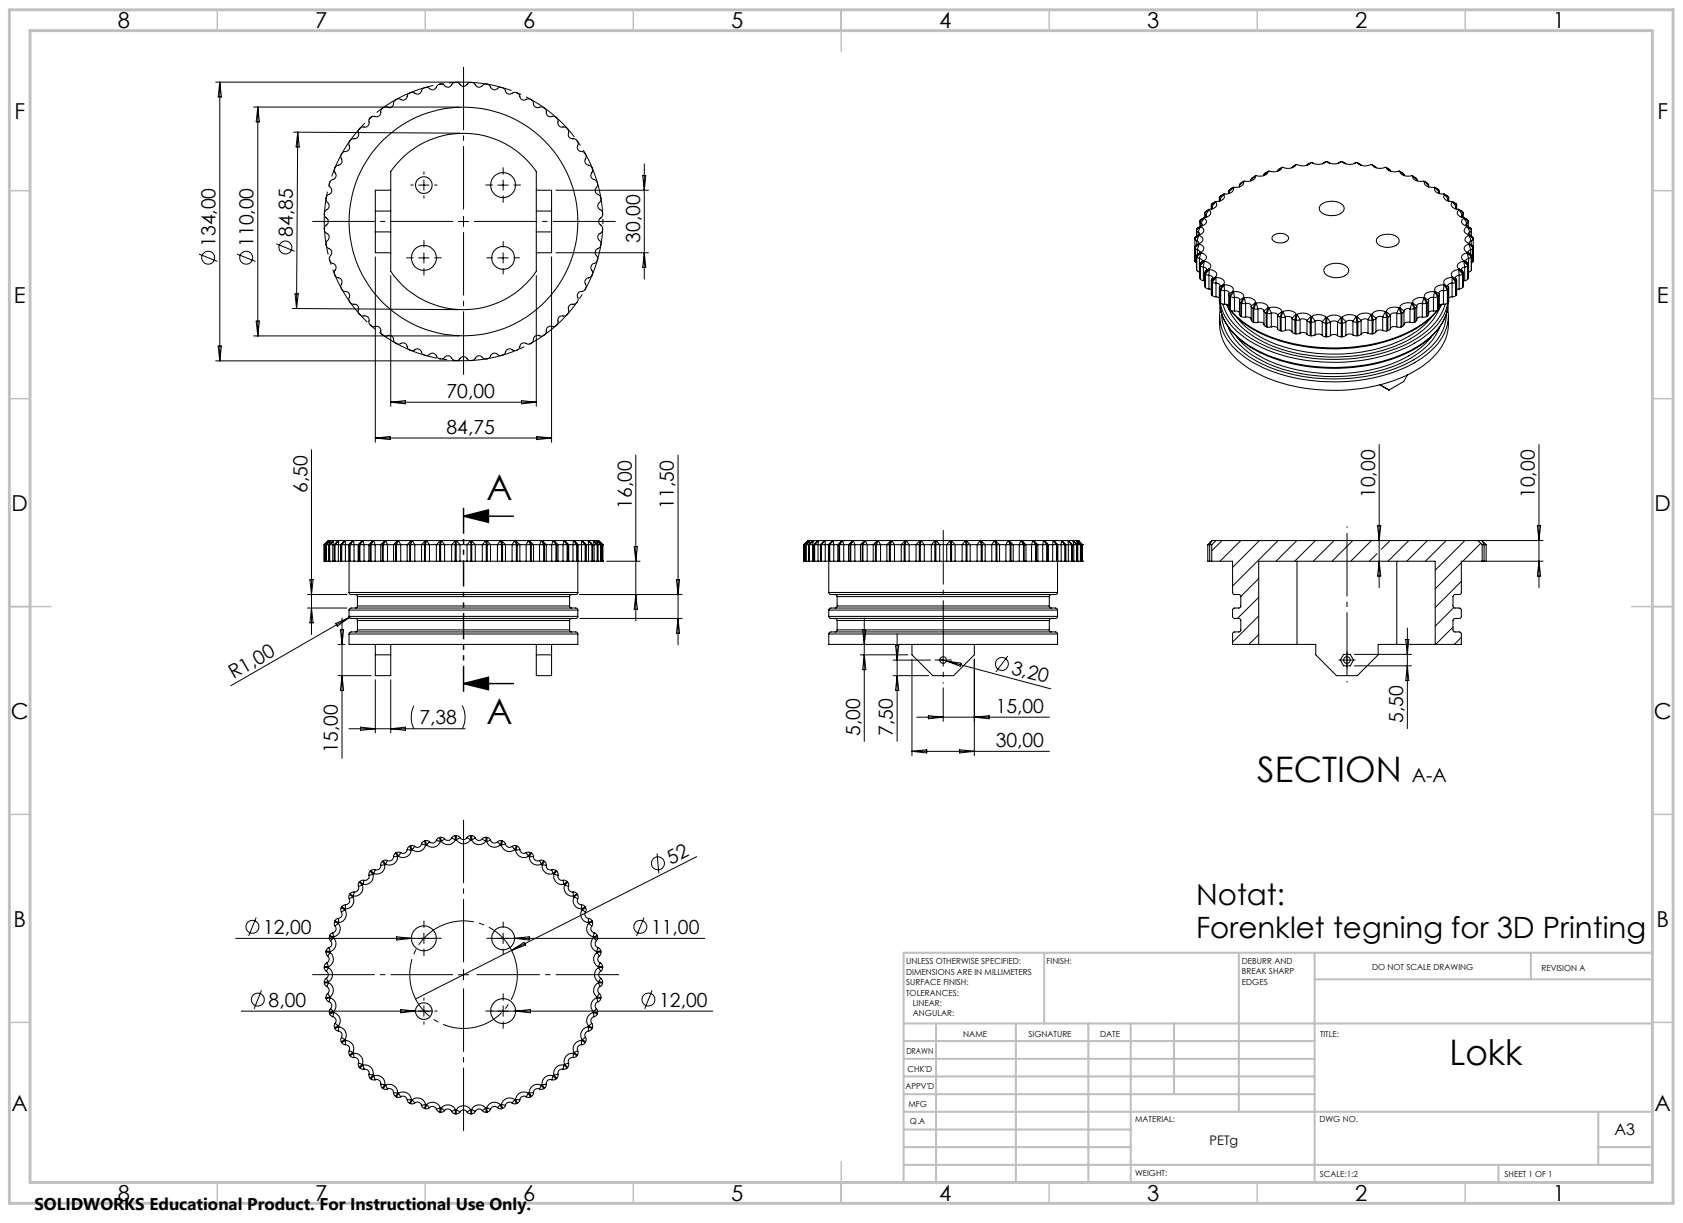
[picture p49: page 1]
SECTION A-A; FINISH:; DEBURR AND; BREAK SHARP; DO NOT SCALE DRAWING; REVISION A; SCALE:1:2; SHEET 1 OF 1

Notat:
Forenklet tegning for 3D Printing

UNLESS OTHERWISE SPECIFIED:
DIMENSIONS ARE IN MILLIMETERS
SURFACE FINISH:
TOLERANCES:
LINEAR:
ANGULAR:

NAME | SIGNATURE | DATE | | | | TITLE: Lokk

DRAWN
CHK'D
APPV'D
MFG
Q.A | | | | MATERIAL: PETg | DWG NO. | A3

SOLIDWORKS Educational Product. For Instructional Use Only.

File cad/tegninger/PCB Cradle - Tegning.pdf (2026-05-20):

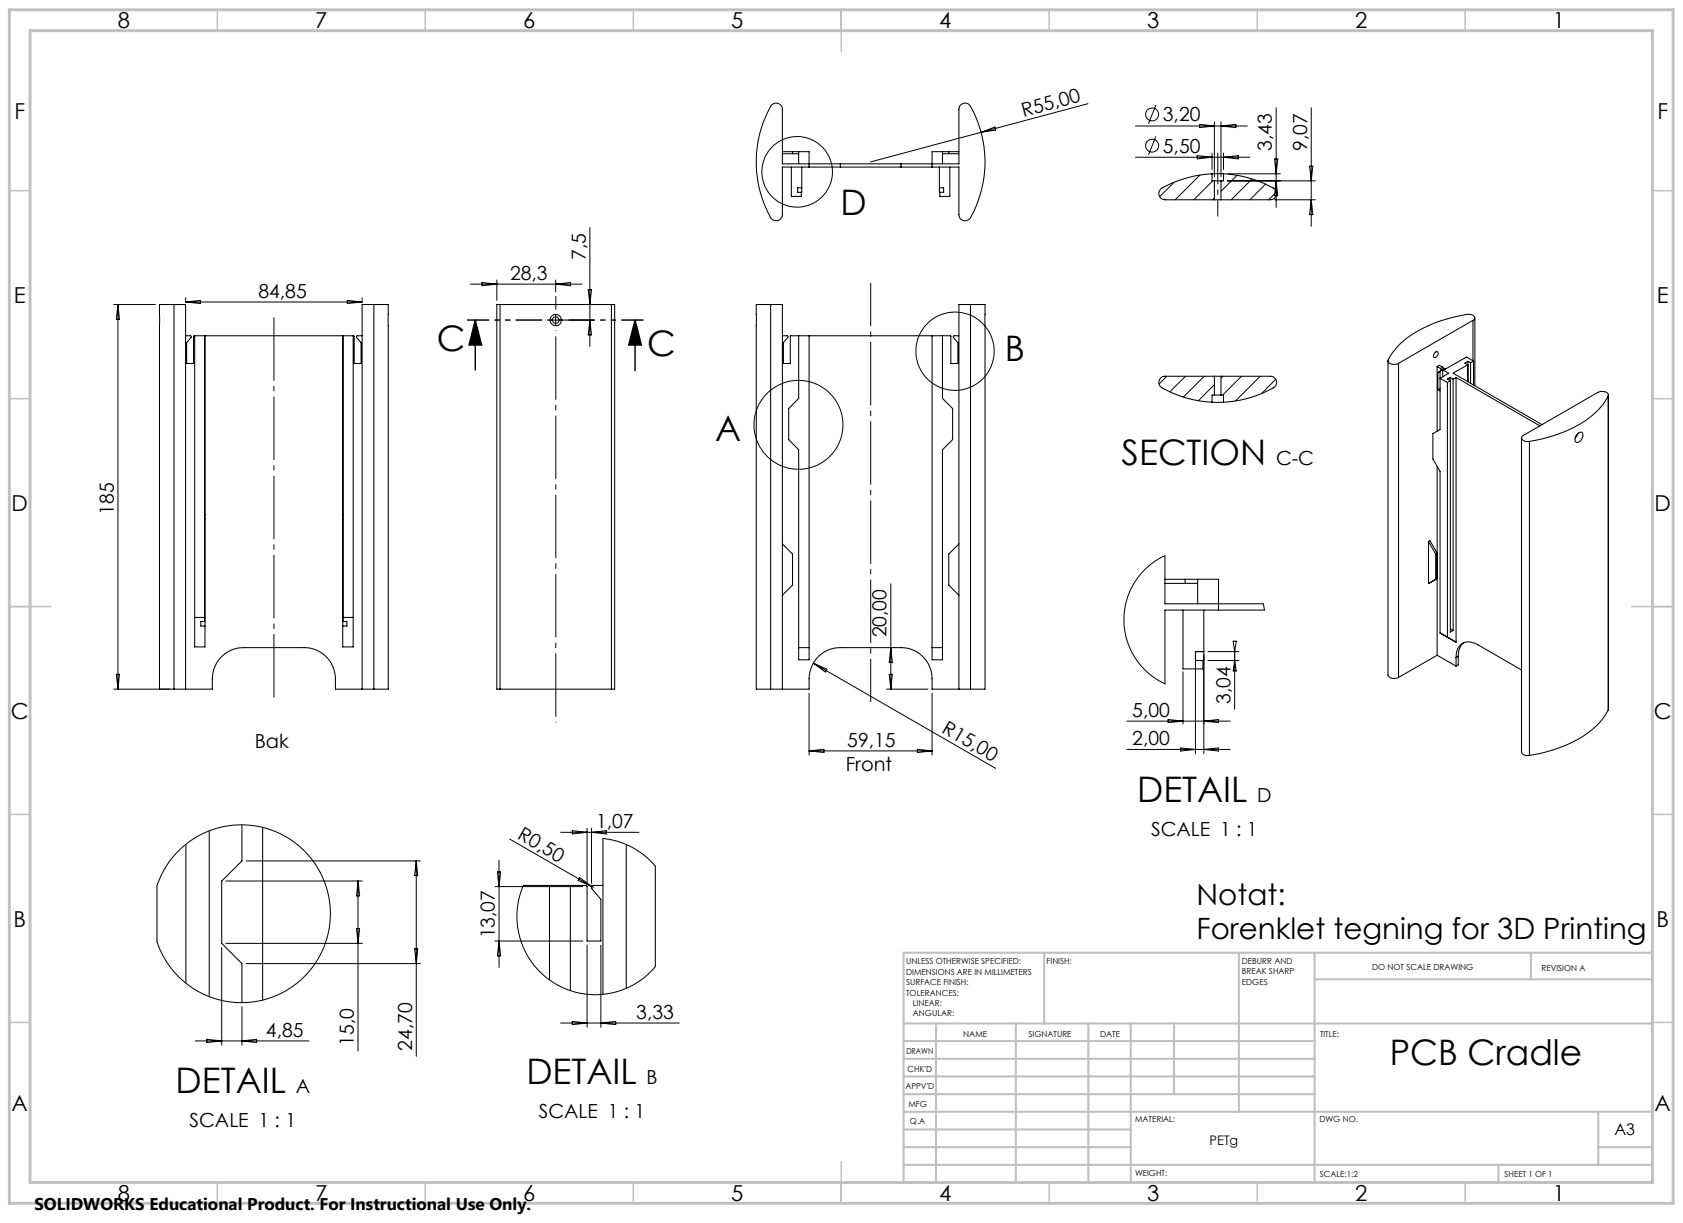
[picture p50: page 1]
DETAIL B; SCALE 1 : 1; DETAIL A; SECTION C-C 3,04; DETAIL D; FINISH:; DEBURR AND; BREAK SHARP; DO NOT SCALE DRAWING; REVISION A; SCALE:1:2; SHEET 1 OF 1

SCALE 1 : 1
Notat:
Forenklet tegning for 3D Printing

UNLESS OTHERWISE SPECIFIED:
DIMENSIONS ARE IN MILLIMETERS
SURFACE FINISH:
TOLERANCES:
LINEAR:
ANGULAR:

NAME | SIGNATURE | DATE | | | | TITLE: PCB Cradle

DRAWN
CHK'D
APPV'D
MFG
Q.A | | | | MATERIAL: PETg | DWG NO. | A3

SOLIDWORKS Educational Product. For Instructional Use Only.

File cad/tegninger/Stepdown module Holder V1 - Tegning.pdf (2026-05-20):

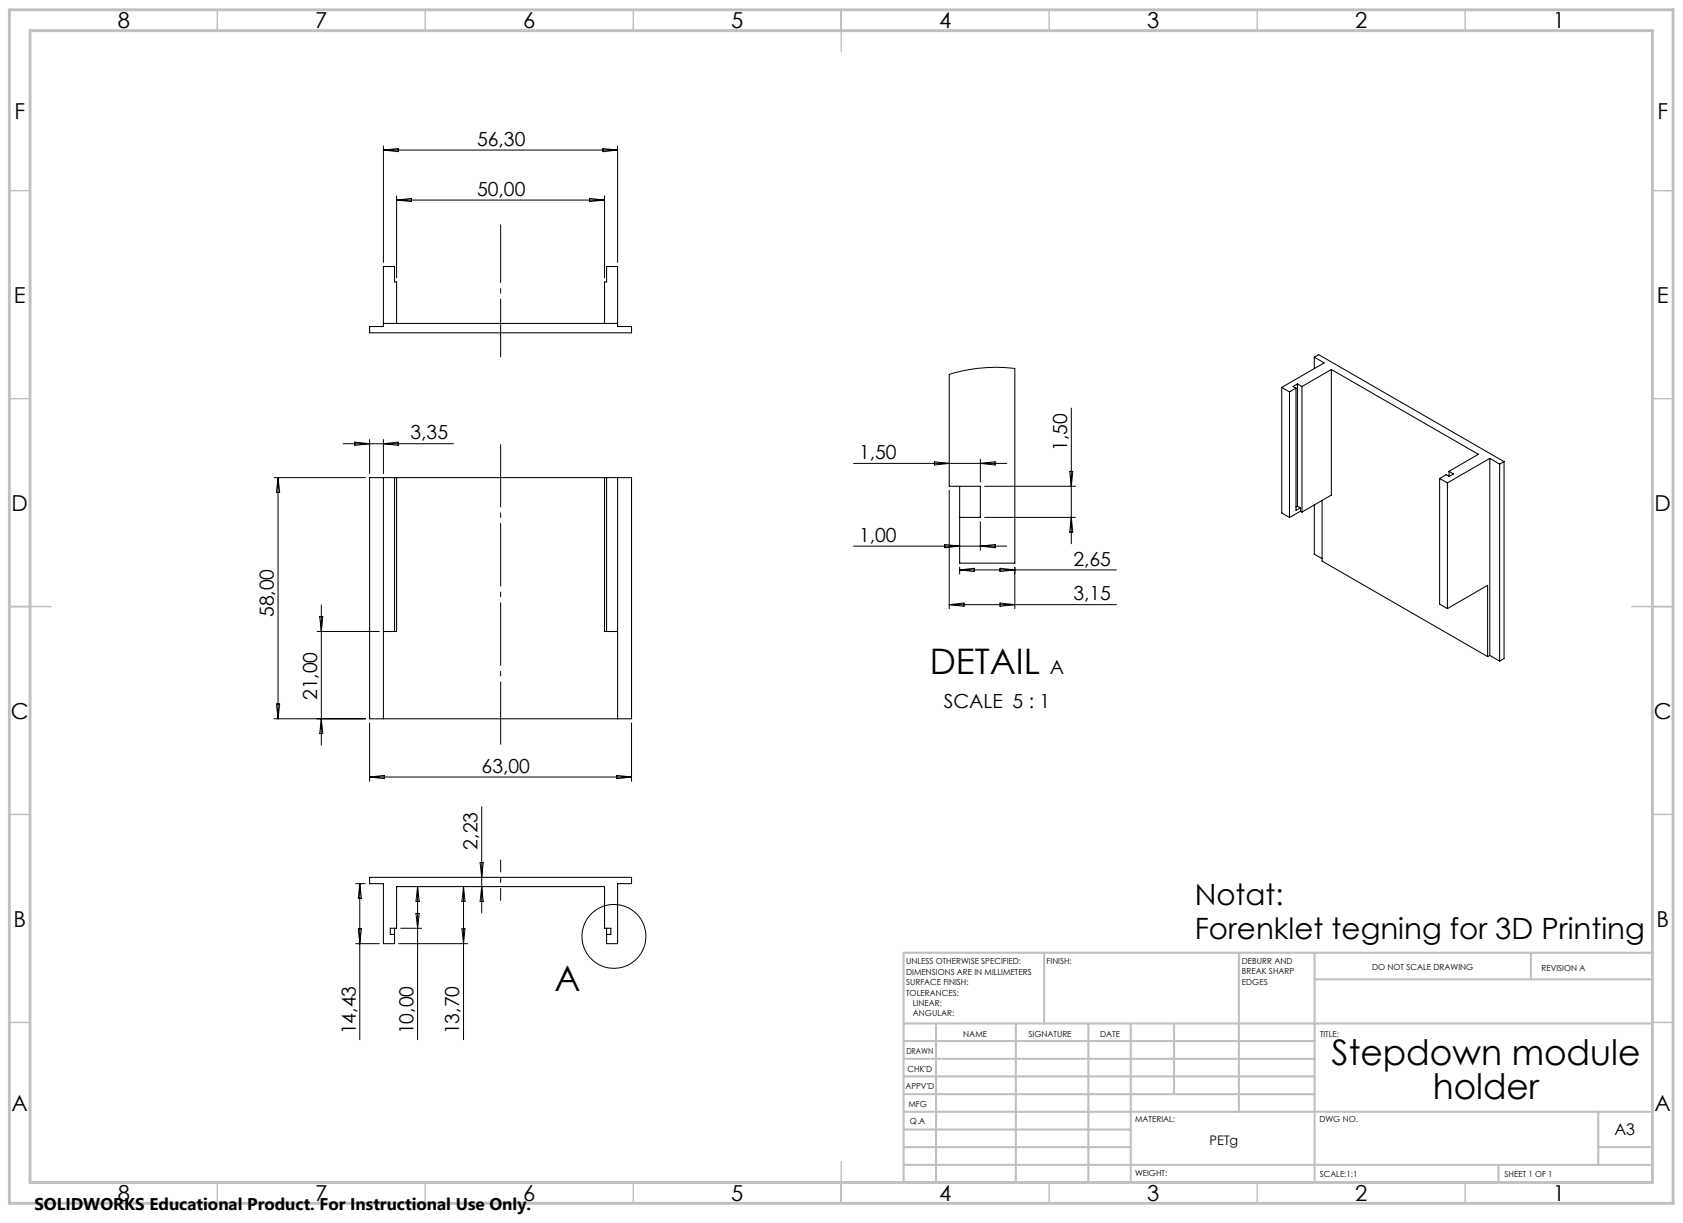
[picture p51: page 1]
DETAIL A; SCALE 5 : 1; FINISH:; DEBURR AND; BREAK SHARP; DO NOT SCALE DRAWING; REVISION A; SCALE:1:1; SHEET 1 OF 1

Notat:
Forenklet tegning for 3D Printing

UNLESS OTHERWISE SPECIFIED:
DIMENSIONS ARE IN MILLIMETERS
SURFACE FINISH:
TOLERANCES:
LINEAR:
ANGULAR:

NAME | SIGNATURE | DATE | | | | TITLE: Stepdown module holder

DRAWN
CHK'D
APPV'D
MFG
Q.A | | | | MATERIAL: PETg | DWG NO. | A3

SOLIDWORKS Educational Product. For Instructional Use Only.

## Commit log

2026-05-19 Create cad/tegninger subfolder
2026-05-19 Create cad/prototypekapsling subfolder
2026-05-19 Create data/filament-datablader folder structure
